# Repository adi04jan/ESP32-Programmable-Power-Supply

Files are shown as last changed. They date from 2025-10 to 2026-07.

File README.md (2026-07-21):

# Voltbench — ESP32-C3 Programmable Power Supply

A three-channel bench power supply controlled over Wi-Fi, built around an **ESP32-C3 Super Mini**. The variable channel uses an LM2596-ADJ buck converter set by an MCP4017 I2C digital potentiometer, driven by a calibration-map "deadbeat" controller: it jumps to the mapped wiper step, verifies with one filtered ADC sample, applies at most one single-step correction, and freezes — no hunting, settled in under a second. Two fixed rails deliver regulated 5 V and 3.3 V. Everything is managed through a dark-themed responsive web UI served directly from the microcontroller — no app, no cloud, no dependencies.

Designed and developed by **Aditya Biswas**.

---

## Screenshots

| Dashboard | History | Settings |
|---|---|---|
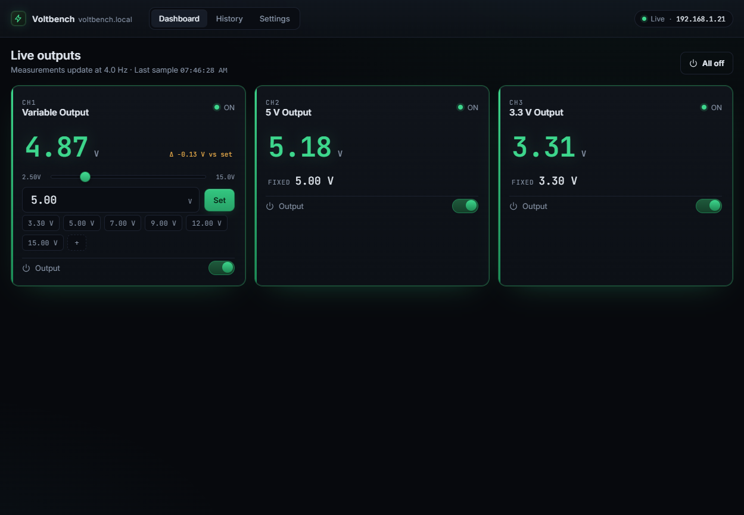
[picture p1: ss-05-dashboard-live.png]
Dashboard
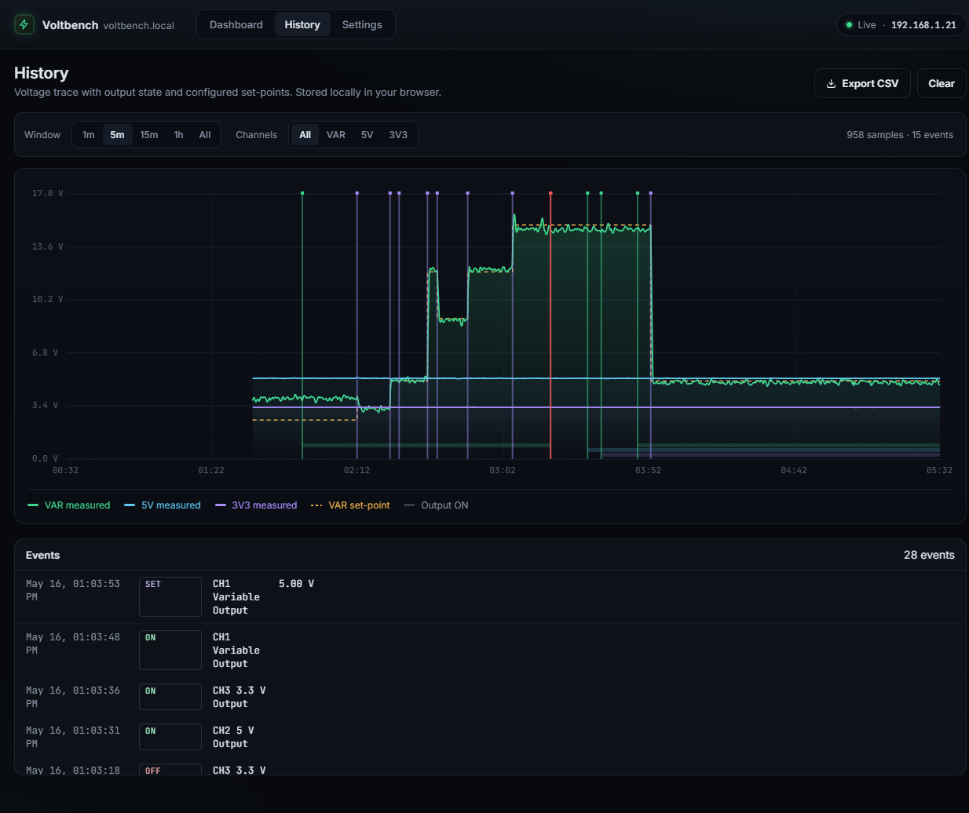
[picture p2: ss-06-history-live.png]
History
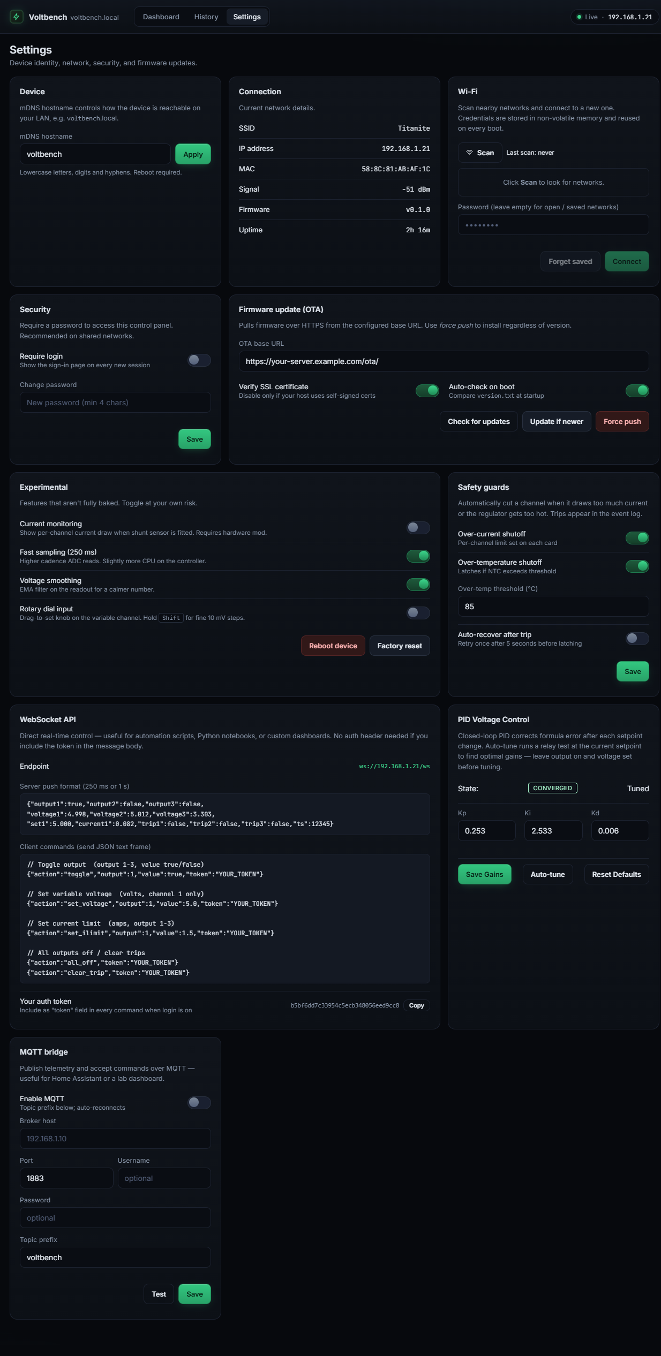
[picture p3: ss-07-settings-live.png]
Settings
|  |  |  |

---

## Features

### Power Outputs
| Channel | Rail | Range | Regulation |
|---|---|---|---|
| CH1 | LM2596-ADJ (variable) | 2.5 V – 15 V | map-based deadbeat control + on-device calibration sweep |
| CH2 | Mini360 (fixed 5 V) | 5.0 V | Passthrough (monitor only) |
| CH3 | LM1117-3.3 (LDO, fixed) | 3.3 V | Passthrough (monitor only) |

### Accuracy (measured, after calibration sweep)
| Setpoint | Measured | Error |
|---|---|---|
| 3.3 V | 3.22 V | −80 mV (2.4%) |
| 5.0 V | 4.99 V | −10 mV (0.2%) |
| 9.0 V | 8.98 V | −20 mV (0.2%) |
| 12.0 V | 12.29 V | +290 mV (2.4%) |
| 15.0 V | 15.55 V | +550 mV (3.7%) |

> Accuracy is limited by wiper-step quantization (~27 mV/step at low voltages, up to ~1 V/step near the ceiling). Run Settings → Calibration → Run sweep once after assembly (CH1 unloaded).

### Web UI
- **Dashboard** — live voltage at 4 Hz, per-channel enable toggles, voltage slider, preset chips (right-click to delete, ＋ to save current), delta indicator, All Off button
- **History** — bezier-smoothed time-series graph with SMA noise reduction, channel filters, event markers (output on/off), adjustable time window (1 min – 12 h)
- **Settings** — mDNS hostname, security/login, Wi-Fi management (scan/connect/forget, stores up to 4 SSIDs), OTA update, experimental flags (dial mode, EMA smoothing, fast poll), MQTT bridge
- **Calibration card** — run/clear the CH1 calibration sweep and see whether a valid map is loaded
- **Device log pane** — live firmware log streamed over a view-only WebSocket (`/logws`)
- **Web-upload OTA** — flash a `.bin` straight from the browser, with real upload/flash progress

### Connectivity
- **WebSocket** `/ws` — server pushes full status JSON at up to 4 Hz; also accepts control commands
- **REST API** — full control and configuration via `/api/*` endpoints
- **mDNS** — reachable at `http://voltbench.local/` on any mDNS-capable host (Windows, macOS, Linux, iOS)
- **Captive portal** — automatically falls back to AP mode (`VoltbenchAP`) when no saved Wi-Fi connects; re-tries every 30 s
- **Telnet console** (`:23`) and USB serial console — single-letter commands: `v<volts>` set CH1, `o1`/`o0` output on/off, `m` run calibration sweep, `c` cal status, `?` full state dump

### Management
- **OTA update** — pulls firmware from this repo's GitHub "latest release" assets on demand or auto-check on boot; web-upload OTA as a second, USB-free path
- **NVS persistence** — all settings, the CH1 calibration map, and Wi-Fi credentials survive power cycles and OTA updates
- **MQTT bridge** — publishes 1 Hz telemetry; subscribes to control topics
- **Factory reset** — wipes all NVS from Settings → Factory Reset
- **Token auth** — optional bearer-token login (stored in `sessionStorage`, persists across reboots)

---

## Hardware

### Bill of Materials

| Component | Part | Notes |
|---|---|---|
| MCU | ESP32-C3 Super Mini | 4 MB flash, Wi-Fi 802.11 b/g/n |
| Variable regulator | LM2596-ADJ module | Adjustable buck, ~3–35 V input |
| Fixed 5 V | Mini360 module | Fixed-output synchronous buck |
| Fixed 3.3 V | LM1117-3.3 | LDO, TO-92 or SOT-223 |
| Digital pot | MCP4017T-103E/LT | 10 KΩ, 128 steps, I2C @ 0x2F |
| R1 (feedback) | 10 KΩ 1% | VOUT → FB (ADJ) on LM2596 |
| R_adc_top | 47 KΩ | CH1 ADC voltage divider high-side |
| R_adc_bot | 1 KΩ | CH1 ADC voltage divider low-side |
| R_5v / R_3v3 | 10 KΩ × 4 | CH2 and CH3 ADC dividers (÷2 each) |
| Enable switches | N-ch MOSFET or relay × 3 | Logic-level control from GPIO 5/6/7 |

### Pin Map

| GPIO | Function |
|---|---|
| 0 | ADC CH1 — variable rail (47K:1K divider, ×48 scale) |
| 1 | ADC CH2 — 5 V rail (10K:10K divider, ×2 scale) |
| 3 | ADC CH3 — 3.3 V rail (10K:10K divider, ×2 scale) |
| 5 | Enable CH1 (variable output) |
| 6 | Enable CH2 (5 V output) |
| 7 | Enable CH3 (3.3 V output) |
| 8 | I2C SDA → MCP4017 |
| 9 | I2C SCL → MCP4017 |

### LM2596-ADJ Feedback Network

```
VOUT ──── 10 KΩ ──── FB (ADJ) ──── MCP4017 wiper ──── GND
                                     (0 – 10 KΩ)
```

`Vout = 1.235 × (1 + 10 000 / R2)` where R2 is the MCP4017 resistance.

| Target | R2 needed | MCP4017 step |
|---|---|---|
| 2.5 V | 9.87 KΩ | 125 / 127 |
| 5.0 V | 3.27 KΩ | 41 / 127 |
| 9.0 V | 1.56 KΩ | 20 / 127 |
| 12.0 V | 1.13 KΩ | 14 / 127 |
| 15.0 V | 0.87 KΩ | 11 / 127 |

### CH1 ADC Divider

```
VOUT ──── 47 KΩ ──── GPIO0 ──── 1 KΩ ──── GND
                       ↑
                  ADC reads here (0 – 2.5 V with ADC_11db)
                  Scale factor = 48 → supports up to ~27 V
```

---

## Firmware

### Prerequisites

- **Arduino IDE 2.x** with ESP32 Arduino core (Espressif) v3.x
- Libraries (Library Manager):
  - `ESPAsyncWebServer` + `AsyncTCP`
  - `ArduinoJson` v7
  - `PubSubClient` *(only if MQTT is needed)*

  (The MCP4017 digital pot is driven with direct I2C register writes — no digital-pot library needed.)

### Build & Flash

1. Clone the repository:
   ```sh
   git clone https://github.com/your-username/ESP32-Programmable-Power-Supply.git
   ```

2. Edit `ESP32_power_supply/credential.h` with your Wi-Fi credentials (these only seed NVS the first time — if any SSID slot is already saved, they're ignored):
   ```cpp
   static const char *ssids[]     = { "YourSSID" };
   static const char *passwords[] = { "YourPassword" };
   ```
   OTA is not configurable here — it's pinned to this repo's GitHub "latest release" assets (see [OTA Updates](#ota-updates)).

3. In Arduino IDE, set:
   - Board: `ESP32C3 Dev Module`
   - Upload Speed: `921600`
   - Flash Size: `4MB`
   - Partition Scheme: **Custom** → select `ESP32_power_supply/partitions.csv`

4. Upload: **Sketch → Upload** (`Ctrl+U`)

5. Open Serial Monitor at **115200 baud** — you should see:
   ```
   Voltbench v3.0.0 booting...
   MCP4017 OK @ 0x2F
   Joined YourSSID — IP=192.168.x.x
   URL: http://voltbench.local/
   ```

6. Open `http://voltbench.local/` in any browser on the same network.

### Partition Layout

```
nvs        20 KB   Settings and Wi-Fi credentials
otadata     8 KB   OTA slot tracking
app0     1792 KB   Active firmware (~1.3 MB used)
app1     1792 KB   OTA staging slot
spiffs    448 KB   Reserved
```

### Regenerating the Web UI

After editing `new design/Power Supply.html`, run this PowerShell snippet to rebuild `web_page.h`:

```powershell
$html  = Get-Content "new design\Power Supply.html" -Raw -Encoding utf8
$bytes = [System.Text.UTF8Encoding]::new($false).GetBytes($html)
$ms    = [System.IO.MemoryStream]::new()
$gz    = [System.IO.Compression.GzipStream]::new($ms, [System.IO.Compression.CompressionLevel]::Optimal)
$gz.Write($bytes, 0, $bytes.Length); $gz.Close()
$gzBytes = $ms.ToArray()
$chunks  = for ($i = 0; $i -lt $gzBytes.Length; $i += 16) {
    "  " + (($gzBytes[$i..([Math]::Min($i+15,$gzBytes.Length-1))] |
    ForEach-Object { "0x{0:x2}" -f $_ }) -join ", ")
}
$header = @("#pragma once","const uint8_t index_html_gz[] PROGMEM = {",
            ($chunks -join ",`n"),"};",
            "const size_t index_html_gz_len = $($gzBytes.Length);")
[System.IO.File]::WriteAllLines("ESP32_power_supply\web_page.h", $header,
    [System.Text.UTF8Encoding]::new($false))
Write-Host "Done: $($bytes.Length) -> $($gzBytes.Length) bytes"
```

---

## Usage

### Calibration

On first flash CH1 has no calibration map, so the deadbeat controller falls back to a coarse built-in estimate. For rated accuracy, run the sweep once:

1. **Disconnect any load from CH1** — the sweep drives the output across its full range (~2.5 V → ceiling) and needs the rail unloaded to read clean.
2. In **Settings → Calibration**, click **Run sweep**. It steps the MCP4017 through all 128 positions, sampling each one — takes about a minute. The busy state is reported as `"busy"` in `/api/status` and rejects a second sweep request while running.
3. The resulting step→millivolt map is smoothed to be monotonic, marked valid, and persisted to NVS — it survives reboots and OTA updates (NVS is a separate flash partition the OTA slot swap never touches).

Re-run the sweep only if the hardware changes (different MCP4017, feedback resistor, or LM2596 module). Use **Clear** to wipe the map and fall back to the coarse estimate.

### Presets

- **Click** a preset chip to jump to that voltage instantly.
- **Right-click** a chip to delete it.
- **＋** saves the current slider position as a new preset (stored in browser `localStorage`).

### All Off

The **All off** button in the top-right cuts all three outputs simultaneously. Individual toggles restore each channel independently.

---

## REST API

All responses are JSON. When `require_login` is enabled, include header `X-Auth: <token>` on every request except `/api/login`.

| Method | Path | Description |
|---|---|---|
| `GET` | `/api/status` | Live voltages and controller state |
| `GET` | `/api/info` | Device info, network, settings |
| `POST` | `/api/login` | `pass=…` → `{ok, token}` |
| `POST` | `/api/control` | Outputs and voltage (see below) |
| `POST` | `/api/settings` | JSON — any subset of settings |
| `GET` | `/api/wifi/scan` | Start scan → returns networks |
| `POST` | `/api/wifi/connect` | `ssid=…&pass=…` |
| `POST` | `/api/wifi/forget` | `ssid=…` |
| `GET` | `/api/ota/check` | Check GitHub for newer firmware (async: `202 {"checking":true}` while in flight) |
| `POST` | `/api/ota/update` | Pull from GitHub if newer |
| `POST` | `/api/ota/force` | Pull from GitHub unconditionally |
| `POST` | `/api/ota/upload` | Multipart `.bin` upload → flashes the inactive OTA slot, reboots on success |
| `POST` | `/api/cal/sweep` | Start the CH1 calibration sweep (`409` if the controller is already busy) |
| `GET` | `/api/cal/status` | `{valid, running, mv:[128 values]}` |
| `POST` | `/api/cal/clear` | Wipe the calibration map |
| `GET` | `/api/mqtt/test` | Test broker connectivity |
| `POST` | `/api/reboot` | Restart device |
| `POST` | `/api/factory_reset` | Wipe NVS |

**`/api/control` actions** (form-encoded POST body):
```
action=toggle&output=1&value=1
action=set_voltage&output=1&value=5.0
action=all_off
```

**`/api/status` example:**
```json
{
  "output1": true,  "output2": false, "output3": false,
  "voltage1": 4.99, "voltage2": 5.17, "voltage3": 3.31,
  "set1": 5.0,
  "cal": true,
  "state": "frozen",
  "ts": 8040468
}
```

`state`: `idle` | `settling` | `verifying` | `frozen` | `busy` (`busy` = calibration sweep in progress). `voltage1` is the median-of-5 display value; `cal` reports whether a valid calibration map is loaded.

`/api/info` unauthenticated returns `{fw, mdns, require_login, captive}`; with a valid token it adds `ip, mac, ssid, rssi, uptime, ota:{auto}, exp:{fast,smooth,dial}, mqtt:{…}, saved_ssids, vmax`.

---

## WebSocket

Connect to `ws://voltbench.local/ws`.

The server **pushes** a full status frame automatically — every 250 ms with the fast-poll flag on, every 1 s otherwise — no subscription needed. `ws://voltbench.local/logws` is a second, view-only socket that streams the live firmware debug log (used by the Device log pane).

**Send a control command:**
```json
{ "action": "set_voltage", "output": 1, "value": 9.0 }
{ "action": "toggle",      "output": 1, "value": true }
{ "action": "all_off" }
```

When `require_login` is on, include `"token": "<token>"` in every command.

**Quick test (browser console):**
```js
const ws = new WebSocket('ws://voltbench.local/ws');
ws.onmessage = e => console.log(JSON.parse(e.data));
ws.onopen    = () => ws.send(JSON.stringify({action:'set_voltage', output:1, value:5.0}));
```

---

## MQTT

Enable in **Settings → MQTT**. Configure broker host, port, credentials, and topic prefix.

| Topic | Direction | Payload |
|---|---|---|
| `voltbench/tele` | Publish (1 Hz) | Full JSON telemetry (same shape as `/api/status`) |
| `voltbench/status` | Publish (retained, on connect) | `online` |
| `voltbench/cmd/ch1/output` | Subscribe | `on` / `off` / `1` / `0` |
| `voltbench/cmd/ch2/output` | Subscribe | `on` / `off` / `1` / `0` |
| `voltbench/cmd/ch3/output` | Subscribe | `on` / `off` / `1` / `0` |
| `voltbench/cmd/ch1/voltage` | Subscribe | Float string, e.g. `5.0` — clamped to `[0, 16]`, invalid channels/values are silently ignored |

The prefix `voltbench` is configurable in Settings → MQTT → Topic prefix. Only CH1 accepts a voltage command (CH2/CH3 are fixed rails); toggling CH2/CH3 output is still valid.

---

## OTA Updates

Two independent paths, no local server required:

1. **Pull-OTA from GitHub** — the base URL is pinned in firmware to this repo's `/releases/latest/download/` assets (HTTPS, **without** certificate verification — `WiFiClientSecure::setInsecure()` is used deliberately; there's no local CA store on this MCU, and this is an accepted trade-off, not an oversight). The device fetches `version.txt`, compares it to `CURRENT_FIRMWARE_VERSION`, and — on `/api/ota/update`, `/api/ota/force`, or the optional auto-check on boot — downloads `firmware_<version>.bin` into the inactive OTA slot and reboots on success. To ship a release: tag it, then attach `version.txt` and `firmware_<version>.bin` to the GitHub release; `/releases/latest/download/` resolves automatically.
2. **Web-upload OTA** — `POST` a compiled `.bin` to `/api/ota/upload` (multipart, e.g. `curl -H "X-Auth: <token>" -F "f=@ESP32_power_supply.ino.bin" http://voltbench.local/api/ota/upload`), or use the **Update** button in Settings for the same flow with a progress bar. No GitHub, no USB.

Either path rejects a second update while one is already running (logged as `busy`).

---

## Architecture

```
┌────────────────────────────────────────────────────┐
│  ESP32-C3  (FreeRTOS, single physical core)        │
│                                                    │
│  ┌──────────────────────┐  volatile globals         │
│  │  voltageControlTask  │◄────────────────────────┐ │
│  │  (priority 2, core 0)│  g_target_mV            │ │
│  │                      │  g_setpoint_mV          │ │
│  │  deadbeat state      │  g_measured_mV          │ │
│  │  machine: idle →     │  g_display_mV  ────────►│ │
│  │  settling → verify   │  g_5v_mV / g_3v3_mV     │ │
│  │  → frozen (or busy   │  g_vctrl_state          │ │
│  │  during cal sweep)   │  g_cal_mv[128] / valid  │ │
│  │  ADC reads (all 3    │                         │ │
│  │  rails) + I2C pot    │                         │ │
│  └──────────────────────┘                         │ │
│                                                   │ │
│  ┌──────────────────────┐                         │ │
│  │  AsyncWebServer      │─────────────────────────┘ │
│  │  ESPAsyncWebServer   │  Reads the globals above  │
│  │                      │  Writes g_target_mV       │
│  │  /api/* handlers     │                           │
│  │  WebSocket push      │                           │
│  └──────────────────────┘                           │
│                                                     │
│  loop():  vb_loop()                                 │
│     DNS captive · WS push · MQTT · OTA · console    │
└────────────────────────────────────────────────────┘
        │ I2C                │ ADC_11db
    MCP4017 @ 0x2F        GPIO 0 / 1 / 3
    10 KΩ, 128 steps      ×48 / ×2 / ×2
        │
   LM2596-ADJ
   feedback R2
```

**Key design decisions:**
- `voltageControlTask` owns ALL ADC sampling (all three rails) and the I2C pot; web handlers read atomically-written globals only. Status reads use `g_display_mV`, a median-of-5 window snapped on freeze for a calm steady-state number.
- The controller is a calibration-map deadbeat, not a feedback loop: predict the wiper step from `g_cal_mv[]`, wait 300 ms to settle, take one ~200 ms filtered verify sample, apply at most one ±1-step correction, then freeze (`g_vctrl_state`: idle → settling → verifying → frozen). No PID, no hunting, no per-cycle recomputation — settled in under a second across the full range. Without a calibration map it falls back to a coarse built-in R↔step estimate.
- The web UI is a single gzip-compressed HTML file (~23 KB) served directly from PROGMEM — no filesystem partition required.

---

## Troubleshooting

| Symptom | Cause | Fix |
|---|---|-----|
| `voltbench.local` not resolving | mDNS client issue | Try IP directly; Android needs an mDNS helper app |
| Voltage shows 0 V with output OFF | Expected — enable pin cuts power | Toggle output ON |
| CH1 settles far from setpoint | No calibration map — coarse fallback estimate in use | Run Settings → Calibration → Run sweep (CH1 unloaded) |
| OTA "check" never returns `newer` | No release published yet, or `version.txt`/`.bin` missing from the GitHub release | Confirm the tag's release has both assets attached |
| `MCP4017 not found!` at boot | I2C wiring | Check SDA/SCL and pull-up resistors (4.7 KΩ to 3.3 V) |
| Sketch too large to upload | Wrong partition scheme | Select Custom and point to `partitions.csv` |
| Settings revert after save | Browser cached old page | Hard-refresh (`Ctrl+Shift+R`) |

---

## License

MIT — see [LICENSE](LICENSE).

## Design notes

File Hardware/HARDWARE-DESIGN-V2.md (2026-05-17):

# Voltbench v2 — Hardware Design

> Two-channel programmable bench power supply.  
> Input: 24 V DC SMPS · Output: 2.8 V – 20 V · 3 A per channel  
> Control: ESP32-C3 · I²C DAC (MCP4728) · Discrete PMOS LDO · INA219 sensing

---

## Table of Contents

1. [Why v2?](#why-v2)
2. [System Overview](#system-overview)
3. [Stage 1 — Coarse Voltage (MP1584 + MCP4728)](#stage-1--coarse-voltage-mp1584--mcp4728)
4. [Stage 2 — Precision LDO (FQP27P06 + LM358)](#stage-2--precision-ldo-fqp27p06--lm358)
5. [Stage 3 — Measurement (INA219)](#stage-3--measurement-ina219)
6. [Complete Single-Channel Schematic](#complete-single-channel-schematic)
7. [Two-Channel Full System](#two-channel-full-system)
8. [I²C Address Map](#i2c-address-map)
9. [Power Budget](#power-budget)
10. [Thermal Design](#thermal-design)
11. [Bill of Materials](#bill-of-materials)
12. [PCB Design Notes (0.25 mm CNC)](#pcb-design-notes-025-mm-cnc)
13. [Firmware Interface](#firmware-interface)
14. [System Specifications](#system-specifications)

---

## Why v2?

### Problems with v1 (LM2596 + MCP4017)

| Problem | Root Cause | Impact |
|---|---|---|
| ±400–800 mV voltage error | MCP4017 has 128 steps × 78.7 Ω/step | Cannot hit target precisely |
| PID loop needed | Step size larger than tolerance band | Slow settling, overshoot risk |
| No current measurement | No sense circuit | Cannot display watts or enforce OCP |
| Noisy ADC readings | ESP32-C3 internal ADC non-linearity | Inaccurate voltage display |
| 75% efficiency | LM2596 150 kHz non-synchronous switcher | Heat, large inductor/caps |

### v2 Solution

```
v1:  LM2596 (variable R2 via MCP4017)  →  ±400 mV error, slow PID
v2:  MP1584 (DAC FB injection)         →  coarse set, instant, ~3 mV resolution
     + PMOS LDO (op-amp regulated)     →  fine regulation, 2–5 mV ripple
     + INA219                          →  accurate V + I measurement
```

---

## System Overview

```
                       24V DC SMPS
                            │
              ┌─────────────┼─────────────┐
              │             │             │
              ▼             ▼             ▼
          [CHANNEL 1]   [CHANNEL 2]   [ESP32-C3]
                                          │
                                     I²C Bus (SDA/SCL)
                                     ┌────┴──────┐
                                  MCP4728      INA219×2
                                  (0x60)    (0x40, 0x41)
```

### Per-Channel Signal Flow

```
24V ──► [MP1584 Buck] ──► [FQP27P06 PMOS] ──► OUTPUT TERMINAL
              ▲                   ▲
              │ FB injection       │ Gate drive
         MCP4728 Ch A          LM358 op-amp ◄── MCP4728 Ch B
         (coarse set)          (fine regulate)        (reference)
                                      ▲
                               Vout feedback
                               divider (10k/51k)
                                      │
                               ──[0.1Ω shunt]──
                                      │
                                  INA219
                                (V + I sense)
```

---

## Stage 1 — Coarse Voltage (MP1584 + MCP4728)

### How It Works

The MP1584 is a synchronous buck converter with an adjustable output set by its FB (feedback) pin. Normally R1 and R2 form a divider to set output voltage. We **inject current from the MCP4728 DAC through R3** into the FB node, which shifts the output voltage continuously and linearly.

The FB pin is always regulated to **Vref = 0.8 V** by the MP1584's internal error amplifier. Injecting current via R3 forces the converter to change Vout to maintain that 0.8 V at FB.

### Feedback Network Schematic

```
                          MP1584
                         ┌──────┐
              ┌──────────┤ FB   │
              │          └──────┘
              │
Vout_mp1584 ──┤──[R1 = 100 kΩ]──┐
              │                   │
              ├──[R2 = 6.8 kΩ]── GND
              │
              └──[R3 = 24.3 kΩ]──── MCP4728 Channel A (0–3.3 V)
```

### Transfer Function

```
Vout = 0.8 × (1 + R1/R2 + R1/R3)  −  Vdac × (R1/R3)

With R1=100k, R2=6.8k, R3=24.3k:
  Vout = 16.0  −  4.09 × Vdac
```

### DAC Code to Output Voltage

```
Vdac = (16.0 − Vout_target) / 4.09
DAC_code = round(Vdac × 4096 / 3.3)
```

| Target Vout + 0.5V | Vdac | DAC Code |
|---|---|---|
| 20.5 V | 0.00 V | 0 |
| 15.5 V | 0.12 V | 1218 |
| 12.5 V | 0.49 V | 1211 (coarse MP1584 target) |
| 9.5 V | 1.59 V | 1973 |
| 5.5 V | 2.56 V | 3176 |
| 3.3 V | 3.10 V | 3846 |

> MP1584 is set to **Vtarget + 0.5 V** — the LDO stage drops the final 0.5 V precisely.

### MP1584 Support Components

```
               24V
                │
           [10µF ceramic]  ← Input decoupling
                │
         ┌──────┴──────┐
         │   MP1584    │
    EN ──┤EN       OUT ├──┬──[L1: 4.7µH]──┬── To PMOS source
         │             │  │               │
         │         SW  ├──┘            [C1: 22µF] ← Output cap
         │             │               ceramic
         └──────┬──────┘               │
               GND                    GND
                         [D1: SS34 Schottky] ← Freewheeling diode
                         (SW to GND, for transient protection)
```

| Component | Value | Notes |
|---|---|---|
| L1 | 4.7 µH, 4A rated | Smaller than LM2596's 100 µH |
| C1 (output) | 22 µF ceramic | MP1584 stability |
| C_in | 10 µF ceramic | Input decoupling |
| D1 | SS34 Schottky | Optional (synchronous but helps transients) |

---

## Stage 2 — Precision LDO (FQP27P06 + LM358)

### How It Works

The PMOS transistor (FQP27P06) sits between the MP1584 output and the final output terminal. An op-amp (LM358) compares a divided-down version of the actual output voltage against a **DAC reference (MCP4728 Channel B)**. It drives the PMOS gate to force the output to exactly match the reference.

This eliminates the MP1584's ±1% Vref tolerance error, load regulation error, and most of the switching ripple.

### LDO Schematic

```
MP1584 out (Vtarget+0.5V)
        │
        ├── PMOS Source (FQP27P06 pin 3)
        │
        │       FQP27P06 (P-Channel MOSFET)
        │      ┌─────────────┐
        └──────┤ S           │
               │    D        ├──────────────┬── Vout (clean)
               │             │              │
               └─────────────┘          [100µF]   [10µF]
                      │ G                   │         │
                   [100Ω]                  GND       GND
                      │
               ┌──────┴──────┐
               │   LM358     │
               │  op-amp     │
         Vfb ──┤ −IN   OUT   ├── Gate drive
               │             │
  DAC ref ─────┤ +IN         │
               └─────────────┘
                      │
                     GND (op-amp GND)
                     Vcc = 24V (op-amp supply)

Vfb comes from output voltage divider:

Vout ──[Ra = 10 kΩ]──┬── to op-amp −IN
                      │
                   [Rb = 51 kΩ]
                      │
                     GND
```

### Transfer Function

```
Op-amp null condition (Vout settled):
  DAC_ref = Vout × Ra / (Ra + Rb)

Solving for Vout:
  Vout = DAC_ref × (Ra + Rb) / Ra
       = DAC_ref × (10k + 51k) / 10k
       = DAC_ref × 6.1

DAC code for target:
  DAC_ref = Vout_target × 10 / (10 + 51)  = Vout_target × 0.1639
  DAC_code = round(DAC_ref × 4096 / 3.3)
```

| Target Vout | DAC Ref | DAC Code |
|---|---|---|
| 20.0 V | 3.28 V | 4070 |
| 15.0 V | 2.46 V | 3052 |
| 12.0 V | 1.97 V | 2446 |
| 9.0 V | 1.47 V | 1827 |
| 5.0 V | 0.82 V | 1018 |
| 3.3 V | 0.54 V | 671 |
| 2.8 V | 0.46 V | 571 |

### Why PMOS and Not NPN/NMOS?

```
NPN/NMOS (source follower):
  Vout = Vgate − Vgs_threshold   ← output always lower than gate
  Hard to use at high side without charge pump

PMOS (common source, source at top):
  Source = Vin (high side)
  Gate pulled LOW turns it ON
  Op-amp can drive gate from 0V (full ON) to 24V (full OFF)
  No charge pump needed ✓
```

### Op-Amp Operating Range Check (LM358 at 24V supply)

```
Source voltage: 0.5V to 20.5V (MP1584 output range)
Gate must swing BELOW source to turn ON:
  At Vsource = 20.5V: gate needs to go to ~17V (Vgs = -3.5V → fully ON)
  LM358 output max = Vcc - 1.5V = 22.5V  > 20.5V ✓ (can turn OFF)
  LM358 output min = 0V  <  17V needed to turn ON  ✓

At Vsource = 3.3V: gate needs ~1V to fully ON
  LM358 output = 0 to ~22.5V  →  easily covers 0–1V ✓
```

### Dropout Voltage

```
Vdropout = Rdson × Iout
         = 0.070 Ω × 3 A  =  0.21 V  (typical)
         = 0.100 Ω × 3 A  =  0.30 V  (worst case, warm)

MP1584 headroom set to 0.5V → leaves 0.2–0.3V regulation margin ✓
```

---

## Stage 3 — Measurement (INA219)

### How It Works

The INA219 measures both **bus voltage** (actual output voltage, 4 mV resolution) and **shunt current** (via 0.1 Ω resistor, 1 mA resolution) over I²C. This replaces the ESP32's internal ADC entirely.

### Connection

```
                 Vout (before shunt)
                         │
                    ┌────┴────┐
                    │ INA219  │
                    │         │
              IN+ ──┤         ├── SDA ── I²C Bus
              IN− ──┤         ├── SCL ── I²C Bus
                    │         ├── VCC ── 3.3V
                    │         ├── GND ── GND
                    │    A0   ├── (address select)
                    │    A1   ├── (address select)
                    └─────────┘
                         │
                    [0.1 Ω shunt, 1W, 2512]
                         │
                    Output Terminal (+)
```

### Address Configuration

| Channel | A0 | A1 | I²C Address |
|---|----|----|---|
| Ch 1 | GND | GND | 0x40 |
| Ch 2 | VCC | GND | 0x41 |

### INA219 Calibration Register

```
For 0.1 Ω shunt, max 3.2 A, current LSB = 100 µA:
  Cal = 0.04096 / (Current_LSB × Rshunt)
      = 0.04096 / (0.0001 × 0.1)
      = 4096

Write 0x1000 to calibration register.
```

---

## Complete Single-Channel Schematic

```
                             24V DC SMPS
                                  │
          ┌───────────────────────┼────────────────────────────────┐
          │                       │                                │
       [10µF]                     │                             [100nF]
          │                       │                                │
         GND                      │                               GND
                                  │
                    ┌─────────────┴──────────────────┐
                    │           MP1584                │
         GPIO_EN ───┤ EN                              │
                    │                            IN   ├── 24V
          ┌─────────┤ FB                              │
          │         │                         SW      ├──┐
          │         └─────────────────────────────────┘  │
          │                                               │
          │  Feedback Network:                         [L1: 4.7µH, 4A]
          │                                               │
Vmp ──────┼──[R1: 100kΩ]──────── Vout_mp1584 ────────────┤
          │                          (Vtgt+0.5V)          │
          ├──[R2: 6.8kΩ]──── GND                      [C1: 22µF]
          │                                               │
          └──[R3: 24.3kΩ]─── MCP4728 Ch A (coarse)      GND
                                                          │
                                               Vout_mp1584 (Vtgt+0.5V)
                                                          │
                                           ┌──────────────┘
                                           │ Source
                                    ┌──────┴──────┐
                                    │  FQP27P06   │ (P-Ch MOSFET)
                                    │  TO-220     │
                                    └──────┬──────┘
                                           │ Drain
                              ┌────────────┼────────────┐
                              │            │            │
                           [100µF]      [10µF]       [100nF]
                              │            │            │
                             GND          GND          GND
                              │
                         Vout_clean
                              │
                   ┌──────────┴──────────┐
                   │                     │
              [Ra: 10kΩ]         [0.1Ω shunt, 1W]
                   │                     │
              [Rb: 51kΩ]          Output Terminal (+)
                   │
                  GND               ┌────────────────┐
                   │                │    INA219      │
              Vfb (0–3.3V)    IN+ ──┤                ├── SDA
                   │          IN- ──┤  0x40 / 0x41   ├── SCL
                   │                │                ├── 3.3V
                   │               GND               └────────────────┘
                   │
            ┌──────┴──────────┐
            │    LM358        │
            │   (Vcc = 24V)   │
     Vfb ───┤ −IN    OUT      ├──[100Ω]── Gate (FQP27P06)
            │                 │
DAC_ref ────┤ +IN             │
(MCP4728    │                 │
   Ch B)    └─────────────────┘
                   │
       [10nF cap from OUT to −IN for stability]
```

---

## Two-Channel Full System

```
                              24V DC SMPS
                                   │
            ┌──────────────────────┼──────────────────────┐
            │                      │                      │
     ┌──────┴──────┐        ┌──────┴──────┐        ┌──────┴──────┐
     │  CHANNEL 1  │        │  CHANNEL 2  │        │  ESP32-C3   │
     │             │        │             │        │             │
     │  MP1584     │        │  MP1584     │        │  SDA ───────┼──┐
     │  FQP27P06   │        │  FQP27P06   │        │  SCL ───────┼──┤
     │  LM358      │        │  LM358      │        │  GPIO5 ─────┼──┼── EN_CH1
     │  INA219     │        │  INA219     │        │  GPIO6 ─────┼──┼── EN_CH2
     │  (0x40)     │        │  (0x41)     │        └─────────────┘  │
     └──────┬──────┘        └──────┬──────┘                         │
            │ SDA/SCL              │ SDA/SCL                         │
            └──────────────────────┴─────────────────────────────────┘
                                   │
                              I²C Bus
                                   │
                           ┌───────┴───────┐
                           │   MCP4728     │  SOIC-10
                           │   (0x60)      │
                           │               │
                    Ch A ──┤               ├── SDA
                    Ch B ──┤               ├── SCL
                    Ch C ──┤               ├── VCC (3.3V)
                    Ch D ──┤               ├── GND
                           └───────────────┘
                             │    │    │    │
                          MP1584 LDO MP1584 LDO
                           ref   ref   ref  ref
                           Ch1   Ch1   Ch2  Ch2
```

### MCP4728 Channel Assignment

| MCP4728 Ch | Function | Target IC | What it controls |
|---|---|---|---|
| A | Ch1 Coarse | MP1584 #1 | Sets MP1584 out to Vtarget + 0.5V |
| B | Ch1 Fine | LM358 #1 | Sets exact Vtarget for LDO |
| C | Ch2 Coarse | MP1584 #2 | Sets MP1584 out to Vtarget + 0.5V |
| D | Ch2 Fine | LM358 #2 | Sets exact Vtarget for LDO |

---

## I²C Address Map

| IC | Address | Set by | Notes |
|----|---|---|---|
| MCP4728 | 0x60 | Factory (A0T variant) | Quad DAC |
| INA219 Ch1 | 0x40 | A0=GND, A1=GND | Voltage + current Ch1 |
| INA219 Ch2 | 0x41 | A0=VCC, A1=GND | Voltage + current Ch2 |

No address conflicts. All four ICs on a single SDA/SCL pair.

---

## Power Budget

### SMPS Sizing

```
Per channel, worst case (3A at any voltage):
  Stage 1 (MP1584):
    Vin=24V, Vout=20.5V, Iout=3A
    Pout = 20.5 × 3 = 61.5W
    Pin  = 61.5 / 0.93 = 66.1W
    Ploss = 4.6W  (MP1584 gets warm — copper pour heatsink on PCB)

  Stage 2 (PMOS LDO):
    Pdrop = (20.5 − 20.0) × 3 = 1.5W  (always 0.5V × Iout)

  Per channel total: 66.1W input from 24V
  Two channels max: 132W

Minimum SMPS: 24V / 6A = 144W
Recommended SMPS: 24V / 7A = 168W (Mean Well LRS-150-24 or equivalent)
```

### Typical Operating Power

```
Both channels at 5V / 1A each (common bench use):
  MP1584: (5.5 × 1) / 0.93 = 5.9W per channel
  PMOS:   0.5 × 1 = 0.5W per channel
  Total input: ~13W from 24V rail → 0.54A from SMPS
  A 24V/2A adapter is enough for light loads
```

---

## Thermal Design

### FQP27P06 (PMOS)

```
Power dissipated = 0.5V × Iout (constant regardless of output voltage)

At 3A: P = 1.5W per channel
At 1A: P = 0.5W per channel

TO-220 without heatsink: θja = 62°C/W
  At 1.5W: ΔT = 93°C  →  junction = 118°C  ✗ Too hot

TO-220 with small clip heatsink: θja ≈ 15°C/W
  At 1.5W: ΔT = 22°C  →  junction = 47°C  ✓

Recommendation: use a 25×25mm aluminium heatsink with thermal paste.
```

### MP1584

```
Power loss is highest at large Vin-to-Vout ratio:
At Vout=3.3V, Iin_avg ≈ Iout × (Vout/Vin) / η = 3 × (3.3/24) / 0.93 ≈ 0.44A from 24V
MP1584 internal dissipation ≈ 0.6W

At Vout=20V, Iin_avg ≈ 3 × (20.5/24) / 0.93 ≈ 2.76A from 24V
MP1584 internal dissipation ≈ 4.6W  →  needs copper pour (SOIC-8 exposed pad)

Recommendation: Connect SOIC-8 exposed pad to a copper pour of at least 4 cm²
```

### LM358

```
Op-amp quiescent current: ~1mA at 24V = 24mW  →  negligible, no heatsink needed.
```

---

## Bill of Materials

### Per Channel

| Ref | Component | Value / Part | Package | Qty | Notes |
|-----|---|---|---|-----|---|
| U1 | Buck converter | MP1584EN | SOIC-8 | 1 | |
| Q1 | PMOS pass transistor | FQP27P06 | TO-220 | 1 | Needs heatsink |
| U2 | Op-amp | LM358 | SOIC-8 or DIP-8 | 1 | |
| U3 | Current/voltage sense | INA219xAIDR | SOIC-8 | 1 | |
| R1 | FB upper resistor | 100 kΩ 1% | 0805 | 1 | |
| R2 | FB lower resistor | 6.8 kΩ 1% | 0805 | 1 | |
| R3 | DAC injection resistor | 24.3 kΩ 1% | 0805 | 1 | Use 24.3k or 24k |
| Ra | LDO divider upper | 10 kΩ 1% | 0805 | 1 | |
| Rb | LDO divider lower | 51 kΩ 1% | 0805 | 1 | |
| Rg | Gate resistor | 100 Ω | 0805 | 1 | Prevents oscillation |
| Rc | Stability cap resistor | 10 nF | 0805 | 1 | Op-amp feedback cap |
| Rs | Shunt resistor | 0.1 Ω 1W 1% | 2512 | 1 | Current sense |
| L1 | Inductor | 4.7 µH 4A | SMD | 1 | e.g. SRR1260-4R7Y |
| C1 | MP1584 output cap | 22 µF 35V | 0805/1206 ceramic | 1 | |
| C2 | Input decoupling | 10 µF 35V | 1206 ceramic | 1 | |
| C3 | LDO output cap | 100 µF 35V | Electrolytic | 1 | |
| C4 | LDO HF bypass | 10 µF ceramic | 1206 | 1 | In parallel with C3 |
| C5 | LDO HF bypass | 100 nF ceramic | 0805 | 1 | In parallel with C3 |

### Shared (Both Channels)

| Ref | Component | Value / Part | Package | Qty |
|-----|---|---|---|-----|
| U4 | Quad DAC | MCP4728A0T | SOIC-10 | 1 |
| U5 | Microcontroller | ESP32-C3 Super Mini | Module | 1 |
| J1 | Power input | DC barrel or screw terminal 24V | — | 1 |
| J2,J3 | Output terminals | Banana jack or screw terminal | — | 2 |

### Estimated Cost (India)

| Item | Approx Cost |
|---|---|
| MP1584 × 2 | ₹60 |
| FQP27P06 × 2 | ₹80 |
| LM358 × 2 | ₹30 |
| INA219 × 2 | ₹160 |
| MCP4728 | ₹120 |
| Inductors × 2 | ₹80 |
| Resistors + caps | ₹50 |
| Heatsinks × 2 | ₹40 |
| ESP32-C3 | ₹200 |
| PCB (FR4, milled) | ₹0 (self-milled) |
| **Total** | **~₹820** |

---

## PCB Design Notes (0.25 mm CNC)

### Component Package Analysis

| Component | Package | Min pad gap | 0.25mm bit |
|---|---|---|---|
| MP1584 | SOIC-8 | 0.67 mm | ✓ Comfortable |
| INA219 | SOIC-8 | 0.67 mm | ✓ Comfortable |
| MCP4728 | SOIC-10 | 0.67 mm | ✓ Comfortable |
| LM358 | SOIC-8 | 0.67 mm | ✓ Comfortable |
| FQP27P06 | TO-220 | 2.54 mm | ✓ Easy |
| Resistors | 0805 | 0.50 mm | ✓ Fine |
| Shunt Rs | 2512 | 1.50 mm | ✓ Easy |

> All packages are safely within the 0.25 mm bit capability (no SOT-23 ICs in this design).

### PCB Layout Priorities

```
1. Power path (24V → MP1584 → PMOS → output terminal):
   Use 2mm+ track width. Copper pour recommended.

2. MP1584 SW node:
   Keep short and away from analog components.
   The switch node is the noisiest point in the design.

3. INA219 shunt resistor placement:
   Place shunt resistor close to INA219 IN+/IN- pins.
   Kelvin (4-wire) connection if possible for accuracy.

4. LM358 feedback loop:
   Keep Ra/Rb close to op-amp −IN pin.
   Keep 10nF stability cap (Rc) across Rb.

5. Decoupling capacitors:
   Place C_in (10µF) within 3mm of MP1584 IN pin.
   Place C1 (22µF) within 5mm of MP1584 OUT pin.
   Place C3/C4/C5 right at output terminal.

6. I²C bus:
   Keep SDA/SCL tracks short (<10cm).
   Add 4.7kΩ pull-ups to 3.3V if not already on ESP32 module.

7. PMOS heatsink:
   TO-220 mounted to edge of PCB with external heatsink,
   or use PCB copper pour on drain pad if using D2PAK version.
```

### Recommended Track Widths

| Signal | Track Width | Notes |
|---|---|---|
| 24V power | 2.5 mm | Input supply |
| MP1584 output | 2.0 mm | Up to 3A |
| Output terminal | 2.5 mm | Final output |
| SW node | 1.5 mm | Short as possible |
| I²C (SDA/SCL) | 0.4 mm | Signal only |
| FB network | 0.3 mm | High impedance |
| GND copper pour | Full pour | Both layers |

---

## Firmware Interface

### Setting Output Voltage

```cpp
#include <Adafruit_MCP4728.h>
#include <Adafruit_INA219.h>

Adafruit_MCP4728 dac;
Adafruit_INA219 ina[2] = { Adafruit_INA219(0x40),
                            Adafruit_INA219(0x41) };

// Channel index: 0 = Ch1, 1 = Ch2
void set_voltage(uint8_t ch, float target_V) {
    // Coarse: MP1584 set to Vtarget + 0.5V
    float v_coarse = target_V + 0.5f;
    float vdac_c = (16.0f - v_coarse) / 4.09f;
    uint16_t code_c = (uint16_t)constrain(vdac_c * 4096.0f / 3.3f, 0, 4095);

    // Fine: LDO reference = Vtarget × divider ratio
    float vdac_f = target_V * 10.0f / (10.0f + 51.0f);
    uint16_t code_f = (uint16_t)constrain(vdac_f * 4096.0f / 3.3f, 0, 4095);

    // MCP4728: Ch A/C = coarse, Ch B/D = fine
    MCP4728_channel_t ch_coarse = (ch == 0) ? MCP4728_CHANNEL_A : MCP4728_CHANNEL_C;
    MCP4728_channel_t ch_fine   = (ch == 0) ? MCP4728_CHANNEL_B : MCP4728_CHANNEL_D;

    dac.setChannelValue(ch_coarse, code_c);
    dac.setChannelValue(ch_fine,   code_f);
}

// Read actual voltage (V)
float read_voltage(uint8_t ch) {
    return ina[ch].getBusVoltage_V();
}

// Read actual current (mA)
float read_current(uint8_t ch) {
    return ina[ch].getCurrent_mA();
}

// Read power (mW)
float read_power(uint8_t ch) {
    return ina[ch].getPower_mW();
}
```

### Initialization

```cpp
void setup() {
    Wire.begin();

    // Init DAC — set both channels to safe starting point (3.3V output)
    dac.begin(0x60);
    set_voltage(0, 3.3f);
    set_voltage(1, 3.3f);
    // Save to EEPROM so power-up is safe next time
    dac.saveToEEPROM();

    // Init INA219
    ina[0].begin();
    ina[1].begin();
    ina[0].setCalibration_32V_2A();  // or custom calibration
    ina[1].setCalibration_32V_2A();
}
```

### Enable / Disable Outputs

```cpp
#define EN_CH1  5   // GPIO5
#define EN_CH2  6   // GPIO6

void enable_output(uint8_t ch, bool en) {
    digitalWrite(ch == 0 ? EN_CH1 : EN_CH2, en ? HIGH : LOW);
}
```

---

## System Specifications

| Parameter | Value |
|---|---|
| Input voltage | 24 V DC (SMPS) |
| Input current (max, both channels) | 7 A |
| Channels | 2 independent |
| Output voltage range | 2.8 V – 20.0 V |
| Output current (per channel) | 0 – 3 A |
| Output voltage resolution | ~4.9 mV/step |
| Output voltage accuracy | ±5 mV (DC) |
| Output ripple | 2–5 mV pk-pk |
| Load regulation | < 10 mV (0–3A) |
| Line regulation | < 2 mV |
| Current measurement range | 0 – 3.2 A |
| Current resolution | 1 mA |
| Voltage measurement resolution | 4 mV (INA219) |
| Transient response | < 1 ms |
| Efficiency (typical) | 90–93% |
| Control interface | I²C (ESP32-C3) |
| Web interface | Yes (existing Voltbench firmware) |
| OTA updates | Yes (existing firmware) |
| PCB process | 0.25 mm isolation CNC milling |

---

## Key Design Decisions Log

| Decision | Reason |
|---|---|
| MP1584 over LM2596 | 10× smaller passives, 93% vs 75% efficiency, SOIC-8 |
| PMOS LDO over IC LDO | Handles full 2.8–20V range, 210mV dropout, cheapest option |
| FQP27P06 over other PMOS | 60V/27A rated, 70mΩ Rdson, TO-220 (easy to heatsink), available in India |
| MCP4728 (quad) over 4× MCP4725 | One SOIC-10 replaces four SOT-23-5, easier to mill |
| INA219 SOIC-8 over SOT-23 | 0.67mm pad gap vs 0.35mm — comfortable with 0.25mm CNC bit |
| 24V SMPS over transformer | Clean regulated DC, no rectifier capacitors, compact |
| LM358 over TL072 | Single-supply 3–32V operation, 24V compatible, available everywhere |
| 0805 resistors | Balance between solderable size and CNC pad gap |
| Coarse+Fine DAC split per channel | MP1584 handles gross voltage, LDO handles precision — no PID needed |

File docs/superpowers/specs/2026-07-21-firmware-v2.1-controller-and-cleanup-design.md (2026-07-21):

# Voltbench Firmware v2.1 — Deadbeat Controller + Honesty Cleanup

**Date:** 2026-07-21 · **Branch:** release_v2 · **Target version:** 2.1.0

## 1. Goals

1. Output-1 voltage reaches its setpoint **fast (<1 s typical) with no visible hunting**, settling on the nearest achievable wiper step.
2. Steady-state displayed voltage is calm (median-filtered) while the actual output stays frozen.
3. Remove every subsystem that looks functional but isn't (PID, guards, fake currents, dead settings).
4. Fix the correctness/robustness bugs found in the 2026-07-21 full review (Wi-Fi dead-ends, NVS races, input validation, UI dishonesty).
5. UI exposes the features that actually exist (calibration, web-upload OTA, device log) and nothing that doesn't.

### Non-goals (explicit user decisions)

- **No TLS verification for pull-OTA** — stays `setInsecure()`; UI keeps an honest warning line.
- **No current/temperature sensing** — hardware doesn't exist; all related code/UI is deleted, not stubbed.
- No auth hardening beyond the items in §8 (LAN bench-tool threat model).
- No `/logws` auth (view-only log stream; accepted risk, documented).

## 2. Controller — "deadbeat" predict → verify → correct-once

Replaces the ±2-step trim sweep in `voltageControlTask` (ESP32_power_supply.ino). The plant is a quantized resistor (128 steps, ~27 mV/step low range, ~1 V/step near ceiling); nearest-step is the physical accuracy floor, so there is nothing for an integrator to do. All PID code is deleted.

### 2.1 State machine (single legend, used everywhere)

| value | name | meaning |
|---|---|---|
| 0 | idle | no target above DC_V_REF |
| 1 | settling  | step applied (or pre-discharging), waiting for the rail |
| 2 | verifying | taking the verification sample / one-step correction |
| 3 | frozen | wiper locked; sampling only for display |
| 4 | busy | calibration sweep running |

`STATE_STR` in firmware-additions.h and the comment blocks at ino:133 and ino:211 use exactly these names; status JSON reports it as `state` (the UI's PID badge is deleted — the existing Δ-vs-setpoint indicator is the user-facing signal).

### 2.2 Acquisition sequence (on target change, target > DC_V_REF)

1. **Predict:** step = `cal_best_step(target)` if map valid, else `formula_step(target)`; clamp to `overvolt_floor_step(target)` (ceiling = target + 300 mV). The two V→R formula copies are merged into one helper.
2. **Pre-discharge** (unchanged): if measured > target + 300 mV, park at max R until it falls below, then apply the predicted step.
3. **Settle:** 300 ms.
4. **Verify:** one 200 ms filtered sample (`vctrl_sample`); write it into `g_cal_mv[step]` (map self-heals).
5. **Correct once (max):** compute local step spacing from map neighbors. If |error| > spacing/2 AND the ±1 neighbor's mapped value is predicted closer AND it doesn't exceed target + 300 mV → move one step, settle 300 ms, sample, update map. Keep whichever measured step is closer to target without overvolting (prefer the lower-voltage step on tie/overvolt).
6. **Freeze:** wiper never moves again until the target changes. Snap display to the measured value, log `[VCtrl] frozen`.

Typical time: 0.5–0.8 s. Worst case (pre-discharge excluded): ~1.1 s with one correction.

### 2.3 Steady-state display

- Control task keeps sampling every ~250 ms while frozen (no wiper writes).
- `g_display_mV` becomes **median-of-5** of the last filtered samples (replaces EMA) — kills spikes without lag; snapped on freeze so setpoint changes render instantly.
- `voltage1` in /status and WS push = the median value. UI shows **2 decimals** (was 1).
- The control task also samples the 5 V and 3.3 V rails into globals (`g_5v_mV`, `g_3v3_mV`); web handlers read globals instead of calling `analogReadMilliVolts` from the AsyncTCP task (fixes the "sole ADC owner" claim, removes handler latency).

### 2.4 Verification (bench)

- DMM on output 1: step 3.3 → 5 → 9 → 12 → 13.5 V; record settle time and final error; require ≤ 1 s and within one step of target.
- DMM steady-state vs UI reading for 60 s — quantifies real ripple vs ADC noise (informs a future hardware RC, out of scope here).

### 2.5 Deletions

- `pid_autotune()`, `g_pid_kp/ki/kd`, `g_autotune_req`, `g_ctrl_mode`, `g_ctrl_timeout_ms`.
- `/api/pid/tune`, `/api/pid/reset`; `pid`/`ctrl` blocks in `/api/settings` and `/api/info`; `pid_state`/`pid_*`/`ctrl_mode` fields in status.
- NVS keys `pid_kp/ki/kd`, `pid_tun`, `ctrl_mode`, `ctrl_tms` — no longer read/written; orphaned values are harmless and vanish on factory reset.
- UI: entire "PID Voltage Control" card, ctrl-mode dropdown, PID badge handling in `onStatus`.

## 3. Command dispatch — one path

New `apply_command(const String& action, uint8_t ch, float val) -> bool` used by all four entry points (WS handler, `/api/control`, `console_exec`, `vb_mqtt_cmd`).

- Actions: `toggle`, `set_voltage` (ch 1 only), `all_off`. **`set_ilimit` and `clear_trip` are removed** (guards deleted).
- `setOutput()` gains a bounds guard: `if (output < 1 || output > 3) return;` (fixes the MQTT `chX` hole).
- `setVoltage()` clamps to **[0, 16.0] V** at the single choke point (fixes negative/garbage input from MQTT/HTTP driving the rail to max).

## 4. Wi-Fi manager fixes

- **W1 (orphaned device):** the `/api/wifi/connect` task, on failure, runs `_tryAllSSIDs(5000)`; if that also fails → `vb_start_captive_ap()`. The device is never left disconnected with no recovery path.
- **W2 (races):** `/api/wifi/connect` returns 409 if `g_wifi_conn_busy`. SSID/pass passed via a heap-allocated struct owned by the task (no shared statics). `wifiMgrTask` retry loop also skips while `g_wifi_conn_busy`.
- **W3 (forget reverts):** `credential.h` seeding runs **only when all NVS slots are empty** (first boot / post-factory-reset).
- **W4 (bad creds overwrite good):** `vb_remember_wifi()` is called **after** `WL_CONNECTED`, not before.
- **W5 (scan lifecycle):** scan results cached with a timestamp; GET `/api/wifi/scan` serves cached results < 20 s old, else triggers a rescan. No consume-and-invalidate.
- **W6:** empty (hidden) SSIDs skipped when building the scan JSON.

## 5. Persistence (NVS)

- **S2 (race):** one `SemaphoreHandle_t` (mutex) taken around every `vbPrefs.begin()…end()` block (`vb_save`, `vb_load`, `cal_save`, `cal_load`, `vb_save_wifi_slot`, factory reset).
- **S1 (token):** `auth_token` **is persisted** (new NVS key `token`), so WS-API automation scripts survive reboots. `/api/login` still rotates it, saving only the token key (new `vb_save_token()`), not the whole settings blob.
- **S3:** `set_ilimit` save path disappears with guards; login no longer calls full `vb_save()`.
- **S4:** the duplicate `vb_load()` in `setup()` is removed (kept only inside `vb_setup()`).

## 6. OTA

- **O1:** `volatile bool ota_busy` — set by `perform_ota_tasked()` and the web-upload handler; both refuse (HTTP 409) while set; cleared on completion/failure.
- **T2 (real check):** version-fetch logic factored out of `perform_ota()` into `ota_fetch_latest()`. `/api/ota/check` triggers a background task (result cached in `ota_latest`, `ota_checked_at`) and returns `{checking:true}` until done, then `{current, latest, newer}` — same poll pattern as Wi-Fi scan. UI polls and reports honestly.
- **T1 (settings card truth):** OTA URL field and SSL toggle removed from UI and from `/api/settings` (URL is pinned to the GitHub constant at boot — that stays). Card keeps: auto-check toggle, Check, Update-if-newer, Force, plus a permanent one-line warning that firmware authenticity is not TLS-verified.
- **U2 (honest progress):** pull-OTA shows an indeterminate bar + "started — device reboots if flash succeeds", then polls `/api/info` for the new version. Web-upload OTA (new UI, §7) uses real XHR upload progress events.
- **O3:** manual update confirm dialog states outputs will drop on reboot. Boot auto-check needs nothing (outputs are always off at boot).

## 7. Web UI (new design/Power Supply.html → regenerate web_page.h)

### Removals
PID card · Safety-guards card · per-channel current rows, CC/trip pills, ilimit inputs · `exp_current` toggle · OTA URL/SSL fields · login username field · `set_ilimit`/`clear_trip` from the WS help card · demo-backend simulation of removed fields.

### Fixes
- **U1 (fake data):** demo backend used **only** when `location.protocol === "file:"` (standalone preview). Never a runtime fallback — fetch failures now surface as the red "Offline" pill with the last real values frozen on screen.
- **U3 (XSS):** `esc()` helper; all SSID strings (scan results, saved list) HTML-escaped before `innerHTML`.
- **U4:** big readout `toFixed(2)`.
- **U5:** remove the "1h" history chip (buffer holds ~16 min at 4 Hz); keep 1m/5m/15m/All.
- **U7:** `/` served with `Cache-Control: no-cache` (revalidate; page is one gzip blob) so a new firmware's UI shows immediately after OTA.
- **U8 (real ceiling):** `/api/info` gains `vmax` = top of the calibration map when valid, else 16.0; slider/dial/number max set from it.

### Additions
- **Calibration card** (Settings): "Run sweep" with confirm dialog warning to unload output 1; polls `/api/cal/status` for `running`; shows valid/invalid badge and "Clear map". This is now the primary accuracy workflow, so it must be in the UI.
- **Web-upload OTA**: file picker + upload button in the OTA card → XHR POST to `/api/ota/upload` with real progress bar.
- **Device log card** (Settings): collapsible pane connecting to `/logws`, monospace, keeps last ~200 lines. Makes OTA/Wi-Fi/control activity visible without telnet.

## 8. Logging, console, MQTT, security touch-ups

- **L1:** every `Serial.print*` outside `DbgPrint` itself becomes `Dbg.print*` (Wi-Fi events, wifiMgrTask, captive AP, autotune's replacement logs) so telnet/`/logws` see everything.
- **L2:** USB console input switches to the non-blocking char-accumulator pattern already used for telnet (no more 1 s `readStringUntil` stalls).
- **L3:** `logws.cleanupClients()` added next to `vb_ws.cleanupClients()`.
- **M1:** `vb_mqtt_net` + PubSubClient socket timeout set to 2 s so an unreachable broker can't stall `loop()`.
- **A1:** `/api/info` splits: unauthenticated response carries only `{fw, mdns, require_login, captive}` (what the login screen needs); full info requires auth. `/api/wifi/scan` and `/api/cal/status` gain `VB_REQUIRE_AUTH`.
- **A3:** `/api/reboot` becomes POST (UI updated to match).
- Skipped deliberately: `flushLog` unlocked read (cosmetic torn bytes), telnet timing-safe compare, `/logws` auth — accepted risks.

## 9. Docs & release

- README rewrite: features table, accuracy section, architecture diagram and API examples describe the **map-based deadbeat controller**; PID/auto-tune/guard/current content removed; status JSON examples updated; calibration workflow documented as the accuracy step.
- `web_page.h` regenerated (PowerShell gzip procedure in README §"Regenerating the Web UI").
- `CURRENT_FIRMWARE_VERSION` → **2.1.0**; release assets `version.txt` + `firmware_2.1.0.bin` per the existing GitHub pull-OTA workflow.
- `.gitignore`: `docs/` → `docs/*` + `!docs/superpowers/` so specs/plans are tracked.

## 10. Status JSON after this change (reference)

```json
{"output1":true,"output2":false,"output3":false,
 "voltage1":5.00,"voltage2":5.01,"voltage3":3.30,
 "set1":5.00,"cal":true,"state":"frozen","ts":12345}
```

## 11. Test plan

1. `arduino-cli compile` clean (no warnings introduced).
2. Bench (§2.4): settle time + accuracy at 3.3/5/9/12/13.5 V vs DMM; steady-state DMM-vs-UI comparison.
3. Wi-Fi: connect with wrong password → device recovers to previous network or captive AP; forget survives reboot; scan from two tabs.
4. OTA: concurrent update requests → 409; web upload via new UI with real progress; pull-check reports true latest.
5. MQTT: junk topic `cmd/chX/output` ignored; `voltage -1` clamped; broker-down causes no UI jank.
6. Console: type slowly over USB — no loop stalls; telnet + `/logws` receive Wi-Fi event logs.
7. UI: kill device Wi-Fi mid-session → "Offline" pill, no fabricated readings.

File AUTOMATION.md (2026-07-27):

# Voltbench — Automation & Test Reference (firmware v3.0.1)

A self-contained guide for driving a Voltbench ESP32-C3 programmable power supply
over its HTTP/WebSocket API — for automated testing, CI rigs, or another agent
session. Everything here is verified against firmware **3.0.1**.

---

## 1. What the device is

A 3-channel bench supply with a Wi-Fi web UI:

| Channel | Rail | Control |
|---|---|---|
| **1 (VAR)** | Variable **2.5–~16 V** | Software-set via an MCP4017 digital pot in the LM2596 feedback loop |
| 2 | Fixed **5 V** | On/off only |
| 3 | Fixed **3.3 V** | On/off only |

Only **channel 1** takes a voltage command. Channels 2/3 are on/off.

**Reach it at** `http://<ip>/` or `http://<mdns>.local/` (default mdns `voltbench`).
Find the IP from `/api/info` (`ip` field, when authed) or your router/mDNS.

---

## 2. Auth — read this first (three gotchas)

- Most `/api/*` endpoints require a **bearer token** in an `X-Auth` header. Get one
  from `POST /api/login` with the panel password (default **`admin`**).
- **The token ROTATES on every `/api/login` call.** A new login invalidates the
  previous token. In a test script, **log in once, reuse that token** for the whole
  run. Logging in again mid-run 401s every request still using the old token.
- `require_login` may be **false** on some units — then auth isn't enforced and any
  token (or none) works. Check `/api/info`'s `require_login`. Write scripts to send
  the token when they have one and tolerate `require_login:false`.
- **`/api/info` is the one exception:** unauthenticated it returns only
  `{fw, mdns, require_login, captive}` (HTTP 200, *not* 401) — enough to bootstrap.
  With a valid token it returns the full object. Use the unauth call to discover
  `require_login` before deciding whether you need to log in.

```bash
# Login once, capture token (bash)
TOKEN=$(curl -s -X POST -d "pass=admin" http://$IP/api/login \
        | python -c "import sys,json;print(json.load(sys.stdin)['token'])")
AUTH="-H X-Auth:$TOKEN"
```

---

## 3. Endpoint reference

Auth column: **Y** = 401 without a valid token when `require_login` is on.
`/api/info` is **partial** (see §2).

| Method | Path | Auth | Purpose / body |
|---|---|---|---|
| GET  | `/` | – | gzip web UI (`Content-Encoding: gzip`, `Cache-Control: no-cache`) |
| POST | `/api/login` | – | body `pass=<pw>` → `{ok, token}` (**rotates token**) |
| GET  | `/api/info` | partial | device/network/OTA/mqtt/exp info + `vmax`; minimal unauth |
| GET  | `/api/status` | Y | live telemetry (see §4) |
| POST | `/api/control` | Y | form: `action`, `output`, `value` (see §5) |
| POST | `/api/settings` | Y | **JSON body** — nested settings patch (see §6) |
| POST | `/api/cal/sweep` | Y | start calibration sweep (drives CH1 to max ~1 min) |
| GET  | `/api/cal/status` | Y | `{valid, running, mv:[128]}` |
| POST | `/api/cal/clear` | Y | erase calibration map |
| GET  | `/api/wifi/scan` | Y | `{scanning:true}` (202) then `{networks:[…]}` — **poll it** |
| POST | `/api/wifi/connect` | Y | form `ssid`, `pass` (async; may 409 if busy) |
| POST | `/api/wifi/forget` | Y | form `ssid` |
| GET  | `/api/ota/check` | Y | `{checking:true}` (202) then `{current, latest, newer}` — **poll it** |
| POST | `/api/ota/update` | Y | pull-OTA from GitHub **if newer** (see §8 footgun) |
| POST | `/api/ota/force` | Y | pull-OTA regardless of version |
| POST | `/api/ota/upload` | Y | multipart `.bin` upload → flash → reboot (field name any) |
| GET  | `/api/mqtt/test` | Y | test broker reachability |
| POST | `/api/reboot` | Y | reboot (was GET in ≤3.0.0 — now **POST**) |
| POST | `/api/factory_reset` | Y | wipe NVS + reboot |
| WS | `/ws` | token in msg | live status push (4 Hz) + command channel (see §7) |
| WS | `/logws` | – | view-only device log stream (same as telnet :23) |
| TCP  | `:23` telnet | password | log stream + console: `v<volts> o1 o0 m c ?` |

Async endpoints (`/api/wifi/scan`, `/api/ota/check`) return **202 `{…:true}`** while
working and the real payload once ready — poll every ~1.5–2 s, cap the loop.

---

## 4. `/api/status` shape

```json
{"output1":false,"output2":false,"output3":false,
 "voltage1":4.992,"voltage2":5.01,"voltage3":3.30,
 "set1":5.00,"cal":true,"state":"frozen","ts":123456}
```

- `voltage1/2/3` — measured volts (CH1 is a median-of-5, calm; CH2/3 sampled).
- `set1` — CH1 commanded set-point.
- `cal` — calibration map present.
- `state` — controller state: **`idle` `settling` `verifying` `frozen` `busy`**
  (`busy` = a calibration sweep is running).
- `ts` — `millis()`; wraps every ~49 days (harmless).
- **No** `current*` / `cc*` / `trip*` / `pid*` — that hardware/feature does not exist.

**Waiting for a set-point to land:** poll `/api/status` until `state == "frozen"`,
then wait ~1.5 s for the median display to settle before reading `voltage1`.

---

## 5. Control (`POST /api/control`, form-encoded)

| action | params | effect |
|---|---|---|
| `toggle` | `output=1..3`, `value=1|0` | enable/disable a channel |
| `set_voltage` | `output=1`, `value=<volts>` | set CH1 (CH1 only) |
| `all_off` | — | disable all channels |

- `value` for `set_voltage` is **clamped to [0, 16] V** in firmware; NaN/negative → 0.
- Out-of-range `output` is rejected (bounds-checked) — no effect.

```bash
curl -s $AUTH -X POST -d "action=toggle&output=1&value=1" http://$IP/api/control
curl -s $AUTH -X POST -d "action=set_voltage&output=1&value=9.0" http://$IP/api/control
curl -s $AUTH -X POST -d "action=all_off" http://$IP/api/control
```

### The quantization reality (important for test assertions)

CH1 is set by a **128-step** digital pot in a `1/R` feedback divider, so achievable
voltages are a **non-uniform ladder**: ~30 mV/step near 3 V but **~0.9 V/step near
13–15 V**. The controller lands on the **nearest achievable step that doesn't exceed
target + 300 mV**, then freezes. Consequences for tests:

- **Do not assert exact equality.** A request for 13.2 V may legitimately settle at
  ~12.8 V (the nearest rung) — that is correct behavior, not a bug.
- Assertion tolerance should be **half the local step**: ~±50 mV below 6 V, growing to
  **~±0.5 V near the top**. Or read the map (`/api/cal/status.mv`) and assert the
  device landed on the nearest non-overvolt rung.
- Absolute accuracy also depends on a **per-board ADC scale** (`VV_ADC_SCALE`, compile
  time). Unless a board was DMM-trimmed, expect a few-% offset vs a real meter. Test
  against the device's own reported `voltage1`, not against a DMM value, unless you
  have trimmed that specific unit.

---

## 6. `/api/settings` (JSON body, nested patch — only send what you change)

```json
{
  "mdns": "voltbench",
  "require_login": true,
  "password": "newpass",
  "ota":  { "auto": true },
  "exp":  { "fast": true, "smooth": false, "dial": false },
  "mqtt": { "enabled": false, "host": "", "port": 1883, "user": "", "pass": "", "topic": "voltbench" }
}
```

- `exp.fast` — 4 Hz vs 1 Hz status push. `exp.smooth` — **extra client-side EMA on the
  readout; leave OFF** (the firmware already medians CH1; enabling it double-filters and
  adds seconds of display lag). `exp.dial` — dial input widget.
- The OTA **base URL is pinned** to the project's GitHub releases and cannot be changed
  via settings in 3.0.1 (only `ota.auto` is exposed). `ota.ssl` is fixed insecure.

---

## 7. WebSocket `/ws` (preferred for live monitoring)

Server pushes the §4 status object at 4 Hz (or 1 Hz if `exp.fast=false`). It **only
pushes to clients whose send queue is drained** — a slow/hung reader is skipped, never
backs up the device. Send commands as JSON text frames:

```json
{"action":"toggle","output":1,"value":true,"token":"<TOKEN>"}
{"action":"set_voltage","output":1,"value":5.0,"token":"<TOKEN>"}
{"action":"all_off","token":"<TOKEN>"}
```

Include `token` in every command frame when `require_login` is on. `value` accepts a
bool or number for `toggle`. **Client watchdog rule:** if the socket is open but no
frame arrives for >3.5 s, close it and fall back to polling `/api/status` — the built-in
UI does exactly this so a half-dead socket never freezes the display.

---

## 8. Known gotchas & footguns (will bite automation)

1. **OTA downgrade footgun.** The pull-OTA "newer" test is `latest != current`, i.e. it
   treats *any* difference as update-worthy. A device running a version **newer than the
   published GitHub "latest"** will **downgrade itself** on the next auto/`/api/ota/update`
   check. When flashing a build ahead of the release (e.g. web-upload a pre-release),
   **set `ota.auto:false` first**, or it will revert on reboot. Fixed only when the
   matching release is published (`latest == current`).
2. **Token rotation** — §2. One login per run.
3. **Cached UI after OTA** — `/` is `no-cache` but that permits stale-without-validator;
   a browser can show the *old* UI after an update. Hard-reload, or verify the served
   HTML directly (`curl / | gunzip | grep <marker>`) rather than trusting the tab.
4. **`/api/ota/upload` reboots on success**, dropping the connection mid-request — your
   HTTP client will see a connection error / "context destroyed". That is **success**,
   not failure; confirm by polling `/api/info.fw` after ~10 s.
5. **Calibration sweep ramps CH1 to its maximum (~16 V)** for ~1 min. Ensure CH1 is
   unloaded or on a voltage-tolerant load before `POST /api/cal/sweep`. During the sweep
   `state == "busy"` and set-voltage commands are ignored.
6. **Reboot after any control** — none needed; changes are live. But `/api/reboot`,
   `/api/factory_reset`, OTA, and mdns-change **do** reboot; expect ~10–15 s downtime.

---

## 9. Ready-to-use recipes

### A. Sweep set-points and check landing (bash)
```bash
IP=<device-ip>
TOKEN=$(curl -s -X POST -d "pass=admin" http://$IP/api/login | python -c "import sys,json;print(json.load(sys.stdin)['token'])")
A="-H X-Auth:$TOKEN"
curl -s $A -X POST -d "action=toggle&output=1&value=1" http://$IP/api/control >/dev/null
for V in 3.3 5 9 12; do
  curl -s $A -X POST -d "action=set_voltage&output=1&value=$V" http://$IP/api/control >/dev/null
  # wait for frozen
  for i in $(seq 1 30); do
    st=$(curl -s $A http://$IP/api/status | python -c "import sys,json;print(json.load(sys.stdin)['state'])")
    [ "$st" = frozen ] && break; sleep 0.3
  done
  sleep 1.5
  curl -s $A http://$IP/api/status | python -c "import sys,json;d=json.load(sys.stdin);print(f'set $V -> {d[\"voltage1\"]:.3f} V ({(d[\"voltage1\"]-$V)*1000:+.0f} mV)')"
done
curl -s $A -X POST -d "action=all_off" http://$IP/api/control >/dev/null
```

### B. Poll an async endpoint (wifi scan)
```bash
for i in $(seq 1 15); do
  r=$(curl -s $A http://$IP/api/wifi/scan)
  echo "$r" | grep -q '"networks"' && { echo "$r"; break; }
  sleep 2
done
```

### C. Browser / page-context (Playwright `evaluate`) — same-origin, uses the tab's fetch
```js
async () => {
  const lr = await fetch('/api/login', {method:'POST',
      headers:{'Content-Type':'application/x-www-form-urlencoded'}, body:'pass=admin'}).then(r=>r.json());
  const H = {'X-Auth': lr.token};
  await fetch('/api/control', {method:'POST',
      headers:{...H,'Content-Type':'application/x-www-form-urlencoded'},
      body:'action=set_voltage&output=1&value=5'});
  let s; for (let i=0;i<30;i++){ s=await fetch('/api/status',{headers:H}).then(r=>r.json());
      if (s.state==='frozen') break; await new Promise(r=>setTimeout(r,300)); }
  return s;   // {voltage1, set1, state, ...}
}
```
*(Note: driving the device over curl from a shell may be blocked by some agent
sandboxes as an external state-changing POST; the browser page-context path above,
or an explicitly allowed host, avoids that.)*

---

## 10. Copy-paste agent prompt

> You are testing a Voltbench ESP32-C3 programmable power supply at `http://<IP>/`
> (firmware 3.0.1). Read its automation contract before issuing any call: the API is
> summarized here — [paste this file or its URL].
>
> Rules: (1) `GET /api/info` unauthenticated first to read `require_login`; if true,
> `POST /api/login {pass:"admin"}` **once** and reuse the returned `token` in an
> `X-Auth` header for every call — logging in again rotates and invalidates the old
> token. (2) Only channel 1 is variable; set it with `POST /api/control
> action=set_voltage output=1 value=<volts>` (clamped 0–16 V). (3) After a set,
> poll `/api/status` until `state=="frozen"`, wait ~1.5 s, then read `voltage1`.
> (4) Do **not** assert exact voltage — output is quantized to a non-uniform pot ladder
> (~30 mV/step low, ~0.9 V/step near 15 V); assert within half a local step, or against
> the nearest rung in `/api/cal/status.mv`. (5) Never trigger `/api/ota/*` or
> `/api/factory_reset` unless the test is specifically about OTA — OTA can downgrade the
> device if the GitHub "latest" differs. (6) Async endpoints (`/api/wifi/scan`,
> `/api/ota/check`) return `202 {…:true}` first — poll until the real payload.
> Turn output off (`all_off`) when done.

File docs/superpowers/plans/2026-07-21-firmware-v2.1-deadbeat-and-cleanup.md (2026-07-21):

# Voltbench Firmware v2.1 Implementation Plan — Deadbeat Controller + Honesty Cleanup

> **For agentic workers:** REQUIRED SUB-SKILL: Use superpowers:subagent-driven-development (recommended) or superpowers:executing-plans to implement this plan task-by-task. Steps use checkbox (`- [ ]`) syntax for tracking.

**Goal:** Replace the ±2-step trim sweep with a predict→verify→correct-once deadbeat controller, delete every non-functional subsystem (PID, guards, fake currents, dead settings), fix the Wi-Fi/NVS/OTA/input-validation bugs from the 2026-07-21 review, and make the web UI expose only what exists (plus calibration, web-upload OTA, and a device-log pane).

**Spec:** `docs/superpowers/specs/2026-07-21-firmware-v2.1-controller-and-cleanup-design.md` — read it first; it defines every behavior referenced below.

**Architecture:** Monolithic Arduino sketch: `ESP32_power_supply/ESP32_power_supply.ino` (control task, OTA, console) + `firmware-additions.h` (NVS, web routes, Wi-Fi manager, MQTT) + `web_page.h` (generated gzip of `new design/Power Supply.html`). New file `control_math.h` holds pure, host-testable control math shared by firmware and a g++ host test.

**Tech Stack:** ESP32-C3 (arduino-esp32 core 3.2.1), ESPAsyncWebServer, ArduinoJson 7, PubSubClient, Preferences/NVS. Host tests: plain g++ (mingw64, on PATH).

## Global Constraints

- Firmware version after this plan: `2.1.0` (bumped only in Task 13).
- Build command (verify after EVERY firmware task):
  `arduino-cli compile --fqbn esp32:esp32:esp32c3:CDCOnBoot=cdc,FlashSize=4M,PartitionScheme=custom "ESP32_power_supply"` (run from repo root). Expected: `Sketch uses N bytes` and exit 0. Must stay under the 1835008-byte app slot.
- Overvolt ceiling everywhere: **target + 300 mV**. Voltage clamp: **[0, 16.0] V**. Wiper: **higher step = more resistance = LOWER output voltage**; calibration map `g_cal_mv[]` is non-increasing in step.
- State legend (single vocabulary, spec §2.1): `0=idle 1=settling 2=verifying 3=frozen 4=busy`. Status JSON field name: `state`.
- Do NOT touch: `setInsecure()` TLS calls (accepted risk), `partitions.csv`, `credential.h` contents.
- After editing `new design/Power Supply.html`, ALWAYS regenerate `web_page.h` with the PowerShell snippet in README §"Regenerating the Web UI" (also reproduced in Task 11), then recompile.
- Commit after every task. Message format: `type: summary` + `Co-Authored-By: Claude Fable 5 <noreply@anthropic.com>`.
- Working branch: `release_v2`.

---

### Task 1: Pure control math + host tests

**Files:**
- Create: `ESP32_power_supply/control_math.h`
- Create: `tools/host_test/test_control_math.cpp`
- Modify: `ESP32_power_supply/ESP32_power_supply.ino` (replace `dpStepForR`, `cal_best_step`, the two formula lambdas)

**Interfaces:**
- Produces (used by Tasks 5, 10): `cm_step_for_r(float)->int`, `cm_formula_step(uint32_t)->int`, `cm_floor_step(uint32_t)->int`, `cm_best_step(const uint16_t*, uint32_t)->int`, `cm_median5(const uint32_t[5])->uint32_t`, `cm_local_spacing(const uint16_t*, int)->uint32_t`, `cm_correction_step(const uint16_t*, int s, int floor_step, int32_t err_mV, uint32_t tgt_mV)->int`.

- [ ] **Step 1: Write the failing host test**

Create `tools/host_test/test_control_math.cpp`:

```cpp
// Host self-check for control_math.h — compiles with plain g++, no Arduino.
#include <assert.h>
#include <stdio.h>
#include "../../ESP32_power_supply/control_math.h"

int main() {
  // --- median5 ---
  uint32_t v[5] = {5000, 4990, 9000, 5010, 5005};
  assert(cm_median5(v) == 5005);

  // --- floor step: higher target -> lower (or equal) floor step (more V allowed)
  assert(cm_floor_step(3300) >= cm_floor_step(12000));

  // --- synthetic non-increasing map: 12.0 V at step 0, -75 mV per step
  static uint16_t map[128];
  for (int s = 0; s < 128; s++) map[s] = (uint16_t)(12000 - s * 75);

  // best step never overvolts (> target+300) and is nearest
  for (uint32_t t = 3000; t <= 12000; t += 500) {
    int b = cm_best_step(map, t);
    assert(b >= 0 && (uint32_t)map[b] <= t + 300u);
    uint32_t e = map[b] > t ? map[b] - t : t - map[b];
    assert(e <= 75);                     // within one step of target
  }

  // --- correction: err (+80 mV) > half local spacing (37 mV) -> move +1 step (lower V)
  { uint32_t tgt = map[40] - 80;
    assert(cm_correction_step(map, 40, 0, +80, tgt) == 41);
    assert(cm_correction_step(map, 40, 0, +20, tgt) == 40);      // small err: stay
    assert(cm_correction_step(map, 41, 41, -200, tgt) == 41); }  // floor blocks lower step: stay

  // --- correction never returns a predicted-overvolt step
  { // tgt=8700: step 39 (9075 mV) exceeds tgt+300=9000 -> must refuse the move
    assert(cm_correction_step(map, 40, 0, -400, 8700) == 40); }
  { // same err but tgt=8900: step 39 no longer overvolts (9075<=9200) -> moves
    assert(cm_correction_step(map, 40, 0, -400, 8900) == 39); }

  puts("control_math: all checks passed");
  return 0;
}
```

- [ ] **Step 2: Run it — must fail (header doesn't exist)**

```powershell
g++ -std=c++17 -Wall -o tools/host_test/test_control_math.exe tools/host_test/test_control_math.cpp
```
Expected: FAIL — `control_math.h: No such file or directory`.

- [ ] **Step 3: Create `ESP32_power_supply/control_math.h`**

```cpp
// =============================================================================
//   Pure control math for the deadbeat voltage controller.
//   NO Arduino dependencies — host-testable via tools/host_test/.
//   Convention: higher wiper step = more resistance = LOWER output voltage;
//   the calibration map (mV per step, 0 = unknown) is non-increasing in step.
// =============================================================================
#pragma once
#include <stdint.h>

#define CM_STEPS        128
#define CM_RANGE_OHMS   10000
#define CM_WIPER_OHMS   15
#define CM_VREF_MV      1235
#define CM_R2_REF       10000
#define CM_OV_MARGIN_MV 300u    // hard overvolt ceiling above target

static inline int cm_clampi(int v, int lo, int hi) { return v < lo ? lo : (v > hi ? hi : v); }

// Wiper step whose resistance is closest to r_ohms.
static inline int cm_step_for_r(float r_ohms) {
  int s = (int)(((float)CM_STEPS * (r_ohms - (float)CM_WIPER_OHMS)) / (float)CM_RANGE_OHMS);
  return cm_clampi(s, 0, CM_STEPS - 1);
}

// Formula-predicted step for a target (used when the calibration map is empty).
static inline int cm_formula_step(uint32_t tgt_mV) {
  uint32_t safe = (tgt_mV > (uint32_t)(CM_VREF_MV) + CM_OV_MARGIN_MV)
                    ? (tgt_mV - CM_OV_MARGIN_MV) : tgt_mV;
  if (safe <= (uint32_t)CM_VREF_MV) return CM_STEPS - 1;
  float r = (float)CM_R2_REF * (float)CM_VREF_MV / (float)(safe - CM_VREF_MV)
            - (float)CM_WIPER_OHMS;
  return cm_step_for_r(r > 0.0f ? r : 0.0f);
}

// Lowest step (= max V) permitted for a target; ceiling = target + 300 mV.
static inline int cm_floor_step(uint32_t tgt_mV) {
  uint32_t ceil_mV = tgt_mV + CM_OV_MARGIN_MV;
  if (ceil_mV <= (uint32_t)CM_VREF_MV) return CM_STEPS - 1;
  float r = (float)CM_R2_REF * (float)CM_VREF_MV / (float)(ceil_mV - CM_VREF_MV)
            - (float)CM_WIPER_OHMS;
  return cm_step_for_r(r > 0.0f ? r : 0.0f);
}

// Closest calibrated step to target that doesn't exceed target+300 mV. -1 if none.
static inline int cm_best_step(const uint16_t *map, uint32_t tgt_mV) {
  int best = -1; uint32_t besterr = 0xFFFFFFFFu;
  for (int s = 0; s < CM_STEPS; s++) {
    if (map[s] == 0) continue;
    if ((uint32_t)map[s] > tgt_mV + CM_OV_MARGIN_MV) continue;
    uint32_t e = (tgt_mV > map[s]) ? (tgt_mV - map[s]) : ((uint32_t)map[s] - tgt_mV);
    if (e < besterr) { besterr = e; best = s; }
  }
  return best;
}

// Median of the last 5 display samples.
static inline uint32_t cm_median5(const uint32_t v[5]) {
  uint32_t a[5]; for (int i = 0; i < 5; i++) a[i] = v[i];
  for (int i = 1; i < 5; i++) {
    uint32_t k = a[i]; int j = i - 1;
    while (j >= 0 && a[j] > k) { a[j + 1] = a[j]; j--; }
    a[j + 1] = k;
  }
  return a[2];
}

// Per-step voltage spacing (mV) around step s, from map neighbours.
static inline uint32_t cm_local_spacing(const uint16_t *map, int s) {
  int lo = s > 0 ? s - 1 : s, hi = s < CM_STEPS - 1 ? s + 1 : s;
  if (map[lo] && map[hi] && hi > lo && map[lo] >= map[hi])
    return (uint32_t)(map[lo] - map[hi]) / (uint32_t)(hi - lo);
  return 60;   // conservative fallback ~= 2x low-range spacing
}

// The single allowed correction. Returns the step to move to, or s to stay.
// err_mV = measured - target (signed). Never proposes an overvolt step, never
// crosses floor_step, never moves against the intended direction.
static inline int cm_correction_step(const uint16_t *map, int s, int floor_step,
                                     int32_t err_mV, uint32_t tgt_mV) {
  uint32_t half = cm_local_spacing(map, s) / 2;
  uint32_t mag  = err_mV < 0 ? (uint32_t)(-err_mV) : (uint32_t)err_mV;
  if (mag <= half) return s;                       // within half a step: stay
  int cand = err_mV > 0 ? s + 1 : s - 1;           // too high -> +1 (lower V)
  cand = cm_clampi(cand, floor_step, CM_STEPS - 1);
  if (cand == s || (err_mV > 0) != (cand > s)) return s;   // clamped away: stay
  if (map[cand]) {
    if ((uint32_t)map[cand] > tgt_mV + CM_OV_MARGIN_MV) return s;  // would overvolt
    uint32_t ce = ((uint32_t)map[cand] > tgt_mV)
                    ? (uint32_t)map[cand] - tgt_mV : tgt_mV - (uint32_t)map[cand];
    if (ce >= mag) return s;                       // not predicted closer
  }
  return cand;
}
```

- [ ] **Step 4: Run the host test — must pass**

```powershell
g++ -std=c++17 -Wall -o tools/host_test/test_control_math.exe tools/host_test/test_control_math.cpp && tools/host_test/test_control_math.exe
```
Expected: `control_math: all checks passed`, exit 0.

- [ ] **Step 5: Wire the sketch to control_math.h (no behavior change yet)**

In `ESP32_power_supply.ino`:
1. Add `#include "control_math.h"` after `#include "credential.h"`.
2. Replace the body of `dpStepForR` (lines ~52-55) with: `static int dpStepForR(float Rout) { return cm_step_for_r(Rout); }`
3. Replace the body of `cal_best_step` (lines ~281-290) with: `static int cal_best_step(uint32_t target) { return cm_best_step(g_cal_mv, target); }`
4. Inside `voltageControlTask`, replace the two lambdas `overvolt_floor_step` and `formula_step` (lines ~303-314) with direct calls: delete the lambdas and change every call site `overvolt_floor_step(target)` → `cm_floor_step(target)` and `formula_step(target)` → `cm_formula_step(target)` (call sites at ~348-349 and ~388).

- [ ] **Step 6: Compile firmware**

Run the Global-Constraints build command. Expected: exit 0, size within slot.

- [ ] **Step 7: Commit**

```bash
git add ESP32_power_supply/control_math.h tools/host_test/test_control_math.cpp ESP32_power_supply/ESP32_power_supply.ino
git commit -m "refactor: extract pure control math into host-testable control_math.h"
```

---

### Task 2: Remove the PID subsystem (firmware)

**Files:**
- Modify: `ESP32_power_supply/ESP32_power_supply.ino`
- Modify: `ESP32_power_supply/firmware-additions.h`

**Interfaces:**
- Produces: status JSON no longer has `pid_state`/`pid_kp/ki/kd`/`ctrl_mode`; new field `state` (string from the legend). `/api/pid/*` routes gone. `VBSettings` loses `pid_*`/`ctrl_*` members. (Task 11 updates the UI to match.)

- [ ] **Step 1: Delete PID code from the .ino**

Remove entirely:
- Globals block lines ~129-136: `g_pid_kp`, `g_pid_ki`, `g_pid_kd`, `g_autotune_req`, `g_ctrl_mode`, `g_ctrl_timeout_ms` (KEEP `g_vctrl_state`).
- Forward decl `bool pid_autotune(uint32_t target);` (~line 293) and the whole `pid_autotune()` definition (~lines 477-549).
- In `voltageControlTask`: the `if (g_autotune_req) { ... }` block (~lines 319-327).
- Update the two state-legend comments (~line 133 area and ~line 211) to the single legend: `// 0=idle 1=settling 2=verifying 3=frozen 4=busy`.

- [ ] **Step 2: Delete PID code from firmware-additions.h**

- Extern declarations `g_pid_kp/ki/kd`, `g_autotune_req`, `g_ctrl_mode`, `g_ctrl_timeout_ms` (~lines 44-50). KEEP `extern volatile uint8_t g_vctrl_state;`.
- `VBSettings` members `pid_kp/ki/kd/pid_tuned/ctrl_mode/ctrl_timeout_ms` (~122-128) and their `vb_load`/`vb_save` lines (incl. the "Propagate NVS gains" block ~171-174).
- In `vb_fill_status` (~357-384): remove `ctrl_mode`, `pid_kp/ki/kd`; replace the `pid_state` lines with:
```cpp
  static const char* const STATE_STR[] = {"idle","settling","verifying","frozen","busy"};
  d["state"] = STATE_STR[min((uint8_t)4, (uint8_t)g_vctrl_state)];
```
- In `/api/info` handler: remove the `pid` and `ctrl` JSON objects (~544-549).
- In the `/api/settings` JSON handler: remove the `s["pid"]` and `s["ctrl"]` blocks (~611-621).
- Remove routes `/api/pid/tune` and `/api/pid/reset` (~638-656).

- [ ] **Step 3: Compile** — Global-Constraints command, exit 0. Grep guard: `grep -rn "pid_\|autotune\|ctrl_mode\|ctrl_timeout" ESP32_power_supply/*.ino ESP32_power_supply/firmware-additions.h` returns nothing.

- [ ] **Step 4: Commit** — `git commit -am "feat!: remove vestigial PID subsystem (no control loop ever consumed the gains)"`

---

### Task 3: Remove guards / currents / ilim / trip (firmware)

**Files:**
- Modify: `ESP32_power_supply/firmware-additions.h`

**Interfaces:**
- Produces: status JSON loses `current1-3`, `cc1-3`, `trip1-3`; actions `set_ilimit`/`clear_trip` gone from WS + HTTP; `/api/info` loses `guard` object. (Task 11 updates UI.)

- [ ] **Step 1: Delete guard/current code**

- The whole "Guards" section (~316-349): `vb_read_temp_c`, `vb_read_current`, `vb_trip`, `vb_last_guard`, `vb_guard_tick`.
- `VBSettings` members `guard_ocp/guard_otp/guard_otp_t/guard_recover/ilim[3]/trip[3]` and their load/save lines.
- In `vb_fill_status`: the `current*`, `cc*`, `trip*` lines.
- In `vb_on_ws_event` and `/api/control`: the `set_ilimit` and `clear_trip` branches, and the `vb.trip[...] = false;` line inside the `toggle` branches.
- In `/api/info`: the `guard` object block.
- In `/api/settings`: the `s["guard"]` block.
- In `vb_loop`: the `vb_guard_tick();` call.

- [ ] **Step 2: Compile** — exit 0. Grep guard: `grep -n "ilim\|guard_\|vb_trip\|trip\[" ESP32_power_supply/firmware-additions.h` returns nothing.

- [ ] **Step 3: Commit** — `git commit -am "feat!: remove stub OCP/OTP guards and fake current telemetry (no sensing hardware)"`

---

### Task 4: Input clamps + single `apply_command()` dispatcher

**Files:**
- Modify: `ESP32_power_supply/ESP32_power_supply.ino` (`setOutput`, `setVoltage`, `console_exec`, new `apply_command`)
- Modify: `ESP32_power_supply/firmware-additions.h` (WS handler, `/api/control`, `vb_mqtt_cmd`)

**Interfaces:**
- Produces: `bool apply_command(const String &action, uint8_t ch, float val)` defined in the .ino above the include of firmware-additions.h; declared `extern` in firmware-additions.h. Actions: `toggle` (val≥0.5 = on), `set_voltage` (ch 1 only), `all_off`.

- [ ] **Step 1: Harden the primitives (.ino)**

```cpp
void setOutput(uint8_t output, bool state) {
  if (output < 1 || output > 3) return;   // single bounds guard for all callers
  uint8_t pin = (output == 1) ? ENABLE_VV_PIN
              : (output == 2) ? ENABLE_5V_PIN
                              : ENABLE_3V3_PIN;
  digitalWrite(pin, state ? HIGH : LOW);
  if (output == 1)   psState.output1 = state;
  if (output == 2)   psState.output2 = state;
  if (output == 3)   psState.output3 = state;
}

// Non-blocking: writes globals — voltageControlTask does the actual I2C work.
// Clamped [0, 16 V]: rejects NaN/negative/garbage from MQTT/HTTP/console.
void setVoltage(float voltage) {
  if (!(voltage >= 0.0f)) voltage = 0.0f;
  if (voltage > 16.0f)    voltage = 16.0f;
  uint32_t mv      = (uint32_t)(voltage * 1000.0f);
  g_target_mV      = mv;
  g_setpoint_mV    = mv;
  psState.voltage1 = voltage;
}

// Single command dispatcher shared by WS / HTTP / USB+telnet console / MQTT.
bool apply_command(const String &action, uint8_t ch, float val) {
  if (action == "toggle" && ch >= 1 && ch <= 3) { setOutput(ch, val >= 0.5f); return true; }
  if (action == "set_voltage" && ch == 1)       { setVoltage(val); return true; }
  if (action == "all_off") { setOutput(1, false); setOutput(2, false); setOutput(3, false); return true; }
  return false;
}
```
(Place `apply_command` directly below `setVoltage`. Setting a voltage does NOT force the output on — the console `v` command adds its own `setOutput(1, true)`.)

- [ ] **Step 2: Route all four entry points through it**

`firmware-additions.h` — add near the other externs: `extern bool apply_command(const String &action, uint8_t ch, float val);`

WS handler `vb_on_ws_event` — replace the action if/else chain with:
```cpp
  float tval = value;
  if (act == "toggle")
    tval = doc["value"].is<bool>() ? (doc["value"].as<bool>() ? 1.0f : 0.0f) : value;
  apply_command(act, (uint8_t)output, tval);
```

`/api/control` — replace the chain with:
```cpp
    apply_command(action, out, action == "toggle" ? (val == 1.0f ? 1.0f : 0.0f) : val);
```

`vb_mqtt_cmd` — replace the tail parsing/dispatch with:
```cpp
  uint8_t ch = (uint8_t)tail.substring(2, slash).toInt();
  String  fn = tail.substring(slash + 1);
  if (fn == "output")       apply_command("toggle", ch, (p == "on" || p == "1") ? 1.0f : 0.0f);
  else if (fn == "voltage") apply_command("set_voltage", ch, p.toFloat());
```

`console_exec` (.ino) — replace the `v`/`o1`/`o0` branches:
```cpp
  if      (c == 'v') { float v = l.substring(1).toFloat();
                       apply_command("set_voltage", 1, v); setOutput(1, true);
                       out.printf("[con] set=%dmV out1=on\n", (int)(psState.voltage1 * 1000)); }
  else if (l == "o1") { apply_command("toggle", 1, 1.0f); out.println("[con] out1=on"); }
  else if (l == "o0") { apply_command("toggle", 1, 0.0f); out.println("[con] out1=off"); }
```

- [ ] **Step 3: Compile** — exit 0.

- [ ] **Step 4: Commit** — `git commit -am "fix: bounds-check setOutput, clamp setVoltage, unify all command entry points through apply_command()"`

---

### Task 5: Deadbeat controller + median display + rail globals

**Files:**
- Modify: `ESP32_power_supply/ESP32_power_supply.ino` (`voltageControlTask`, display helpers, new rail globals)
- Modify: `ESP32_power_supply/firmware-additions.h` (`vb_fill_status` reads globals; externs)

**Interfaces:**
- Consumes: `cm_*` from Task 1.
- Produces: `volatile uint32_t g_5v_mV, g_3v3_mV` (defined in .ino, extern'd in firmware-additions.h). `g_display_mV` is now median-of-5. `voltage1` in status = `g_display_mV / 1000.0f`.

- [ ] **Step 1: Add display helpers + rail globals (.ino, below `g_display_mV`)**

```cpp
volatile uint32_t g_5v_mV  = 0;   // 5 V / 3.3 V rails, sampled by the control task
volatile uint32_t g_3v3_mV = 0;   // so web handlers never touch the ADC

// Median-of-5 display window: calm steady-state number, snapped on freeze.
static uint32_t g_disp_ring[5];
static uint8_t  g_disp_i = 0;
static void disp_reset(uint32_t mv) {
  for (int i = 0; i < 5; i++) g_disp_ring[i] = mv;
  g_disp_i = 0; g_display_mV = mv;
}
static void disp_push(uint32_t mv) {
  g_disp_ring[g_disp_i] = mv; g_disp_i = (g_disp_i + 1) % 5;
  g_display_mV = cm_median5(g_disp_ring);
}
```

- [ ] **Step 2: Rewrite `voltageControlTask`**

Replace the whole task with:

```cpp
void voltageControlTask(void* pvParameters) {
  uint32_t lastTarget    = g_target_mV;
  uint32_t settle_t      = 0;
  uint8_t  state         = 0;   // 0=idle 1=settling 2=verifying 3=frozen 4=busy
  bool     pre_discharge = false;
  int      pending_step  = 0;

  for (;;) {
    if (g_cal_sweep_req) { g_cal_sweep_req = false; run_cal_sweep(); lastTarget = 0; state = 0; continue; }

    uint32_t target = g_target_mV;

    // Fresh filtered reading (~200 ms) + rail housekeeping + display median.
    g_measured_mV = vctrl_sample();
    disp_push(g_measured_mV);
    g_5v_mV  = (uint32_t)read_5V_volt();
    g_3v3_mV = (uint32_t)read_3V3_volt();

    if (target != lastTarget) {                       // new setpoint -> acquire
      lastTarget    = target;
      pre_discharge = false;
      if (target > (uint32_t)DC_V_REF) {
        int cstep      = g_cal_valid ? cal_best_step(target) : -1;
        int start_step = (cstep >= 0) ? cstep : cm_formula_step(target);
        int floor_step = cm_floor_step(target);
        if (start_step < floor_step) start_step = floor_step;
        pending_step   = start_step;
        if (g_measured_mV > target + 300u) {          // way high: discharge first
          dpSetStep(dpMaxSteps - 1);
          pre_discharge = true;
          Dbg.printf("[VCtrl] pre-discharge: meas=%umV tgt=%umV\n", g_measured_mV, target);
        } else {
          dpSetStep(start_step);
          Dbg.printf("[VCtrl] target=%umV start step=%d (%s)\n",
                     target, start_step, g_cal_valid ? "map" : "formula");
        }
      }
      settle_t = millis();
      state = 1; g_vctrl_state = 1;
    }

    if (state == 1) {                                 // settling / pre-discharging
      if (pre_discharge) {
        if (g_measured_mV <= target + 300u) {
          dpSetStep(pending_step);
          pre_discharge = false;
          settle_t = millis();
          Dbg.printf("[VCtrl] pre-discharge done: step=%d\n", pending_step);
        }
      } else if (millis() - settle_t >= 300) {
        state = 2; g_vctrl_state = 2;
      }
    }

    if (state == 2) {                                 // verify + correct once, then freeze
      if (target > (uint32_t)DC_V_REF) {
        int      s  = g_wiper_step;
        uint32_t mv = g_measured_mV;                  // sample from the top of this pass
        g_cal_mv[s] = (mv > 65000u) ? 65000u : (uint16_t)mv;   // map self-heals
        int32_t err = (int32_t)mv - (int32_t)target;
        int cand = cm_correction_step(g_cal_mv, s, cm_floor_step(target), err, target);
        if (cand != s) {
          dpSetStep(cand);
          vTaskDelay(pdMS_TO_TICKS(300));
          uint32_t mv2 = vctrl_sample();
          g_cal_mv[cand] = (mv2 > 65000u) ? 65000u : (uint16_t)mv2;
          uint32_t e1 = (err < 0) ? (uint32_t)(-err) : (uint32_t)err;
          uint32_t e2 = (mv2 > target) ? mv2 - target : target - mv2;
          bool ov1 = mv > target + 300u, ov2 = mv2 > target + 300u;
          if (!ov2 && (ov1 || e2 <= e1)) { mv = mv2; }          // keep the correction
          else { dpSetStep(s); vTaskDelay(pdMS_TO_TICKS(300)); mv = vctrl_sample(); }
        }
        g_measured_mV = mv;
        disp_reset(mv);                               // snap display to the new level
        Dbg.printf("[VCtrl] frozen: tgt=%umV meas=%umV step=%d R=%d\n",
                   target, mv, (int)g_wiper_step, (int)dpCalcR());
      }
      state = 3; g_vctrl_state = 3;
    }

    vTaskDelay(pdMS_TO_TICKS(50));   // ~250 ms loop incl. the 200 ms sample
  }
}
```
Also delete the now-unused EMA block that lived in the old task (it is gone with the rewrite) and update `run_cal_sweep`'s trailing `g_display_mV = 0;` to `disp_reset(0);`.

- [ ] **Step 3: Status reads globals (firmware-additions.h)**

Externs: add `extern volatile uint32_t g_5v_mV, g_3v3_mV;` next to the other externs; the `read_5V_volt`/`read_3V3_volt` externs stay (the control task uses them).

`vb_fill_status`: replace the three voltage lines with:
```cpp
  d["voltage1"] = g_display_mV / 1000.0f;   // median-of-5 (spec §2.3)
  d["cal"]      = g_cal_valid;
  d["voltage2"] = g_5v_mV  / 1000.0f;
  d["voltage3"] = g_3v3_mV / 1000.0f;
```
Delete the old comment about "LIVE filtered reading … as requested" — the spec supersedes it.

- [ ] **Step 4: Compile** — exit 0.

- [ ] **Step 5: Flash + bench spot-check (device on USB)**

```powershell
arduino-cli board list   # find the COM port (renumbers across resets)
arduino-cli upload -p COMx --fqbn esp32:esp32:esp32c3:CDCOnBoot=cdc,FlashSize=4M,PartitionScheme=custom "ESP32_power_supply"
```
Then over serial/telnet: `v5` → expect `[VCtrl] target=5000mV` then `[VCtrl] frozen` within ~1 s, at most ONE intermediate step move in the log. `v12`, `v3.3` similarly (3.3 after 12 exercises pre-discharge). `?` shows `state=3`.

- [ ] **Step 6: Commit** — `git commit -am "feat: deadbeat predict-verify-correct controller; median-of-5 display; rails sampled by control task"`

---

### Task 6: Wi-Fi fixes (W1–W6)

**Files:**
- Modify: `ESP32_power_supply/firmware-additions.h` (`/api/wifi/connect`, `/api/wifi/scan`, `_wfScanTask`, `wifiMgrTask`)
- Modify: `ESP32_power_supply/ESP32_power_supply.ino` (credential seeding in `setup()`)

**Interfaces:**
- Produces: `/api/wifi/connect` returns 409 `{"err":"busy"}` when a connection attempt is running. Scan results cached ≤ 20 s (`g_scan_done_at`).

- [ ] **Step 1: W3 — seed credential.h only when NVS slots are all empty (.ino `setup()`)**

Replace the seeding loop (~641-642) with:
```cpp
  // Seed credential.h entries only on first boot / after factory reset —
  // otherwise the UI's "Forget network" would revert on every reboot.
  bool have_saved = false;
  for (uint8_t i = 0; i < VBSettings::MAX_SSID; i++)
    if (!vb.ssid[i].isEmpty()) { have_saved = true; break; }
  if (!have_saved)
    for (uint8_t i = 0; i < min((int)total_ssid_count, (int)VBSettings::MAX_SSID); i++)
      vb_remember_wifi(ssids[i], passwords[i]);
```

- [ ] **Step 2: W1/W2/W4 — rewrite `/api/wifi/connect`**

```cpp
  // Wi-Fi connect — one attempt at a time; creds saved only after success.
  server.on("/api/wifi/connect", HTTP_POST, [](AsyncWebServerRequest *req) {
    VB_REQUIRE_AUTH(req);
    String ssid = req->hasParam("ssid", true) ? req->getParam("ssid", true)->value() : "";
    String pass = req->hasParam("pass", true) ? req->getParam("pass", true)->value() : "";
    if (ssid.isEmpty())    { req->send(400, "application/json", "{\"err\":\"ssid\"}"); return; }
    if (g_wifi_conn_busy)  { req->send(409, "application/json", "{\"err\":\"busy\"}"); return; }
    g_wifi_conn_busy = true;
    req->send(200, "application/json", "{\"ok\":true}");
    struct Req { String ssid, pass; };
    auto *r = new Req{ssid, pass};
    xTaskCreate([](void *pv) {
      Req *r = (Req *)pv;
      vTaskDelay(pdMS_TO_TICKS(500));            // let the HTTP response flush
      WiFi.setAutoReconnect(false);
      WiFi.disconnect(false, false);
      vTaskDelay(pdMS_TO_TICKS(300));
      WiFi.begin(r->ssid.c_str(), r->pass.c_str());
      uint32_t t0 = millis();
      while (WiFi.status() != WL_CONNECTED && millis() - t0 < 15000)
        vTaskDelay(pdMS_TO_TICKS(100));
      if (WiFi.status() == WL_CONNECTED) {
        vb_remember_wifi(r->ssid, r->pass);      // W4: save only creds that worked
        WiFi.setAutoReconnect(true);
        g_wifi_conn_busy = false;
      } else {
        Dbg.printf("[WiFi] join '%s' failed — recovering\n", r->ssid.c_str());
        g_wifi_conn_busy = false;                // release before _tryAllSSIDs re-claims
        if (_tryAllSSIDs(5000)) WiFi.setAutoReconnect(true);
        else if (!vb_in_captive) vb_start_captive_ap();   // W1: never orphaned
      }
      delete r;
      vTaskDelete(NULL);
    }, "wifiSwitch", 4096, r, 1, NULL);
  });
```

- [ ] **Step 3: W2 — `wifiMgrTask` retry loop skips during user connects**

In the `for(;;)` loop, after `if (!vb_in_captive) continue;` add:
```cpp
    if (g_wifi_conn_busy) continue;     // a user-initiated connect owns the radio
```

- [ ] **Step 4: W5/W6 — scan cache + hidden-SSID filter**

Add next to the scan globals: `static volatile uint32_t g_scan_done_at = 0;`
In `_wfScanTask`, before `g_scan_busy = false;` add: `g_scan_done_at = millis();`
Replace the `/api/wifi/scan` handler body with (note: gains `VB_REQUIRE_AUTH` — spec §8 A1):
```cpp
    VB_REQUIRE_AUTH(req);
    if (g_wifi_conn_busy || g_scan_result == WIFI_SCAN_RUNNING) {
      req->send(202, "application/json", "{\"scanning\":true}"); return;
    }
    if (g_scan_result == WIFI_SCAN_FAILED || millis() - g_scan_done_at > 20000) {
      vb_trigger_scan();
      req->send(202, "application/json", "{\"scanning\":true}"); return;
    }
    JsonDocument d;
    auto arr = d["networks"].to<JsonArray>();
    for (int16_t i = 0; i < g_scan_result; i++) {
      if (WiFi.SSID(i).isEmpty()) continue;          // W6: skip hidden networks
      auto o = arr.add<JsonObject>();
      o["ssid"] = WiFi.SSID(i);
      o["rssi"] = WiFi.RSSI(i);
      o["sec"]  = WiFi.encryptionType(i) == WIFI_AUTH_OPEN ? "open" : "secured";
    }
    String out; serializeJson(d, out);
    req->send(200, "application/json", out);
    // W5: results stay cached for 20 s — no consume-and-invalidate.
```

- [ ] **Step 5: Compile** — exit 0.

- [ ] **Step 6: Commit** — `git commit -am "fix(wifi): recover after failed join, serialize connect attempts, save creds only on success, seed credential.h once, cache scans 20s"`

---

### Task 7: NVS mutex + token persistence (S1–S4)

**Files:**
- Modify: `ESP32_power_supply/firmware-additions.h`
- Modify: `ESP32_power_supply/ESP32_power_supply.ino` (`setup()`)

**Interfaces:**
- Produces: `void nvs_lock()`, `void nvs_unlock()`, `void vb_save_token()`. `vb.auth_token` persisted under NVS key `token`.

- [ ] **Step 1: Mutex helpers (firmware-additions.h, above `vb_load`)**

```cpp
// One mutex around every vbPrefs.begin()/end() pair — cal_save runs on the
// control task while web handlers save settings on the AsyncTCP task.
SemaphoreHandle_t g_nvs_mux = nullptr;
static void nvs_lock()   { xSemaphoreTake(g_nvs_mux, portMAX_DELAY); }
static void nvs_unlock() { xSemaphoreGive(g_nvs_mux); }
```
In `.ino` `setup()`, FIRST line: `g_nvs_mux = xSemaphoreCreateMutex();` (before any task creation or NVS call). Wrap the bodies of `vb_load`, `vb_save`, `cal_save`, `cal_load`, `vb_save_wifi_slot`, `vb_factory_reset` with `nvs_lock(); ... nvs_unlock();` (lock before `begin`, unlock after `end`).

- [ ] **Step 2: S1 — persist the auth token**

`vb_load`: add `vb.auth_token = vbPrefs.getString("token", "");`
New function below `vb_save`:
```cpp
void vb_save_token() {
  nvs_lock();
  vbPrefs.begin("voltbench", false);
  vbPrefs.putString("token", vb.auth_token);
  vbPrefs.end();
  nvs_unlock();
}
```
`/api/login` handler: replace `vb_save();` with `vb_save_token();`.
`vb_setup()`: replace `{ vb.auth_token = vb_make_token(); vb_save(); }` with `{ vb.auth_token = vb_make_token(); vb_save_token(); }`.

- [ ] **Step 3: S4 — remove the duplicate load**

Delete `vb_load();` from the FIRST line of `vb_setup()` (the `setup()` call at ino:637 stays — it must run before credential seeding and `cal_load`).

- [ ] **Step 4: Compile** — exit 0. Manual check on next flash: log in, reboot, previously-issued token still works (`curl -H "X-Auth: <tok>" http://<ip>/api/status` → 200).

- [ ] **Step 5: Commit** — `git commit -am "fix(nvs): mutex around Preferences access; persist auth token across reboots"`

---

### Task 8: OTA busy-guard + real update check (O1, T2)

**Files:**
- Modify: `ESP32_power_supply/ESP32_power_supply.ino` (`perform_ota`, `ota_fetch_latest`, `perform_ota_tasked`)
- Modify: `ESP32_power_supply/firmware-additions.h` (`/api/ota/check`, upload handler)

**Interfaces:**
- Produces: `volatile bool ota_busy` (extern in firmware-additions.h), `String ota_fetch_latest(const String &ota_url, bool verify_ssl)`, `/api/ota/check` responds `{"checking":true}` (202) then `{current, latest, newer}`.

- [ ] **Step 1: Factor the version fetch (.ino)**

Above `perform_ota`, add:
```cpp
volatile bool ota_busy       = false;   // one OTA operation at a time (pull or upload)
String        ota_latest     = "";      // cached /api/ota/check result
volatile uint32_t ota_checked_at = 0;   // millis of last successful check (0 = never)

// Fetch <base>version.txt (follows GitHub's 302). "" on any failure.
String ota_fetch_latest(const String &ota_url, bool verify_ssl) {
  bool   https       = ota_url.startsWith("https");
  String version_url = ota_url + "version.txt";
  HTTPClient http;
  http.setFollowRedirects(HTTPC_FORCE_FOLLOW_REDIRECTS);
  bool begun;
  WiFiClientSecure sec; WiFiClient plain;
  if (https) { if (!verify_ssl) sec.setInsecure(); begun = http.begin(sec, version_url); }
  else       { begun = http.begin(plain, version_url); }
  if (!begun) { Dbg.println("OTA: version begin failed"); return ""; }
  int code = http.GET();
  if (code != 200) { http.end(); Dbg.printf("OTA: version.txt HTTP %d\n", code); return ""; }
  String latest = http.getString(); latest.trim(); http.end();
  return latest;
}
```
In `perform_ota`, replace the inline version-check block (`String latest; { ... }`) with:
```cpp
  String latest = ota_fetch_latest(ota_url, verify_ssl);
```

- [ ] **Step 2: Guard the task spawner (.ino)**

```cpp
static bool ota_force_flag = false;
static void ota_task_fn(void *pv) {
  perform_ota(ota_force_flag, vb.ota_ssl, vb.ota_url);
  ota_force_flag = false;
  ota_busy = false;
  vTaskDelete(NULL);
}
// 16 KB stack — TLS handshake/buffers are stack-hungry.
void perform_ota_tasked(bool force) {
  if (ota_busy) { Dbg.println("OTA: busy — request ignored"); return; }
  ota_busy = true;
  ota_force_flag = force;
  xTaskCreatePinnedToCore(ota_task_fn, "otaTask", 16384, NULL, 5, NULL, 0);
}
```

- [ ] **Step 3: Real `/api/ota/check` + upload guard (firmware-additions.h)**

Externs: `extern volatile bool ota_busy; extern String ota_latest; extern volatile uint32_t ota_checked_at; extern String ota_fetch_latest(const String&, bool);`

Replace the `/api/ota/check` route with:
```cpp
  server.on("/api/ota/check", HTTP_GET, [](AsyncWebServerRequest *req) {
    VB_REQUIRE_AUTH(req);
    if (!ota_busy && (ota_checked_at == 0 || millis() - ota_checked_at > 60000)) {
      ota_busy = true;
      xTaskCreatePinnedToCore([](void *) {
        ota_latest     = ota_fetch_latest(vb.ota_url, vb.ota_ssl);
        ota_checked_at = millis();
        ota_busy       = false;
        vTaskDelete(NULL);
      }, "otaChk", 16384, NULL, 5, NULL, 0);
    }
    if (ota_busy) { req->send(202, "application/json", "{\"checking\":true}"); return; }
    JsonDocument d;
    d["current"] = CURRENT_FIRMWARE_VERSION;
    d["latest"]  = ota_latest.length() ? ota_latest : "unknown";
    d["newer"]   = ota_latest.length() && ota_latest != CURRENT_FIRMWARE_VERSION;
    String out; serializeJson(d, out);
    req->send(200, "application/json", out);
  });
```
Upload body handler — at `index == 0` add first:
```cpp
        if (ota_busy && !Update.isRunning()) { Dbg.println("[OTA] busy — upload rejected"); return; }
        ota_busy = true;
```
and in the `final` branch (after `Update.end` handling) add `ota_busy = false;`. In the completion handler's `!ok` path also add `ota_busy = false;` before sending. (Known ceiling: a client that vanishes mid-upload leaves `ota_busy` set until reboot — acceptable, noted in code comment.)

- [ ] **Step 4: Compile** — exit 0.

- [ ] **Step 5: Commit** — `git commit -am "feat(ota): serialize OTA operations; real version check with cached background fetch"`

---

### Task 9: Logging / console / MQTT robustness (L1–L3, M1)

**Files:**
- Modify: `ESP32_power_supply/ESP32_power_supply.ino`
- Modify: `ESP32_power_supply/firmware-additions.h`

- [ ] **Step 1: L1 — route every log through `Dbg`**

In both files, replace every remaining `Serial.print`, `Serial.println`, `Serial.printf` call with the `Dbg.` equivalent EXCEPT: inside `class DbgPrint` itself, and `Serial.begin`/`Serial.setTxTimeoutMs` in `setup()`. Sites: `.ino` setup banner + MCP4017 check; `firmware-additions.h` `vb_start_captive_ap`, `vb_on_wifi_event`, `wifiMgrTask`. Verify with: `grep -n "Serial\.print" ESP32_power_supply/ESP32_power_supply.ino ESP32_power_supply/firmware-additions.h` → no hits.

- [ ] **Step 2: L2 — non-blocking USB console (`loop()` in .ino)**

Replace the `if (Serial.available()) { String l = Serial.readStringUntil('\n'); console_exec(l, Dbg); }` block with:
```cpp
  // Bench console over USB — non-blocking accumulator (readStringUntil would
  // stall loop() up to 1 s per partially-typed line).
  static String usbin;
  while (Serial.available()) {
    char ch = (char)Serial.read();
    if (ch == '\n' || ch == '\r') {
      if (usbin.length()) { console_exec(usbin, Dbg); usbin = ""; }
    } else if (usbin.length() < 64) usbin += ch;
  }
```

- [ ] **Step 3: L3 + M1**

`vb_loop()`: after `vb_ws.cleanupClients();` add `logws.cleanupClients();`
`vb_mqtt_setup()`: after `vb_mqtt.setCallback(...)` add:
```cpp
  vb_mqtt.setSocketTimeout(2);      // seconds — an unreachable broker must not stall loop()
  vb_mqtt_net.setTimeout(2000);     // ms — underlying WiFiClient read timeout
```

- [ ] **Step 4: Compile** — exit 0.

- [ ] **Step 5: Commit** — `git commit -am "fix: all logs via Dbg ring, non-blocking USB console, logws cleanup, MQTT socket timeouts"`

---

### Task 10: Server-side auth split, POST reboot, no-cache, vmax (A1, A3, U7, U8)

**Files:**
- Modify: `ESP32_power_supply/firmware-additions.h`

**Interfaces:**
- Produces: unauthenticated `/api/info` = `{fw, mdns, require_login, captive}` only; full info (incl. new `vmax` in volts) requires auth. `/api/reboot` is POST. `/` served `Cache-Control: no-cache`. (Task 11 UI consumes `vmax` and the minimal-info shape.)

- [ ] **Step 1: Split `/api/info`**

Restructure the handler: build the four public fields first, then wrap ALL remaining fields (ip/mac/ssid/rssi/uptime/ota/exp/mqtt/saved_ssids) in `if (vb_authed(req)) { ... }`. Inside that block, remove `ota["url"]`/`ota["ssl"]` (keep `ota["auto"]`), remove `exp["current"]`, and add:
```cpp
    uint32_t vmax_mV = 16000;
    if (g_cal_valid) {
      uint32_t top = 0;
      for (int s = 0; s < 128; s++) if (g_cal_mv[s] > top) top = g_cal_mv[s];
      if (top > 2500 && top < 16000) vmax_mV = top;
    }
    d["vmax"] = vmax_mV / 1000.0f;
```
In the `/api/settings` handler: inside the `s["ota"]` block remove the `url` and `ssl` lines (keep `auto`); in the `s["exp"]` block remove the `current` line. In `VBSettings`/`vb_load`/`vb_save`, `exp_current` may stay or go — remove it (member + load/save lines) since nothing reads it now.

- [ ] **Step 2: Auth on scan + cal status; POST reboot; no-cache**

- `/api/wifi/scan`: add `VB_REQUIRE_AUTH(req);` as the first line (if not already added in Task 6 — it was; verify).
- `/api/cal/status`: add `VB_REQUIRE_AUTH(req);` first line.
- `/api/reboot`: change `HTTP_GET` → `HTTP_POST`.
- `/` handler: change `res->addHeader("Cache-Control", "public, max-age=300");` → `res->addHeader("Cache-Control", "no-cache");`

- [ ] **Step 3: Compile** — exit 0. Check: `curl http://<ip>/api/info` (no header) shows only 4 fields (verify on next flash).

- [ ] **Step 4: Commit** — `git commit -am "feat(api): split info by auth, guard scan/cal, POST reboot, no-cache UI, report calibrated vmax"`

---

### Task 11: UI — removals + fixes (spec §7 removals/fixes)

**Files:**
- Modify: `new design/Power Supply.html`
- Regenerate: `ESP32_power_supply/web_page.h`

- [ ] **Step 1: Remove dead cards & fields (HTML section, lines ~470-880)**

- **PID card**: delete the whole `<div class="card">` containing `<h3>PID Voltage Control</h3>`.
- **Safety-guards card**: delete the card containing `<h3>Safety guards</h3>`.
- **OTA card**: delete the `#ota-url` field and the two-toggle flex row's **SSL label only** (keep the `#ota-auto` label); delete the `#ota-warn` banner; add in its place:
```html
          <p class="hint" style="font-size:11.5px;color:var(--amber)">Firmware is pulled from this project's GitHub releases over HTTPS <em>without certificate verification</em> — authenticity is not TLS-verified.</p>
```
- **Login card**: delete the Username `<label class="field">…</label>` block (keep password).
- **Channel template** (inside `renderChannels`): delete the `current-row` and `ilimit-row` divs from the template string, the `showI` block in `paintChannels` (everything from `const showI = ...` to the end of its else), and both `ilim` listener blocks (`if (c.hasSlider)` tail + the `else` fixed-channel branch — the whole `else` becomes empty and is deleted).
- **Experimental card**: delete the "Current monitoring" row (`#opt-current`).
- **WS help card**: delete the `set_ilimit` and `clear_trip` example blocks; update the push-format `<pre>` to the spec §10 shape:
```
{"output1":true,"output2":false,"output3":false,
"voltage1":5.00,"voltage2":5.01,"voltage3":3.30,
"set1":5.00,"cal":true,"state":"frozen","ts":12345}
```
- **History toolbar**: delete the `1h` window button (`data-w="3600000"`).

- [ ] **Step 2: Remove dead JS**

- `PID_STATE_LABEL`/`PID_STATE_CLASS` consts, the whole `if (s.pid_state) {...}` block in `onStatus`, the `#pid-save`/`#pid-tune`/`#pid-reset`/`#ctrl-mode` listeners, and the `pid`/`ctrl` sync block in `loadInfo`.
- `#save-guard` listener and the `guard` sync block in `loadInfo`.
- `#opt-current` listener; drop `current:` from `saveExp()` payload and its `info.exp` mirror.
- In `saveOta()`: body becomes `{ota:{auto:$("#ota-auto").checked}}`; delete the two `#ota-ssl` listeners and the `#ota-url` listener; in `loadInfo` delete the `ota-url`/`ota-ssl`/`ota-warn` sync lines (keep `ota-auto`, guarded: `if (info.ota) $("#ota-auto").checked = info.ota.auto;`).
- In the demo backend: delete `guard`, `ilim*`, `current*`, `cc*`, `trip*`, `pid`, `ctrl` state/fields and their handling branches (`set_ilimit`, `clear_trip`).

- [ ] **Step 3: U1 — demo only for file://, failures surface**

Replace `api()` with:
```js
const DEMO = location.protocol === "file:" || !location.host;   // standalone preview only
async function api(path, opts={}){
  if (DEMO) return demo(path, opts);
  const headers = opts.headers || {};
  const tok = sessionStorage.getItem("ps_token");
  if (tok) headers["X-Auth"] = tok;
  if (opts.body && typeof opts.body === "string" && !headers["Content-Type"])
    headers["Content-Type"] = "application/json";
  const r = await fetch(path, {...opts, headers});    // failures propagate to callers
  if (r.status === 401){ sessionStorage.removeItem("ps_authed"); sessionStorage.removeItem("ps_token"); location.reload(); throw new Error("auth"); }
  return await r.json();
}
```
And make `loadInfo` offline-safe + minimal-info-aware (Task 10 shape):
```js
async function loadInfo(){
  let next;
  try { next = await api("/api/info"); } catch(e){ return; }   // offline: keep last info
  info = next;
  const full = "ip" in info;                                   // authed => full payload
  $("#brand-mdns").textContent = info.mdns + ".local";
  $("#mdns-preview").textContent = info.mdns;
  $("#info-fw").textContent = "v" + info.fw;
  $("#captive-banner").style.display = info.captive ? "flex" : "none";
  $("#logout-btn").style.display = info.require_login ? "grid" : "none";
  if (!full) return;
  // ... (keep the existing full-field sync code here, unchanged apart from the
  //      deletions in Step 2: info-ssid/ip/mac/rssi/uptime, conn-ip, ws card,
  //      and the !settingsTabActive form-sync block) ...
}
```

- [ ] **Step 4: U3/U4/U8 — escaping, decimals, real ceiling**

- Add near `$`/`$$`:
```js
const esc = s => String(s).replace(/[&<>"']/g, c => ({"&":"&amp;","<":"&lt;",">":"&gt;",'"':"&quot;","'":"&#39;"}[c]));
```
- In `renderSSIDs()` use it everywhere an SSID enters markup: `data-ssid="${esc(n.ssid)}"` and `<div class="name">${esc(n.ssid)}...`.
- `paintChannels`: `meas.textContent = v.toFixed(2);`
- In `startApp()`, before `renderChannels()`: `if (info?.vmax) channels[0].max = Math.round(info.vmax * 10) / 10;`
- `#reboot-btn` handler: `await api("/api/reboot", {method:"POST"});`

- [ ] **Step 5: Regenerate web_page.h + compile**

Run the PowerShell snippet (from README — paths relative to repo root):
```powershell
$html  = Get-Content "new design\Power Supply.html" -Raw -Encoding utf8
$bytes = [System.Text.UTF8Encoding]::new($false).GetBytes($html)
$ms    = [System.IO.MemoryStream]::new()
$gz    = [System.IO.Compression.GzipStream]::new($ms, [System.IO.Compression.CompressionLevel]::Optimal)
$gz.Write($bytes, 0, $bytes.Length); $gz.Close()
$gzBytes = $ms.ToArray()
$chunks  = for ($i = 0; $i -lt $gzBytes.Length; $i += 16) {
    "  " + (($gzBytes[$i..([Math]::Min($i+15,$gzBytes.Length-1))] |
    ForEach-Object { "0x{0:x2}" -f $_ }) -join ", ")
}
$header = @("#pragma once","const uint8_t index_html_gz[] PROGMEM = {",
            ($chunks -join ",`n"),"};",
            "const size_t index_html_gz_len = $($gzBytes.Length);")
[System.IO.File]::WriteAllLines("ESP32_power_supply\web_page.h", $header,
    [System.Text.UTF8Encoding]::new($false))
Write-Host "Done: $($bytes.Length) -> $($gzBytes.Length) bytes"
```
Then the Global-Constraints compile. Also open `new design/Power Supply.html` directly in a browser (file://) — demo mode must still render all three tabs without console errors (F12).

- [ ] **Step 6: Commit** — `git commit -am "feat(ui): remove PID/guards/current UI, gate demo to file://, escape SSIDs, honest OTA card, 2-decimal readout, real vmax"`

---
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

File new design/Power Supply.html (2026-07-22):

# Sign in

Access the Voltbench control panel.

Incorrect password.

Password Sign in

Default: admin / admin

Voltbenchvoltbench.local

Connected · —

Setup mode · No Wi-Fi configured. Go to Settings → Wi-Fi to join your network.

## Live outputs

Measurements update at 4 Hz · Last sample —

All off

## History

Voltage trace with output state and configured set-points. Stored locally in your browser.

Export CSV Clear

Window

1m 5m 15m All

Channels

All VAR 5V 3V3

—

VAR measured

5V measured

3V3 measured

VAR set-point

ON band (channel colour)

solid = on · dashed = off

### Events

0 events

## Settings

Device identity, network, security, and firmware updates.

### Device

mDNS hostname controls how the device is reachable on your LAN, e.g. voltbench.local.

mDNS hostname

Apply

Lowercase letters, digits and hyphens. Reboot required.

### Connection

Current network details.

SSID

—

IP address

—

MAC

—

Signal

—

Firmware

—

Uptime

—

### Wi-Fi

Scan nearby networks and connect to a new one. Credentials are stored in non-volatile memory and reused on every boot.

Scan

Last scan: never

Click Scan to look for networks.

Password (leave empty for open / saved networks)

Forget saved Connect

### Security

Require a password to access this control panel. Recommended on shared networks.

Require loginShow the sign-in page on every new session

Change password

Save

### Firmware update (OTA)

Pulls firmware over HTTPS from the configured base URL. Use force push to install regardless of version.

Auto-check on bootCompare version.txt at startup

Firmware is pulled from this project's GitHub releases over HTTPS without certificate verification — authenticity is not TLS-verified.

Upload firmware (.bin) directly — no server needed

Upload & flash

Check for updates Update if newer Force push

### Experimental

Features that aren't fully baked. Toggle at your own risk.

Fast sampling (250 ms) Higher cadence ADC reads. Slightly more CPU on the controller.

Voltage smoothing EMA filter on the readout for a calmer number.

Rotary dial input Drag-to-set knob on the variable channel. Hold Shift for fine 10 mV steps.

Reboot device Factory reset

### Calibration

Sweeps CH1 across all 128 wiper steps to build the step→voltage map used for fast, accurate set-points. Disconnect any load from CH1 first — the output ramps to its maximum during the sweep (~1 min).

Map status

—

Clear map Run sweep

### WebSocket API

Direct real-time control — useful for automation scripts, Python notebooks, or custom dashboards. No auth header needed if you include the token in the message body.

Endpoint

ws://voltbench.local/ws Copy

Server push format (250 ms or 1 s)

{"output1":true,"output2":false,"output3":false,
"voltage1":5.00,"voltage2":5.01,"voltage3":3.30,
"set1":5.00,"cal":true,"state":"frozen","ts":12345}

Client commands (send JSON text frame)

// Toggle output  (output 1-3, value true/false)
{"action":"toggle","output":1,"value":true,"token":"YOUR_TOKEN"}

// Set variable voltage  (volts, channel 1 only)
{"action":"set_voltage","output":1,"value":5.0,"token":"YOUR_TOKEN"}

// All outputs off
{"action":"all_off","token":"YOUR_TOKEN"}

Your auth tokenInclude as "token" field in every command when login is on

— Copy

### MQTT bridge

Publish telemetry and accept commands over MQTT — useful for Home Assistant or a lab dashboard.

Enable MQTTTopic prefix below; auto-reconnects

Broker host

Port

Username

Password

Topic prefix

Test Save

### Device log

Live firmware log — control activity, Wi-Fi events, OTA progress. Same stream as telnet port 23.

connecting…

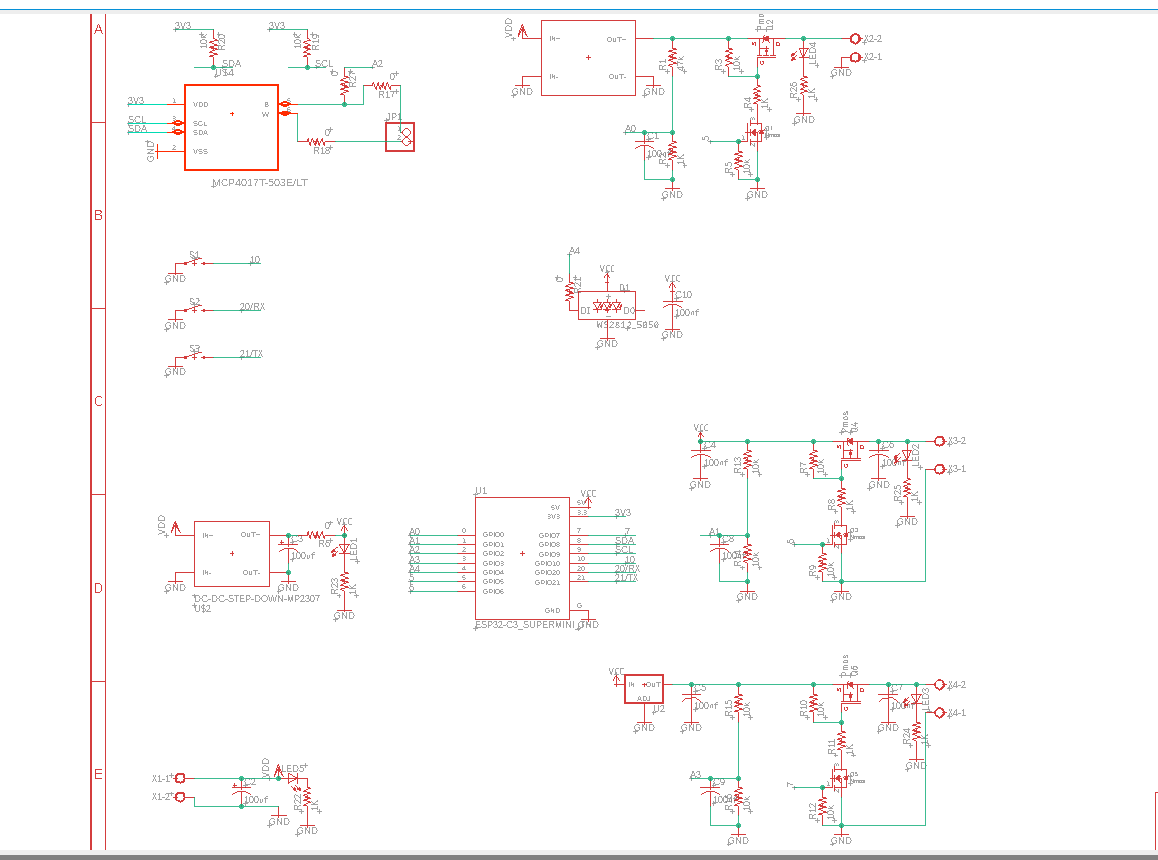
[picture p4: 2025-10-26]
Hardware/CAMOutputs/Capture1.PNG

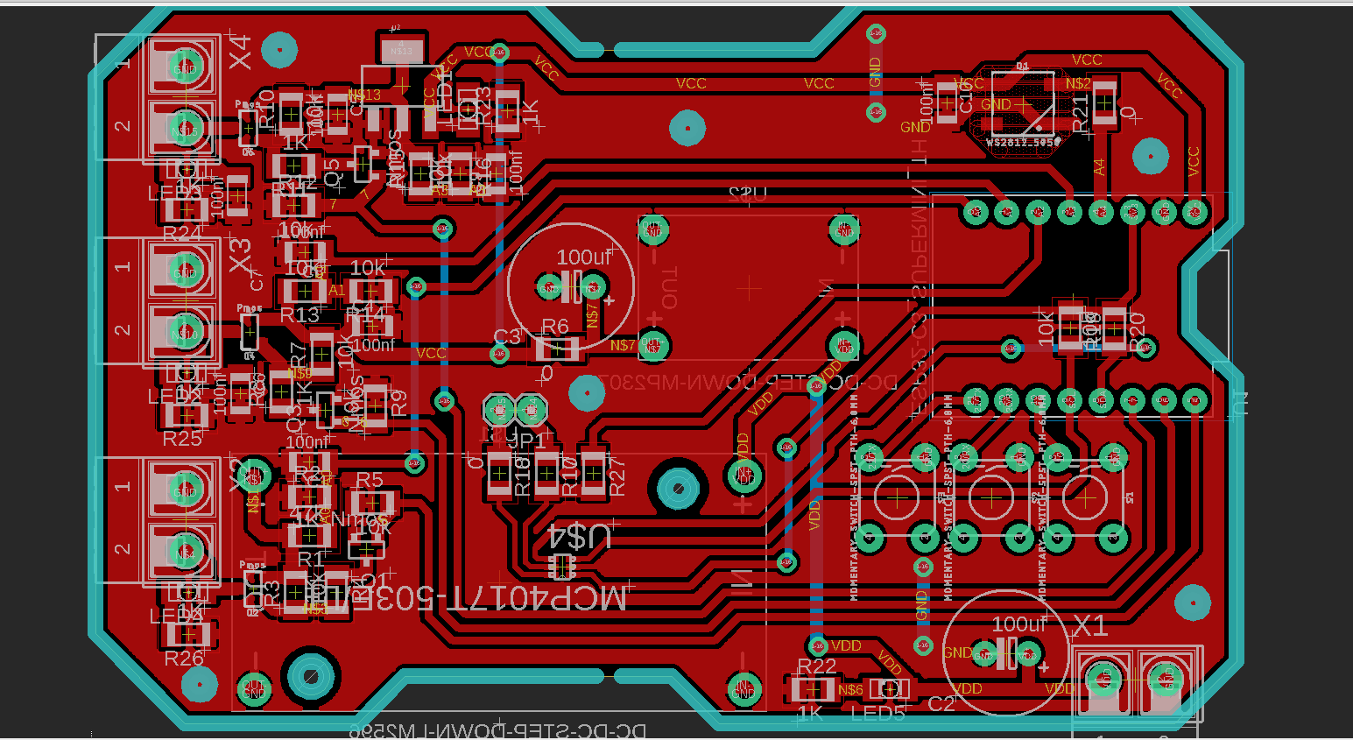
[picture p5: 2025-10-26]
Hardware/CAMOutputs/Capture.PNG

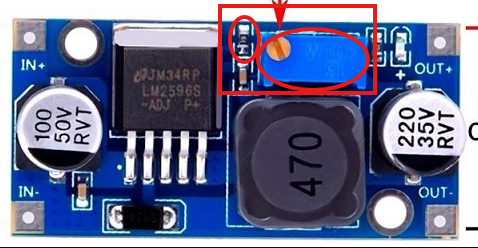
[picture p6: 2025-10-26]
Images/image.png

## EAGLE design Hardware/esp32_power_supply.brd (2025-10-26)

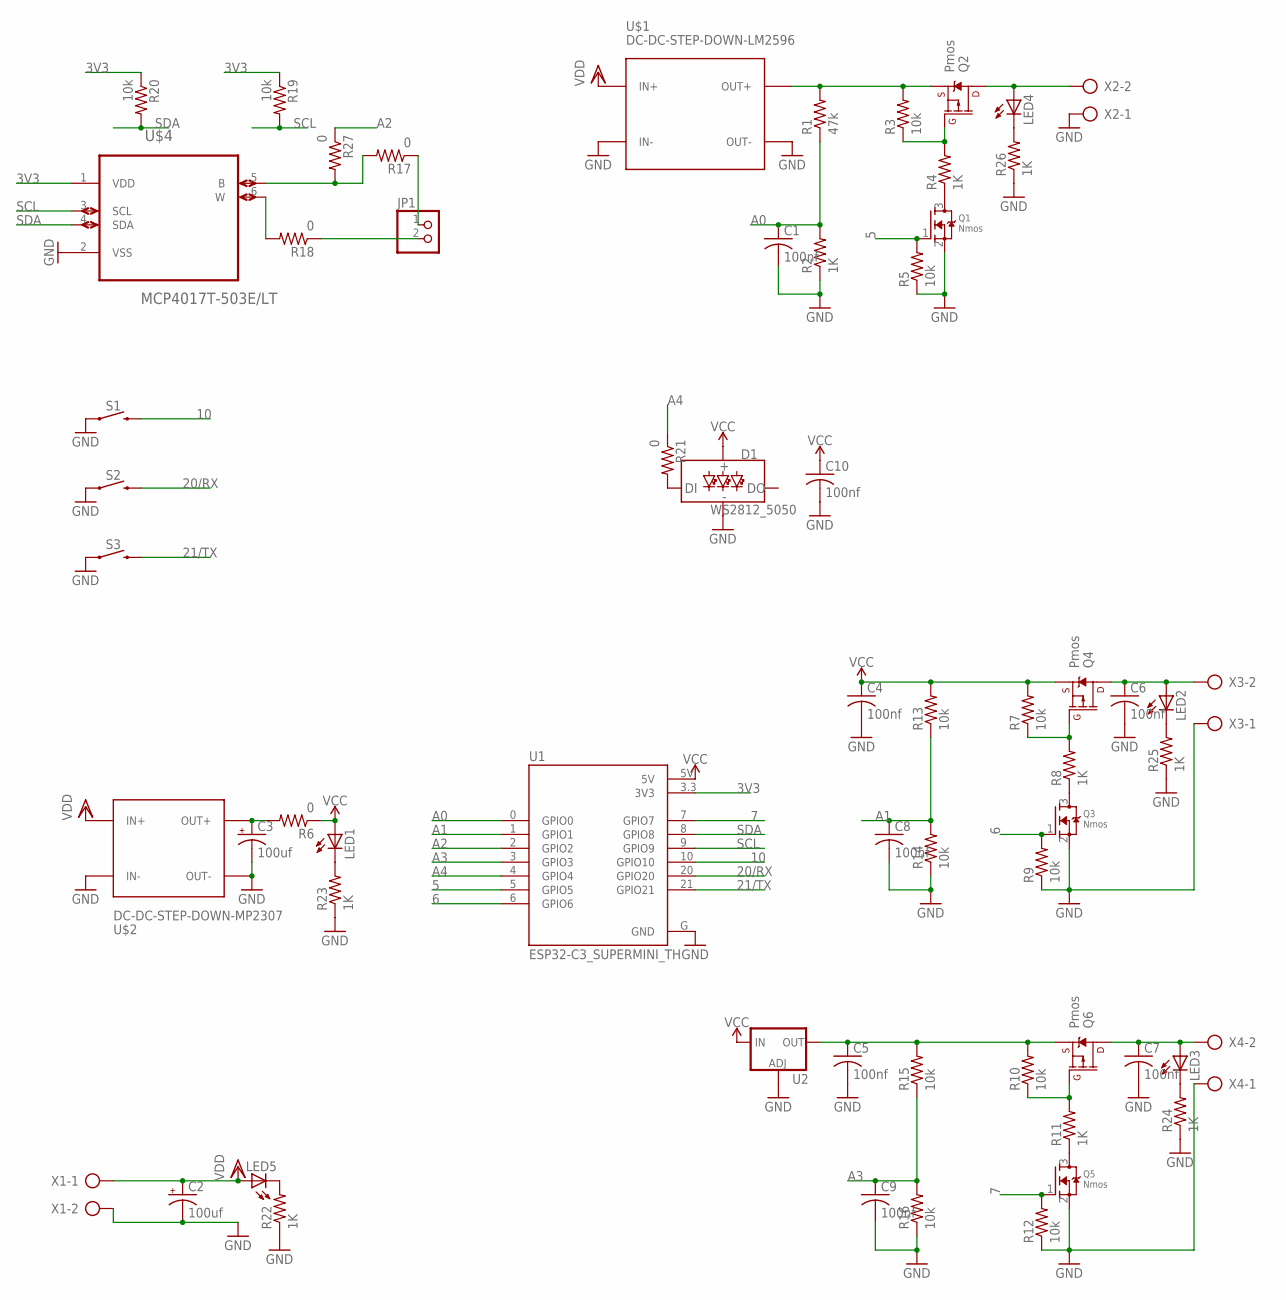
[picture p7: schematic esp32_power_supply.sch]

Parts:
C1, C4, C5, C6, C7, C8, C9, C10: 100nf; C1206K
C2, C3: 100uf; E3,5-10
D1: WS2812_5050; WS2812-5X5-4PIN
JP1: PINHD-1X2; 1X02
LED1, LED2, LED3, LED4, LED5: LEDSMT1206; 1206
Q1, Q3, Q5: Nmos; SOT23
Q2, Q4, Q6: Pmos; SOT23-3
R1: 47k; M1206
R2, R4, R8, R11, R22, R23, R24, R25, R26: 1K; M1206
R3, R5, R7, R9, R10, R12, R13, R14, R15, R16, R19, R20: 10k; M1206
R6, R17, R18, R21, R27: 0; M1206
S1, S2, S3: MOMENTARY-SWITCH-SPST-PTH-6.0MM; TACTILE_SWITCH_PTH_6.0MM
U1: ESP32-C3_SUPERMINI_TH; MODULE_ESP32-C3_SUPERMINI_TH
U2: V_REG_LM1117SOT223; SOT223
U$1: DC-DC-STEP-DOWN-LM2596
U$2: DC-DC-STEP-DOWN-MP2307
U$4: MCP4017T-503E/LT; SOT65P210X110-6N
X1, X2, X3, X4: AK500/2-H

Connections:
3V3: R19.1, R20.1, U1.3.3 (3V3), U$4.1 (VDD)
5: Q1.1 (G), R5.2, U1.5 (GPIO5)
6: Q3.1 (G), R9.2, U1.6 (GPIO6)
7: Q5.1 (G), R12.2, U1.7 (GPIO7)
10: S1.3 (2), U1.10 (GPIO10)
20/RX: S2.3 (2), U1.20 (GPIO20)
21/TX: S3.3 (2), U1.21 (GPIO21)
A0: C1.1, R1.1, R2.2, U1.0 (GPIO0)
A1: C8.1, R13.1, R14.2, U1.1 (GPIO1)
A2: R27.1, U1.2 (GPIO2)
A3: C9.1, R15.1, R16.2, U1.3 (GPIO3)
A4: R21.1, U1.4 (GPIO4)
GND: C1.2, C2.-, C3.-, C4.2, C5.2, C6.2, C7.2, C8.2, C9.2, C10.2, D1.GND, Q1.2 (S), Q3.2 (S), Q5.2 (S), R2.1, R5.1, R9.1, R12.1, R14.1, R16.1, R22.1, R23.1, R24.1, R25.1, R26.1, S1.1, S2.1, S3.1, U1.G (GND), U2.1 (ADJ), U$1.IN-, U$1.OUT-, U$2.IN-, U$2.OUT-, U$4.2 (VSS), X1.2, X2.1, X3.1, X4.1
unnamed: Q2.2 (S), R1.2, R3.2, U$1.OUT+
unnamed: D1.DI, R21.2
unnamed: Q2.1 (G), R3.1, R4.2
unnamed: LED4.A, Q2.3 (D), X2.2
unnamed: Q1.3 (D), R4.1
unnamed: LED5.C, R22.2
unnamed: C3.+, R6.2, U$2.OUT+
unnamed: LED1.C, R23.2
unnamed: Q4.1 (G), R7.1, R8.2
unnamed: C6.1, LED2.A, Q4.3 (D), X3.2
unnamed: Q3.3 (D), R8.1
unnamed: LED3.C, R24.2
unnamed: C5.1, Q6.2 (S), R10.2, R15.2, U2.2 (OUT), U2.4 (OUT)
unnamed: Q6.1 (G), R10.1, R11.2
unnamed: C7.1, LED3.A, Q6.3 (D), X4.2
unnamed: Q5.3 (D), R11.1
unnamed: LED2.C, R25.2
unnamed: LED4.C, R26.2
unnamed: R17.2, R27.2, U$4.5 (B)
unnamed: R18.2, U$4.6 (W)
unnamed: JP1.1, R17.1
unnamed: JP1.2, R18.1
SCL: R19.2, U1.9 (GPIO9), U$4.3 (SCL)
SDA: R20.2, U1.8 (GPIO8), U$4.4 (SDA)
VCC: C4.1, C10.1, D1.VCC, LED1.A, Q4.2 (S), R6.1, R7.2, R13.2, U1.5V, U2.3 (IN)
VDD: C2.+, LED5.A, U$1.IN+, U$2.IN+, X1.1

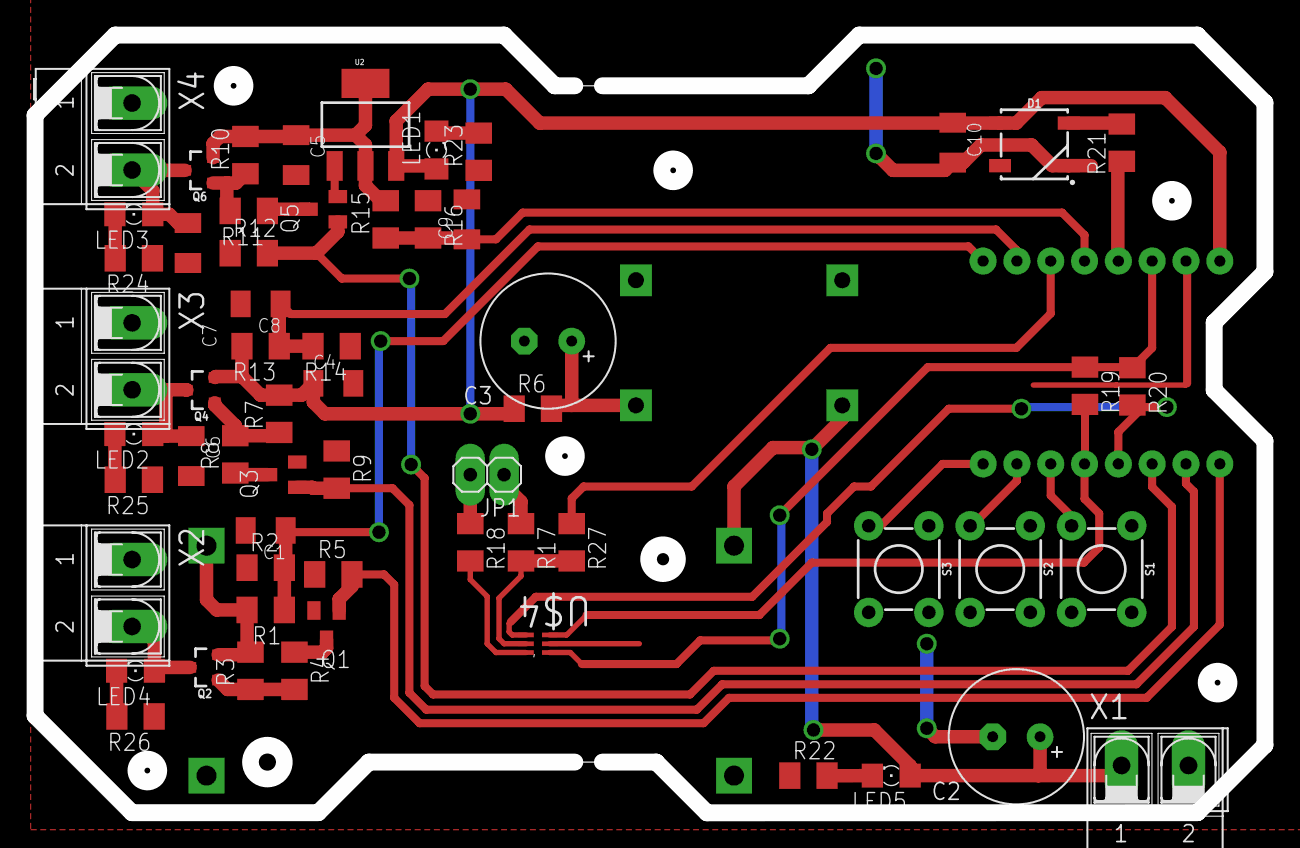
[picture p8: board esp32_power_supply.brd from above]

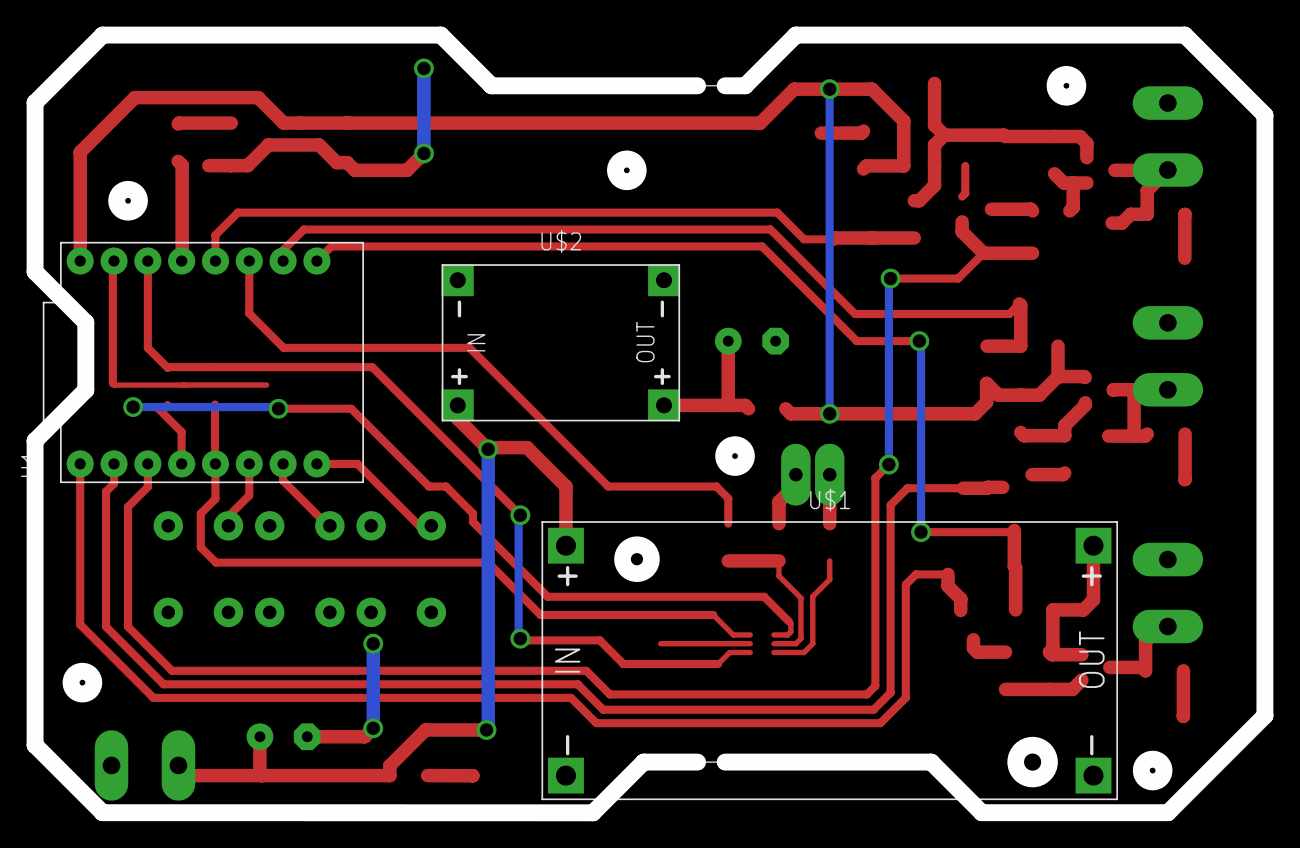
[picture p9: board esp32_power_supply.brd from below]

Board: 2 copper layers, 92.4 x 58.4 mm, 62 parts (3 on the bottom side), 39 nets.

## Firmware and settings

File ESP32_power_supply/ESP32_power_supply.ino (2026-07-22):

// =============================================================================
//   Voltbench — ESP32-C3 Programmable Power Supply
//   Hardware: LM2596-ADJ (variable), Mini360 5V, LM1117 3.3V
//             MCP4017T-103E/LT (10K, 128-step) I2C digital pot @ 0x2F
//             Voltage divider: VOUT — 10K — FB — MCP4017 — GND
//             ADC divider:     VOUT — 47K:1K → VOLTAGE_READ_PIN_VV (×48 scale)
// =============================================================================
#pragma GCC optimize("Os")   // optimize for size — recovers ~50-80 KB
#include <Wire.h>
#include <WiFi.h>
#include <AsyncTCP.h>
#include <ESPAsyncWebServer.h>
#include <ArduinoJson.h>
#include <HTTPClient.h>
#include <HTTPUpdate.h>
#include <WiFiClientSecure.h> // HTTPS pull-OTA (GitHub release assets)
#include <Update.h>          // web-upload OTA (Update.write/end)
#include "driver/rtc_io.h"
#include <ESPmDNS.h>

#include "web_page.h"       // index_html_gz, index_html_gz_len
#include "credential.h"     // ssids[], passwords[], base_url (initial seed only)
#include "control_math.h"   // pure control math, host-tested (tools/host_test/)

#define CURRENT_FIRMWARE_VERSION "3.0.1"

// Pull-OTA source: this repo's GitHub "latest release" assets. The device fetches
// <base>version.txt, and if it differs from CURRENT_FIRMWARE_VERSION, downloads
// <base>firmware_<latest>.bin. /releases/latest/download/ always resolves to the
// newest release, so each new release is auto-discovered.
#define OTA_GITHUB_URL "https://github.com/adi04jan/ESP32-Programmable-Power-Supply/releases/latest/download/"

#define DC_R2_REF          10000
#define DC_V_REF           1235
#define MCPWIPEROHMS       15
// VV-rail ADC divider scale. Nominal 48.0 (47K:1K), trimmed against the bench
// DMM 2026-07-21: 5-point fit (5→14.8 V) gave pure gain error x0.9876, zero
// offset — resistor tolerance. Re-derive if the divider is ever reworked:
// slope of DMM-vs-reported over >=4 points, then VV_ADC_SCALE = 48 * slope.
// Re-run the calibration sweep after changing this (map stores scaled mV).
#define VV_ADC_SCALE 47.40f

#define VOLTAGE_READ_PIN_VV  0
#define VOLTAGE_READ_PIN_5V  1
#define VOLTAGE_READ_PIN_3V3 3

#define ENABLE_VV_PIN   5
#define ENABLE_5V_PIN   6
#define ENABLE_3V3_PIN  7

#define MCP4017ADDRESS  0x2F

static const uint8_t dpMaxSteps   = 128;
static const int     maxRangeOhms = 10000;

// Direct MCP4017 wiper control over I2C. (The SW_MCP4017 library is avoided: its
// setSteps() prints to Serial 4x per call, flooding the port and adding jitter in
// the control hot loop.) Tracks the wiper step locally so dpCalcR() stays consistent.
static volatile uint16_t g_wiper_step = 0;
static int dpStepForR(float Rout) { return cm_step_for_r(Rout); }
static void dpSetStep(int s) {
  s = constrain(s, 0, dpMaxSteps - 1);
  g_wiper_step = (uint16_t)s;
  Wire.beginTransmission(MCP4017ADDRESS);
  Wire.write((uint8_t)s);
  Wire.endTransmission();
}
static void dpSetR(float Rout) { dpSetStep(dpStepForR(Rout)); }
static float dpCalcR() {
  return ((float)g_wiper_step / dpMaxSteps) * (float)maxRangeOhms + (float)MCPWIPEROHMS;
}

// ---- Output-1 calibration map: measured mV at each wiper step (0 = uncalibrated)
// Built by a one-time sweep (run_cal_sweep), persisted to NVS. Lets set-voltage
// land on the genuinely-closest step instead of trusting the (inaccurate) formula.
uint16_t          g_cal_mv[128]   = {0};
volatile bool     g_cal_valid     = false;
volatile bool     g_cal_sweep_req = false;   // set via API/console to (re)build the map
volatile uint32_t g_display_mV    = 0;       // median-of-5 reading for the UI
void cal_save();                              // defined in firmware-additions.h (needs NVS)
void cal_load();

volatile uint32_t g_5v_mV  = 0;   // 5 V / 3.3 V rails, sampled by the control task
volatile uint32_t g_3v3_mV = 0;   // so web handlers never touch the ADC

// Median-of-5 display window: calm steady-state number, snapped on freeze.
static uint32_t g_disp_ring[5];
static uint8_t  g_disp_i = 0;
static void disp_reset(uint32_t mv) {
  for (int i = 0; i < 5; i++) g_disp_ring[i] = mv;
  g_disp_i = 0; g_display_mV = mv;
}
static void disp_push(uint32_t mv) {
  g_disp_ring[g_disp_i] = mv; g_disp_i = (g_disp_i + 1) % 5;
  g_display_mV = cm_median5(g_disp_ring);
}

// =============================================================================
//   Remote debug log — fans out to USB Serial + telnet (:23) + browser WS,
//   backed by a ring buffer so a late-connecting client still sees recent
//   output. Producers (any task) only touch Serial + the ring; the telnet/WS
//   consumers are pumped from loop() to respect AsyncTCP's single-task rule.
// =============================================================================
static const int         LOGN     = 3072;
static char              g_log[LOGN];
static volatile uint32_t g_logw   = 0;            // monotonic write counter
static portMUX_TYPE      g_logmux = portMUX_INITIALIZER_UNLOCKED;

// NOTE: `if (Serial)` is NOT enough — after an esptool flash the CDC session is
// left stale-"connected" (port enumerated, nobody reading). Once the TX ring
// fills, HWCDC::write's retry counter underflows with txTimeout=0 (core 3.2.1
// HWCDC.cpp:448-479: `tries--` from 0) and blocks loop() ~forever. Writing no
// more than availableForWrite() keeps every write on the non-blocking fast path.
class DbgPrint : public Print {
 public:
  size_t write(uint8_t c) override {
    if (Serial && Serial.availableForWrite() > 0) Serial.write(c);
    portENTER_CRITICAL(&g_logmux);
    g_log[g_logw % LOGN] = (char)c; g_logw++;
    portEXIT_CRITICAL(&g_logmux);
    return 1;
  }
  size_t write(const uint8_t *b, size_t n) override {
    if (Serial) {
      size_t a = (size_t)Serial.availableForWrite();
      if (a > 0) Serial.write(b, n < a ? n : a);   // truncate to free space, never block
    }
    portENTER_CRITICAL(&g_logmux);
    for (size_t i = 0; i < n; i++) { g_log[g_logw % LOGN] = (char)b[i]; g_logw++; }
    portEXIT_CRITICAL(&g_logmux);
    return n;
  }
};
DbgPrint   Dbg;

WiFiServer telnetSrv(23);
WiFiClient telnetCli;
bool       telnetAuthed = false;
uint32_t   g_telnetRead = 0;       // ring cursor for telnet client
uint32_t   g_wsLogRead  = 0;       // ring cursor for browser log WS

AsyncWebServer server(80);

struct State {
  bool  output1  = false;
  bool  output2  = false;
  bool  output3  = false;
  float voltage1 = 2.5f;   // commanded set-point (V)
} psState;

// Shared between web-handler task and voltageControlTask.
// 32-bit aligned reads/writes are atomic on ESP32-C3 RISC-V.
volatile uint32_t g_target_mV    = 2500;
volatile uint32_t g_setpoint_mV  = 2500;
volatile uint32_t g_measured_mV  = 0;

// Voltage-control state — written by voltageControlTask, read by firmware-additions.h
volatile uint8_t  g_vctrl_state     = 0;    // 0=idle 1=settling 2=verifying 3=frozen 4=busy

// =============================================================================
//   ADC averaging (rolling buffer)
// =============================================================================
static int read_any_volt(int pin, uint32_t *sample, bool *firstrun, int sc) {
  for (int j = sc - 1; j > 0; j--) sample[j] = sample[j - 1];
  sample[0] = analogReadMilliVolts(pin);
  if (!*firstrun && sample[0] != 0) {
    for (int j = 1; j < sc; j++) sample[j] = sample[0];
    *firstrun = true;
  }
  long sum = 0;
  for (int j = 0; j < sc; j++) sum += sample[j];
  return sum / sc;
}

int read_5V_volt() {
  const int sc = 5;
  static uint32_t s[sc] = {0}; static bool init = false;
  return read_any_volt(VOLTAGE_READ_PIN_5V, s, &init, sc) * 2;
}
int read_3V3_volt() {
  const int sc = 5;
  static uint32_t s[sc] = {0}; static bool init = false;
  return read_any_volt(VOLTAGE_READ_PIN_3V3, s, &init, sc) * 2;
}

// =============================================================================
//   Output / voltage control
// =============================================================================
void setOutput(uint8_t output, bool state) {
  if (output < 1 || output > 3) return;   // single bounds guard for all callers
  uint8_t pin = (output == 1) ? ENABLE_VV_PIN
              : (output == 2) ? ENABLE_5V_PIN
                              : ENABLE_3V3_PIN;
  digitalWrite(pin, state ? HIGH : LOW);
  if (output == 1)   psState.output1 = state;
  if (output == 2)   psState.output2 = state;
  if (output == 3)   psState.output3 = state;
}

// Non-blocking: writes globals — voltageControlTask does the actual I2C work.
// Clamped [0, 16 V]: rejects NaN/negative/garbage from MQTT/HTTP/console.
void setVoltage(float voltage) {
  if (!(voltage >= 0.0f)) voltage = 0.0f;
  if (voltage > 16.0f)    voltage = 16.0f;
  uint32_t mv      = (uint32_t)(voltage * 1000.0f);
  g_target_mV      = mv;
  g_setpoint_mV    = mv;
  psState.voltage1 = voltage;
}

// Single command dispatcher shared by WS / HTTP / USB+telnet console / MQTT.
bool apply_command(const String &action, uint8_t ch, float val) {
  if (action == "toggle" && ch >= 1 && ch <= 3) { setOutput(ch, val >= 0.5f); return true; }
  if (action == "set_voltage" && ch == 1)       { setVoltage(val); return true; }
  if (action == "all_off") { setOutput(1, false); setOutput(2, false); setOutput(3, false); return true; }
  return false;
}


// Execute one bench-console command, replying on `out`. Shared by USB + telnet.
void console_exec(const String &lineIn, Print &out) {
  String l = lineIn; l.trim();
  if (!l.length()) return;
  char c = l[0];
  if      (c == 'v') { float v = l.substring(1).toFloat();
                       apply_command("set_voltage", 1, v); setOutput(1, true);
                       out.printf("[con] set=%dmV out1=on\n", (int)(psState.voltage1 * 1000)); }
  else if (l == "o1") { apply_command("toggle", 1, 1.0f); out.println("[con] out1=on"); }
  else if (l == "o0") { apply_command("toggle", 1, 0.0f); out.println("[con] out1=off"); }
  else if (c == 'm')  { g_cal_sweep_req = true; out.println("[con] calibration sweep requested"); }
  else if (c == 'c')  { out.printf("[con] cal valid=%d\n", g_cal_valid ? 1 : 0); }
  else if (c == '?')  { out.printf("[con] set=%umV meas=%umV disp=%umV state=%u R=%dohm cal=%d\n",
                          g_setpoint_mV, g_measured_mV, g_display_mV, g_vctrl_state, (int)dpCalcR(), g_cal_valid ? 1 : 0); }
  else out.println("[con] cmds: v<volts> o1 o0 m c ?");
}

// =============================================================================
//   voltageControlTask — deterministic best-step voltage setter
//   g_vctrl_state: 0=idle 1=settling 2=verifying 3=frozen 4=busy
//   Runs on core 0, priority 2. Web handlers return immediately.
// =============================================================================
// Heavily filtered: mean of 50 reads over ~200 ms (10 mains cycles @50 Hz) to
// reject hum picked up on the high-Z 47K:1K divider node. The old 4-sample /
// 20 ms read let ±600 mV of ADC noise through.
static uint32_t vctrl_sample() {
  uint32_t sum = 0;
  for (int s = 0; s < 50; s++) {
    sum += analogReadMilliVolts(VOLTAGE_READ_PIN_VV);
    vTaskDelay(pdMS_TO_TICKS(4));
  }
  return (uint32_t)((sum / 50) * VV_ADC_SCALE);
}

// Isotonic regression (Pool-Adjacent-Violators) — enforce Vout non-increasing
// as step increases, pooling noisy violators. Cleans the swept map so lookups
// land in the right neighbourhood even at low V, where per-step spacing
// (~27 mV) is well under the ADC noise (~±150 mV) and raw samples are jumbled.
static void cal_smooth_monotonic() {
  int lo = 0;               while (lo < dpMaxSteps && g_cal_mv[lo] == 0) lo++;
  int hi = dpMaxSteps - 1;  while (hi >= 0 && g_cal_mv[hi] == 0) hi--;
  if (hi - lo < 3) return;
  static float bval[128]; static int bcnt[128];
  int nb = 0;
  for (int i = lo; i <= hi; i++) {
    bval[nb] = g_cal_mv[i]; bcnt[nb] = 1; nb++;
    while (nb >= 2 && bval[nb - 1] > bval[nb - 2]) {       // non-increasing violation -> pool
      float sum = bval[nb - 1] * bcnt[nb - 1] + bval[nb - 2] * bcnt[nb - 2];
      bcnt[nb - 2] += bcnt[nb - 1];
      bval[nb - 2]  = sum / bcnt[nb - 2];
      nb--;
    }
  }
  int idx = lo;
  for (int b = 0; b < nb; b++)
    for (int k = 0; k < bcnt[b]; k++) g_cal_mv[idx++] = (uint16_t)(bval[b] + 0.5f);
}

// Build the step->mV calibration map by sweeping the wiper across its range.
// Output 1 is driven from ~2.5 V up to its ceiling, so run only with nothing
// (or a voltage-tolerant load) on output 1. Persisted to NVS on completion.
void run_cal_sweep() {
  bool was_on = psState.output1;
  setOutput(1, true);
  g_vctrl_state = 4;                          // "busy" for the UI
  Dbg.println("[Cal] sweep start");
  dpSetStep(dpMaxSteps - 1);                  // max R -> lowest V
  vTaskDelay(pdMS_TO_TICKS(400));
  for (int s = dpMaxSteps - 1; s >= 0; s--) {
    dpSetStep(s);
    vTaskDelay(pdMS_TO_TICKS(120));           // settle (rising V is fast, no load)
    uint32_t mv = (vctrl_sample() + vctrl_sample()) / 2;   // ~400 ms average for a cleaner map
    g_cal_mv[s] = (mv > 65000u) ? 65000u : (uint16_t)mv;
    if (mv > 16500u) {                        // railed near Vin ceiling — fill rest & stop
      for (int j = s - 1; j >= 0; j--) g_cal_mv[j] = g_cal_mv[s];
      break;
    }
  }
  dpSetStep(dpMaxSteps - 1);                  // park at lowest V
  cal_smooth_monotonic();                     // isotonic clean-up before use/save
  g_cal_valid = true;
  cal_save();
  if (!was_on) setOutput(1, false);
  disp_reset(0);
  g_vctrl_state = 0;
  Dbg.println("[Cal] sweep done + saved");
}

// Closest calibrated step to target that doesn't exceed the +300 mV ceiling.
static int cal_best_step(uint32_t target) { return cm_best_step(g_cal_mv, target); }

void voltageControlTask(void* pvParameters) {
  uint32_t lastTarget    = g_target_mV;
  uint32_t settle_t      = 0;
  uint8_t  state         = 0;   // 0=idle 1=settling 2=verifying 3=frozen 4=busy
  bool     pre_discharge = false;
  int      pending_step  = 0;

  for (;;) {
    if (g_cal_sweep_req) { g_cal_sweep_req = false; run_cal_sweep(); lastTarget = 0; state = 0; continue; }

    uint32_t target = g_target_mV;

    // Fresh filtered reading (~200 ms) + rail housekeeping + display median.
    g_measured_mV = vctrl_sample();
    static bool disp_init = false;
    if (!disp_init) { disp_reset(g_measured_mV); disp_init = true; }
    else            { disp_push(g_measured_mV); }
    g_5v_mV  = (uint32_t)read_5V_volt();
    g_3v3_mV = (uint32_t)read_3V3_volt();

    if (target != lastTarget) {                       // new setpoint -> acquire
      lastTarget    = target;
      pre_discharge = false;
      if (target > (uint32_t)DC_V_REF) {
        int cstep      = g_cal_valid ? cal_best_step(target) : -1;
        int start_step = (cstep >= 0) ? cstep : cm_formula_step(target);
        int floor_step = cm_floor_step(target);
        if (start_step < floor_step) start_step = floor_step;
        pending_step   = start_step;
        if (g_measured_mV > target + 300u) {          // way high: discharge first
          dpSetStep(dpMaxSteps - 1);
          pre_discharge = true;
          Dbg.printf("[VCtrl] pre-discharge: meas=%umV tgt=%umV\n", g_measured_mV, target);
        } else {
          dpSetStep(start_step);
          Dbg.printf("[VCtrl] target=%umV start step=%d (%s)\n",
                     target, start_step, g_cal_valid ? "map" : "formula");
        }
      }
      settle_t = millis();
      state = 1; g_vctrl_state = 1;
    }

    if (state == 1) {                                 // settling / pre-discharging
      if (pre_discharge) {
        if (g_measured_mV <= target + 300u) {
          dpSetStep(pending_step);
          pre_discharge = false;
          settle_t = millis();
          Dbg.printf("[VCtrl] pre-discharge done: step=%d\n", pending_step);
        }
      } else if (millis() - settle_t >= 300) {
        state = 2; g_vctrl_state = 2;
      }
    }

    if (state == 2) {                                 // verify + correct once, then freeze
      if (target > (uint32_t)DC_V_REF) {
        int      s  = g_wiper_step;
        uint32_t mv = g_measured_mV;                  // sample from the top of this pass
        g_cal_mv[s] = (mv > 65000u) ? 65000u : (uint16_t)mv;   // map self-heals
        int32_t err = (int32_t)mv - (int32_t)target;
        int cand = cm_correction_step(g_cal_mv, s, cm_floor_step(target), err, target);
        if (cand != s) {
          dpSetStep(cand);
          vTaskDelay(pdMS_TO_TICKS(300));
          uint32_t mv2 = vctrl_sample();
          g_cal_mv[cand] = (mv2 > 65000u) ? 65000u : (uint16_t)mv2;
          uint32_t e1 = (err < 0) ? (uint32_t)(-err) : (uint32_t)err;
          uint32_t e2 = (mv2 > target) ? mv2 - target : target - mv2;
          bool ov1 = mv > target + 300u, ov2 = mv2 > target + 300u;
          if ((!ov2 && (ov1 || e2 <= e1)) || (ov1 && ov2)) { mv = mv2; }  // keep correction; if both overvolt, cand is the lower-V step
          else {                                             // correction made it worse: step back
            dpSetStep(s); vTaskDelay(pdMS_TO_TICKS(300));
            mv = vctrl_sample();
            g_cal_mv[s] = (mv > 65000u) ? 65000u : (uint16_t)mv;   // map self-heal on re-sample too
          }
        }
        g_measured_mV = mv;
        disp_reset(mv);                               // snap display to the new level
        Dbg.printf("[VCtrl] frozen: tgt=%umV meas=%umV step=%d R=%d\n",
                   target, mv, (int)g_wiper_step, (int)dpCalcR());
      }
      state = 3; g_vctrl_state = 3;
    }

    vTaskDelay(pdMS_TO_TICKS(50));   // ~250 ms loop incl. the 200 ms sample
  }
}

// =============================================================================
//   OTA — uses ESP32 core HTTPUpdate (HTTP or HTTPS, no extra library needed)
// =============================================================================
volatile bool     ota_busy       = false;   // one OTA operation at a time (pull or upload)
String            ota_latest     = "";      // cached /api/ota/check result
volatile uint32_t ota_checked_at = 0;       // millis of last successful check (0 = never)

// Fetch <base>version.txt (follows GitHub's 302). "" on any failure.
String ota_fetch_latest(const String &ota_url, bool verify_ssl) {
  bool   https       = ota_url.startsWith("https");
  String version_url = ota_url + "version.txt";
  HTTPClient http;
  http.setFollowRedirects(HTTPC_FORCE_FOLLOW_REDIRECTS);
  bool begun;
  WiFiClientSecure sec; WiFiClient plain;
  if (https) { if (!verify_ssl) sec.setInsecure(); begun = http.begin(sec, version_url); }
  else       { begun = http.begin(plain, version_url); }
  if (!begun) { Dbg.println("OTA: version begin failed"); return ""; }
  int code = http.GET();
  if (code != 200) { http.end(); Dbg.printf("OTA: version.txt HTTP %d\n", code); return ""; }
  String latest = http.getString(); latest.trim(); http.end();
  return latest;
}

void perform_ota(bool force, bool verify_ssl, const String &ota_url) {
  bool https = ota_url.startsWith("https");

  String latest = ota_fetch_latest(ota_url, verify_ssl);

  Dbg.printf("OTA: current=%s latest=%s\n", CURRENT_FIRMWARE_VERSION, latest.c_str());
  if (latest.isEmpty()) { Dbg.println("OTA: empty version, abort"); return; }
  if (!force && latest == CURRENT_FIRMWARE_VERSION) { Dbg.println("OTA: already up-to-date"); return; }

  // --- download + flash firmware_<latest>.bin ---
  String firmware_url = ota_url + "firmware_" + latest + ".bin";
  Dbg.printf("OTA: downloading %s\n", firmware_url.c_str());
  httpUpdate.rebootOnUpdate(true);
  httpUpdate.setFollowRedirects(HTTPC_FORCE_FOLLOW_REDIRECTS);
  t_httpUpdate_return ret;
  if (https) {
    WiFiClientSecure sec; if (!verify_ssl) sec.setInsecure();
    ret = httpUpdate.update(sec, firmware_url);
  } else {
    WiFiClient plain;
    ret = httpUpdate.update(plain, firmware_url);
  }
  if (ret == HTTP_UPDATE_FAILED)
    Dbg.printf("OTA: failed (%d) %s\n", httpUpdate.getLastError(), httpUpdate.getLastErrorString().c_str());
  else if (ret == HTTP_UPDATE_NO_UPDATES)
    Dbg.println("OTA: server reports no update");
}

// =============================================================================
//   Voltbench: NVS, gzip serving, WebSocket, captive portal, MQTT
//   Include AFTER all shared symbols are defined above.
// =============================================================================
#include "firmware-additions.h"

static bool ota_force_flag = false;
static void ota_task_fn(void *pv) {
  perform_ota(ota_force_flag, vb.ota_ssl, vb.ota_url);
  ota_force_flag = false;
  ota_busy = false;
  vTaskDelete(NULL);
}
// 16 KB stack — TLS (WiFiClientSecure) handshake/buffers are stack-hungry.
void perform_ota_tasked(bool force) {
  if (ota_busy) { Dbg.println("OTA: busy — request ignored"); return; }
  ota_busy = true;
  ota_force_flag = force;
  xTaskCreatePinnedToCore(ota_task_fn, "otaTask", 16384, NULL, 5, NULL, 0);
}
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
void loop() {
  vb_loop();                      // DNS captive, WebSocket push, MQTT
  remote_debug_pump();            // telnet + browser log stream

  // Bench console over USB (same commands as telnet): v<volts> o1 o0 m c ?
  // Non-blocking accumulator (readStringUntil would stall loop() up to 1 s
  // per partially-typed line).
  static String usbin;
  while (Serial.available()) {
    char ch = (char)Serial.read();
    if (ch == '\n' || ch == '\r') {
      if (usbin.length()) { console_exec(usbin, Dbg); usbin = ""; }
    } else if (usbin.length() < 64) usbin += ch;
  }
  // Periodic telemetry while output 1 is on -> fans out to USB, telnet, web log.
  static uint32_t t_con = 0;
  if (psState.output1 && millis() - t_con > 1000) {
    t_con = millis();
    Dbg.printf("[con] set=%umV meas=%umV disp=%umV state=%u R=%dohm\n",
               g_setpoint_mV, g_measured_mV, g_display_mV, g_vctrl_state, (int)dpCalcR());
  }
  delay(2);
}

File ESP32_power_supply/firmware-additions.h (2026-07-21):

// =============================================================================
// firmware-additions.h
//
// Companion for the Voltbench webpage. Adds:
//   1. Preferences (NVS) for all settings + saved Wi-Fi credentials
//   2. gzip-compressed PROGMEM HTML served with Content-Encoding: gzip
//   3. AsyncWebSocket push of /status (drops idle polling)
//   4. Optional bearer-token auth (X-Auth header)
//   5. Captive-portal AP fallback when no SSID can connect
//   6. PubSubClient MQTT bridge
//
// Include this header AFTER the existing sketch globals (struct State, globals,
// setOutput, setVoltage, apply_command) are defined.
// =============================================================================
#pragma once

#include <Preferences.h>
#include <ArduinoJson.h>
#include <ESPAsyncWebServer.h>
#include <AsyncJson.h>
#include <DNSServer.h>
#include <WiFi.h>
#include <esp_system.h>
#include <esp_random.h>
#include <PubSubClient.h>
#include <WiFiClient.h>

// Gzip-compressed index page (generated by PowerShell, see web_page.h)
extern const uint8_t  index_html_gz[]     PROGMEM;
extern const size_t   index_html_gz_len;

// Forward declarations — defined in the main sketch
extern AsyncWebServer server;
extern struct State   psState;
extern volatile uint32_t g_measured_mV;
extern volatile uint32_t g_setpoint_mV;
extern void setOutput(uint8_t output, bool state);
extern void setVoltage(float voltage);
extern bool apply_command(const String &action, uint8_t ch, float val);
extern volatile uint32_t g_5v_mV, g_3v3_mV;   // rails sampled by the control task

// OTA state (defined in main sketch, near perform_ota)
extern volatile bool     ota_busy;
extern String            ota_latest;
extern volatile uint32_t ota_checked_at;
extern String ota_fetch_latest(const String &ota_url, bool verify_ssl);

// Voltage-control state (defined in main sketch)
extern volatile uint8_t  g_vctrl_state;

// Output-1 calibration map + smoothed display (defined in main sketch)
extern uint16_t          g_cal_mv[128];
extern volatile bool     g_cal_valid;
extern volatile bool     g_cal_sweep_req;
extern volatile uint32_t g_display_mV;

// =============================================================================
//   WiFi manager — globals shared between manager task, scan task, HTTP handlers
// =============================================================================
static volatile int16_t  g_scan_result    = WIFI_SCAN_FAILED; // -2=idle,-1=running,>=0=count
static volatile bool     g_scan_busy      = false;
static volatile uint32_t g_scan_done_at   = 0;     // millis() at last scan completion (W5 cache)
static volatile bool     g_wifi_conn_busy = false; // true during any connection attempt
static SemaphoreHandle_t g_wifi_ready     = nullptr; // given when initial WiFi phase ends

// Forward declaration (defined in captive portal section below)
void vb_start_captive_ap();

// ---------- Scan task ----------
// Runs WiFi.scanNetworks() (blocking) on its own stack so it never executes on
// the lwIP / AsyncWebServer task.  CRITICAL: esp_wifi_connect() called during an
// active scan silently kills the scan and never fires WIFI_EVENT_SCAN_DONE —
// waitStatusBits then blocks for 60 s.  vb_trigger_scan() guards against this.
static void _wfScanTask(void*) {
  WiFi.scanDelete();
  int16_t n = WiFi.scanNetworks(false, true);  // blocking, include hidden SSIDs
  g_scan_result = (n < 0) ? WIFI_SCAN_FAILED : n;
  g_scan_done_at = millis();
  g_scan_busy   = false;
  vTaskDelete(NULL);
}

static void vb_trigger_scan() {
  if (g_scan_busy || g_wifi_conn_busy) return;
  g_scan_busy   = true;
  g_scan_result = WIFI_SCAN_RUNNING;
  xTaskCreate(_wfScanTask, "wfscan", 4096, nullptr, 1, nullptr);
}

// =============================================================================
//   Settings + persistent storage
// =============================================================================
struct VBSettings {
  String   mdns          = "voltbench";
  bool     require_login = true;
  String   password      = "admin";
  String   auth_token    = "";

  String   ota_url       = "https://updates.example.com/voltbench/";
  bool     ota_ssl       = true;
  bool     ota_auto      = true;

  bool     exp_fast      = true;
  bool     exp_smooth    = false;
  bool     exp_dial      = false;

  bool     mqtt_en       = false;
  String   mqtt_host     = "";
  uint16_t mqtt_port     = 1883;
  String   mqtt_user     = "";
  String   mqtt_pass     = "";
  String   mqtt_topic    = "voltbench";

  static const uint8_t MAX_SSID = 4;
  String   ssid[MAX_SSID];
  String   pass[MAX_SSID];
} vb;

Preferences vbPrefs;

// One mutex around every vbPrefs.begin()/end() pair — cal_save runs on the
// control task while web handlers save settings on the AsyncTCP task.
SemaphoreHandle_t g_nvs_mux = nullptr;
static void nvs_lock()   { xSemaphoreTake(g_nvs_mux, portMAX_DELAY); }
static void nvs_unlock() { xSemaphoreGive(g_nvs_mux); }

void vb_load() {
  nvs_lock();
  vbPrefs.begin("voltbench", true);
  vb.mdns          = vbPrefs.getString ("mdns",          vb.mdns);
  vb.require_login = vbPrefs.getBool   ("req_login",     vb.require_login);
  vb.password      = vbPrefs.getString ("password",      vb.password);
  vb.ota_url       = vbPrefs.getString ("ota_url",       vb.ota_url);
  vb.ota_ssl       = vbPrefs.getBool   ("ota_ssl",       vb.ota_ssl);
  vb.ota_auto      = vbPrefs.getBool   ("ota_auto",      vb.ota_auto);
  vb.exp_fast      = vbPrefs.getBool   ("e_fast",        vb.exp_fast);
  vb.exp_smooth    = vbPrefs.getBool   ("e_smooth",      vb.exp_smooth);
  vb.exp_dial      = vbPrefs.getBool   ("e_dial",        vb.exp_dial);
  vb.mqtt_en       = vbPrefs.getBool   ("mq_en",         vb.mqtt_en);
  vb.mqtt_host     = vbPrefs.getString ("mq_host",       vb.mqtt_host);
  vb.mqtt_port     = vbPrefs.getUShort ("mq_port",       vb.mqtt_port);
  vb.mqtt_user     = vbPrefs.getString ("mq_user",       vb.mqtt_user);
  vb.mqtt_pass     = vbPrefs.getString ("mq_pass",       vb.mqtt_pass);
  vb.mqtt_topic    = vbPrefs.getString ("mq_topic",      vb.mqtt_topic);
  for (uint8_t i = 0; i < VBSettings::MAX_SSID; i++) {
    vb.ssid[i] = vbPrefs.getString(("ssid" + String(i)).c_str(), "");
    vb.pass[i] = vbPrefs.getString(("pass" + String(i)).c_str(), "");
  }
  vb.auth_token    = vbPrefs.getString ("token",         vb.auth_token);
  vbPrefs.end();
  nvs_unlock();
}
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

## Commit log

2025-10-26 Added Hardware files and board files
    [esp32_power_supply.brd, esp32_power_supply.sch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]
2025-10-26 Added software for the Power Supply
2026-05-15 fix: correct inverted voltage tolerance check in set_voltage
    [ESP32_power_supply.ino]
2026-05-15 fix: reset WIFI_STATUS on disconnect so reconnect retries actually run
    [ESP32_power_supply.ino]
2026-05-15 fix: revert unauthorized version bump (keep at 0.0.1)
    [ESP32_power_supply.ino]
2026-05-15 fix: remove control_voltage global to eliminate async task race condition
    [ESP32_power_supply.ino]
2026-05-15 fix: no_network counter is now local so repeated calls retry properly
    [ESP32_power_supply.ino]
2026-05-15 fix: re-enable 5-sample moving average for VV ADC channel
    [ESP32_power_supply.ino]
2026-05-15 fix: use signed intermediate for resistance calc to prevent uint underflow
    - Replace uint64_t direct calculation with signed long intermediate
    - Add underflow protection: clamp to 0 if result is negative
    - Remove unused step_jump variable
    [ESP32_power_supply.ino]
2026-05-15 fix: replace expired DST Root CA X3 with ISRG Root X1, enforce HTTPS OTA URLs
    [ESP32_power_supply.ino]
2026-05-15 fix: add div-by-zero guard in set_voltage and unify tolerance comparison
    - Add early-return guard in set_voltage() to prevent division by zero when target_mV <= DC_V_REF (1235 mV)
    - Change tolerance comparison from < to <= in the set_voltage() loop to match fine_tune_volt() consistency
    [ESP32_power_supply.ino]
2026-05-15 feat: raise slider max to 19V and add 15V/19V quick-set buttons
2026-05-15 fix: rewrite voltage control to prevent runaway to max voltage
    [ESP32_power_supply.ino]
2026-05-15 feat: non-blocking FreeRTOS voltage control with measured voltage in status
    - Add four volatile globals (g_target_mV, g_setpoint_mV, g_measured_mV,
    g_ctrl_output1) for lock-free task communication
    - Add voltageControlTask (core 0, priority 2): formula-based set followed
    by fine-tune only when R2 > 3000 Ω (Vout ≤ ~5 V); fine-tune aborts if
    a new target arrives or voltage region is too coarse
    - Remove blocking fine_tune_volt(), set_voltage(), read_vv_fresh(),
    setVoltage() — all replaced by the task
    - /control handler now writes globals and returns immediately (non-blocking)
    - /status now returns g_measured_mV (actual) and g_setpoint_mV for browser
    - setOutput() mirrors output1 sta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
    [ESP32_power_supply.ino]
2026-05-15 feat: browser shows measured + setpoint voltage, 1 s poll, slider drag guard
    - Add "Set: X.XV" label (setpoint1 span) below Output 1 measured display
    - Reduce /status poll from 2000 ms to 1000 ms
    - Guard measured display update with sliderDragging flag to prevent
    flicker while user is dragging the slider
    - Debounce setPresetVoltage buttons at 300 ms (same as slider)
2026-05-15 feat: Voltbench UI — full redesign with Dashboard/History/Settings tabs
    Web UI (Power Supply.html → gzip web_page.h, 82KB→22KB):
    - "Voltbench" dark theme with design tokens, Inter + JetBrains Mono fonts
    - 3-tab navigation: Dashboard (live outputs), History (canvas graph +
    event log), Settings (device, WiFi, security, OTA, guards, MQTT)
    - WebSocket live push at 4 Hz (falls back to polling)
    - Login/auth with bearer token (X-Auth header), stored in sessionStorage
    - Customisable voltage presets per channel (localStorage), drag-to-set
    rotary dial input (experimental), Δ vs set-point indicator
    - "All off" button, toast notifications, CSV export, history window selector
    - Slider range up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
    [ESP32_power_supply.ino, firmware-additions.h]
2026-05-15 fix: resolve VBSettings forward-decl conflict and BOM in web_page.h
    Move ota_task_fn/perform_ota_tasked after #include firmware-additions.h
    so VBSettings vb is already in global scope; drop the conflicting local
    extern. Regenerate web_page.h without UTF-8 BOM.
    [ESP32_power_supply.ino]
2026-05-15 fix: replace HttpsOTAUpdate with built-in HTTPUpdate to reduce flash usage
    HttpsOTAUpdate bundles its own TLS/OTA stack (~100-150 KB extra).
    Switch to ESP32 core HTTPUpdate + WiFiClientSecure (shared mbedTLS,
    no added size). Drops the 3 KB ISRG cert string and HttpEvent stub.
    verify_ssl=true uses setInsecure() (encrypts but skips chain validation).
    [ESP32_power_supply.ino]
2026-05-15 feat: add custom 4MB partition table (1.75MB app, OTA-capable)
    Default and 'minimal' schemes only give 1.25-1.3MB to the app partition.
    Sketch is 1.34MB, so it overflows. Custom table gives 1.75MB per app
    partition while keeping OTA support (app0 + app1) and 448KB SPIFFS.
    Arduino IDE auto-detects partitions.csv in the sketch folder.
    [partitions.csv]
2026-05-15 feat: fix WiFi scan, voltage display, add WS commands + help page; optimize size
    Firmware:
    - captive AP now uses WIFI_AP_STA so scanNetworks() works in AP mode
    - vb_fill_status uses read_VV_volt() (5-sample smooth) not raw g_measured_mV
    - vb_on_ws_event processes incoming JSON commands (toggle/set_voltage/
    set_ilimit/all_off/clear_trip) with auth-token check; replies with status
    - Add #pragma GCC optimize("Os") to sketch (~50-80 KB savings)
    - Drop WiFiClientSecure; OTA now HTTP-only (removes one TLS code path)
    Browser:
    - wifiScan() polls firmware with 700 ms backoff until scan completes
    - EMA smoothing (alpha=0.2) applied when exp.smooth is enabled
    - WebSocket help card added to Settings: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
    [ESP32_power_supply.ino, firmware-additions.h]
2026-05-15 fix: ADC attenuation, security revert, fine-tune accuracy
    - Add analogSetAttenuation(ADC_11db) — fixes voltage display always
    showing <4 V by extending ADC range to 2500 mV (covers up to ~27.5 V
    on the ×11 divider) and eliminating saturation above ~10.4 V
    - Switch vb_fill_status() to g_measured_mV — eliminates concurrent ADC
    access between voltageControlTask and the AsyncWebServer task
    - Increase voltageControlTask FINE_TUNE_MAX from 3 to 8 iterations for
    better convergence at 3.3 V / 5 V setpoints
    - Guard loadInfo() settings form behind settingsTabActive flag — prevents
    10-second periodic refresh from overwriting unsaved security/settings
    changes while user is on the Sett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
    [ESP32_power_supply.ino, firmware-additions.h]
2026-05-15 fix: correct ADC multiplier ×48 (was ×11) and history timestamps
    - CH1 voltage divider is 47K:1K (×48 scale), not 10K:1K (×11).
    All four ADC read sites in .ino updated; fixes displayed voltage
    reading ~1/4 of actual output.
    - History CSV timestamps now use Date.now() (wall-clock) instead of
    s.ts (device uptime ms since boot), eliminating 1970-01-01 dates.
    - Regenerated web_page.h from updated HTML source.
    [ESP32_power_supply.ino]
2026-05-15 revert: restore ADC multiplier to ×11 (10K:1K divider)
    Previous commit wrongly changed to ×48 based on schematic showing R1=47K,
    but physical hardware has 10K and the original firmware was working correctly.
    The setup() comment "supports output up to ~27.5V" confirms ×11 (2500mV×11).
    [ESP32_power_supply.ino]
2026-05-15 fix: remove fine-tune loop, freeze pot on formula set, restore x48
    - Pot is now written once (formula) on target change then left alone.
    No iterative wiper adjustments that cause hunting at low voltages.
    - ADC averaging increased from 3 to 8 samples in both the post-set
    read and the idle monitor to reduce display noise at ~1V.
    - Restores x48 multiplier (confirmed correct by hardware measurement).
    [ESP32_power_supply.ino]
2026-05-15 feat: PID voltage controller with relay auto-tune
    - voltageControlTask is now a state machine: formula set → settling
    (300ms) → PID correction loop → converged (frozen). Pot only moves
    when actively correcting; freezes as soon as error < 100mV × 3 reads.
    - PID is linearised: output is voltage correction (mV), converted to
    ΔR using local dV/dR = −Vref×Rtop/R² so gains stay consistent
    across the full voltage range without hand-tuning per setpoint.
    - Anti-windup clamps integral to ±3V equivalent contribution.
    - Relay auto-tune (Åström-Hägglund): POST /api/pid/tune triggers a
    relay test at the current setpoint. Adaptive relay amplitude targets
    ~150mV swing (2-8 MCP401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
    [ESP32_power_supply.ino, firmware-additions.h]
2026-05-15 fix: cast volatile uint8_t for min() template deduction
    [firmware-additions.h]
2026-05-15 fix: remove float-printf from PID/autotune to recover ~2-3KB flash
    Float format specifiers (%.0f, %.3f etc.) in Serial.printf pull in the
    full float-printf library. Replaced with integer x1000 output or removed
    debug prints entirely. Also dropped the redundant /api/pid GET endpoint
    (info already available via /api/info).
    [ESP32_power_supply.ino, firmware-additions.h]
2026-05-15 perf: PID convergence under 1s via faster timing
    - ADC: 8x10ms=80ms -> 4x5ms=20ms (LM2596 settled well within 5ms)
    - Settle wait: 300ms -> 100ms
    - PID loop delay: 200ms -> 50ms when active, 200ms when monitoring
    - Convergence count: 3 -> 2 reads
    - Fast-path: if formula lands within 100mV on first read, converge
    immediately without running PID iterations at all
    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
2026-05-16 docs: add comprehensive README with live screenshots
    Covers hardware BOM, pin map, feedback network, firmware build
    instructions, REST API, WebSocket, MQTT, OTA, architecture diagram,
    accuracy table (measured on hardware), and troubleshooting.
    Screenshots captured from live device at 192.168.1.21 (voltbench.local)
    during a full feature verification run.
2026-05-16 ui: display voltages as x.x V (1 decimal place)
2026-05-16 feat: add control modes + no-overvoltage voltage control
    Voltage control modes (quick/continuous/timed):
    - Quick: freezes wiper on 2 consecutive readings <150mV error, caches R per target
    - Continuous: keeps PID active until <100mV for 2 consecutive readings
    - Timed: PID runs for configurable timeout, freezes at best-seen R
    - g_ctrl_mode / g_ctrl_timeout_ms globals; persisted via NVS; exposed in /api/info
    and /api/settings; ctrl_mode reported in /api/status
    No-overvoltage control (hardware-side):
    - Pre-discharge: if measured > target+300mV on setpoint change, sets max R first
    and waits until voltage drops below target+300mV before applying formula R
    - Conservative start: formula uses ta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
    [ESP32_power_supply.ino, firmware-additions.h]
2026-05-16 feat(ui): control mode selector, settings guard, fix api() Content-Type
    Control mode UI:
    - Control mode select (Quick / Continuous / Timed) added to PID card
    - Timed timeout dropdown (1/3/5/10s) shown only when Timed is selected
    - Save button now posts {pid:{kp,ki,kd}, ctrl:{mode,timeout_ms}} together
    - loadInfo() syncs ctrl.mode and ctrl.timeout_ms from /api/info response
    Settings form guard:
    - settingsTabActive flag tracks whether user is on the Settings tab
    - loadInfo() skips overwriting form inputs while settingsTabActive is true,
    preventing the 10-second periodic refresh from reverting unsaved changes
    - Post-save handler temporarily clears flag to force a one-time re-sync
    Critical b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
2026-05-17 docs: add v2 hardware design document
    Full hardware design for two-channel bench PSU:
    MP1584 buck + PMOS LDO (FQP27P06 + LM358) + MCP4728 quad DAC +
    INA219 current/voltage sensing. Includes schematics, BOM,
    thermal analysis, PCB notes, and firmware interface.
2026-05-18 fix: always refresh credential.h SSIDs in NVS on every boot
    Remove the first-boot-only guard so hardcoded credentials from
    credential.h are written to NVS slots on every reset via
    vb_remember_wifi() (which deduplicates). Ensures the device
    picks up updated credentials without requiring a factory reset.
    [ESP32_power_supply.ino]
2026-05-18 fix: rewrite WiFi manager as FreeRTOS task; fix WiFi scan blocking
    Root cause: esp_wifi_connect() called during an active scan silently
    kills the scan with no WIFI_EVENT_SCAN_DONE event, leaving
    waitStatusBits() blocked for 60 s (the scan task timeout). This
    was triggered by vb_loop() calling vb_try_saved_wifi() immediately
    on the first loop iteration (lastRetry=0, millis()>30000 after
    the initial connection attempts).
    Changes:
    - Replace vb_try_saved_wifi() + vb_loop() WiFi retry with a
    dedicated wifiMgrTask (FreeRTOS, 8 KB stack, priority 2) that
    owns the full connection lifecycle
    - Reduce per-SSID timeout: 5 s (was 12 s) — AP starts in ≤20 s
    - wifiMgrTask waits for g_scan_busy==fa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
    [firmware-additions.h]
2026-06-15 feat: stable voltage control, calibration map, live UI, WiFi flash + remote debug
    Output-1 control:
    - Replace the PID (which chased ADC noise and dithered the output between
    steps) with a deterministic best-step + freeze controller. Direct-I2C wiper
    writes bypass SW_MCP4017::setSteps()'s 4x-per-call Serial spam.
    - Heavily filter ADC feedback (50 samples / ~200 ms = ~10 mains cycles) to
    reject hum on the high-Z 47K:1K divider node.
    - Calibration map: wiper sweep -> step->mV table, isotonic/PAVA-smoothed and
    persisted to NVS; set-voltage = map lookup + live +/-2-step trim + freeze.
    Lands within +/-100 mV across 3.3-13.5 V (was 200-660 mV off via formula).
    Triggers: serial 'm', POST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
    [ESP32_power_supply.ino, firmware-additions.h]
2026-06-16 refactor: remove dead code
    - Drop unused SW_MCP4017 dependency + i2cDP object (wiper driven by direct I2C).
    - Remove unused read_VV_volt() and its extern.
    - Remove disabled ArduinoOTA (begin() hangs alongside AsyncTCP; web-upload OTA
    is the working WiFi-flash path) — include, begin helper, commented loop calls.
    - Remove write-only g_ctrl_output1.
    Also removed the _ota/ build-artifact dir (git-ignored).
2026-07-21 feat!: remove vestigial PID subsystem (no control loop ever consumed the gains)
2026-07-21 feat!: remove stub OCP/OTP guards and fake current telemetry (no sensing hardware)
2026-07-21 fix: bounds-check setOutput, clamp setVoltage, unify all command entry points through apply_command()
    [ESP32_power_supply.ino, firmware-additions.h]
2026-07-21 feat(ui): remove PID/guards/current UI, gate demo to file://, escape SSIDs, honest OTA card, 2-decimal readout, real vmax
2026-07-21 feat: deadbeat predict-verify-correct controller; median-of-5 display; rails sampled by control task
    [ESP32_power_supply.ino, firmware-additions.h]
2026-07-21 feat(ui): calibration card, web-upload OTA with real progress, honest pull-OTA flow, live device log pane
2026-07-21 fix(wifi): recover after failed join, serialize connect attempts, save creds only on success, seed credential.h once, cache scans 20s
    [ESP32_power_supply.ino, firmware-additions.h]
2026-07-21 fix: keep lower-voltage step when both verify samples overvolt; self-heal map on step-back; seed display median at boot
    [ESP32_power_supply.ino]
2026-07-21 fix(wifi): handle xTaskCreate failure in connect handler (stuck busy flag, leak, false 200)
    [firmware-additions.h]
2026-07-21 fix(nvs): mutex around Preferences access; persist auth token across reboots
    [ESP32_power_supply.ino, firmware-additions.h]
2026-07-21 fix(ui): survive boot-time /api/info failure (info stays null) — render app with Offline pill instead of blank page
2026-07-21 fix: all logs via Dbg ring, non-blocking USB console, logws cleanup, MQTT socket timeouts
    [ESP32_power_supply.ino, firmware-additions.h]
2026-07-21 feat(api): split info by auth, guard scan/cal, POST reboot, no-cache UI, report calibrated vmax
    [firmware-additions.h]
2026-07-21 chore: final-review fixes — stale guard/NVS comments, WS output range check, dead externs
    [ESP32_power_supply.ino, firmware-additions.h]
2026-07-21 fix(ui): refresh CH1 slider ceiling from vmax after calibration sweep
2026-07-21 fix: loop() wedge — HWCDC write underflow-blocks on stale CDC session (core 3.2.1 bug); bound all loop()-side TX
    - DbgPrint writes at most Serial.availableForWrite() bytes: HWCDC::write's
    retry counter underflows (tries-- from 0) when the post-esptool CDC session
    is stale-connected and the TX ring is full, blocking loopTask ~forever.
    Root-caused live: telnet/WS dead, HTTP+control task alive, only after
    esptool flashes, onset when output-ON telemetry fills the ring.
    - vb_push_status/logws pump: skip textAll unless availableForWriteAll()
    (library-recommended guard; a non-ACKing client must not back up TX).
    - telnet flush budgeted to availableForWrite() (was unbounded byte-wise).
    -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
    [ESP32_power_supply.ino, firmware-additions.h]
2026-07-21 fix: calibrate VV ADC divider scale 48.0 -> 47.40 (bench DMM 5-point fit: +1.25% pure gain error, zero offset)
    Before (DMM vs set): 13.5V read -710 mV low, 15V -420, 9V -200.
    After re-sweep: all setpoints within one wiper step (worst -354 mV at
    15V = quantization floor; 13.5V now +103 mV).
    [ESP32_power_supply.ino]
2026-07-21 feat(ui): landing preview — show the calibrated step the hardware will actually land on while typing/dragging
    Mirrors the firmware's choice (nearest map step not exceeding target+300 mV)
    from the /api/cal/status ladder; hidden when within 60 mV of the target.
    Makes top-of-range quantization (~0.9 V/step) visible before hitting Set.
2026-07-21 feat(ui): snap Set to nearest calibrated step (input+slider updated); channel-coloured on/off event markers in history (solid=on, dashed=off, amber dotted=set)
2026-07-22 fix(ui): send auth token on wifi scan — 3.0.0's VB_REQUIRE_AUTH on /api/wifi/scan 401'd the GUI's bare fetch, so scanning silently returned nothing on login-enabled devices; bump to 3.0.1
    [ESP32_power_supply.ino]
2026-07-27 docs: add AUTOMATION.md — API/test reference for driving the device from other sessions

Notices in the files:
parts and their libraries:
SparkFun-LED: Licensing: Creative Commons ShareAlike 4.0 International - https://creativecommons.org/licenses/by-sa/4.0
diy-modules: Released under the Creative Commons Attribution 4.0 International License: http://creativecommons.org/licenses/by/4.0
